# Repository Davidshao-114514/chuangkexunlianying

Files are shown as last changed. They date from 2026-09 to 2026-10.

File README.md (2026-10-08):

# 磁吸焊接辅助手电 · 开源学习包

> 一个「从零到整机」的嵌入式硬件学习包：**不是又一块开发板，而是一个完整产品**
> 一吸即用、指哪照哪的焊接照明工具 —— 硬件 + 固件 + 结构 + 测试，全链路开源。





---

## 这是什么？

一块常见的开发板（Arduino / 各类核心板）能教你**外设怎么用**：点亮 LED、读按键、刷屏、跑 PWM。
但学完之后，很多人仍然答不上这些问题：

- 电池设备为什么敢**不用稳压器**直接给 MCU 供电？那怎么测电池电压？
- 驱动芯片手册写「调光 100Hz–10kHz」，到底该选多少？选错会怎样？
- 按键只有 3 个，怎么覆盖 8 项功能？吸附检测为什么要 100ms 去抖而按键只要 15ms？
- 关机后怎么做到「按键唤醒 + 唤醒不花屏 + 松手不重启」？
- 断电后怎么记住上次亮度，又不会记住"过期的设置"？

**这个学习包就是这些问题的答案**——而且每一个答案都附带**真实踩坑过程**（`docs/08`）。
它把「磁吸焊接辅助手电」这个真实项目完整开源：从电源链路到 PWM 调光、
从磁吸检测到低功耗、从原理图到 3D 外壳，全部可复现。

### 与「传统开发板」的差别

| 维度 | 传统开发板 / Arduino | 本学习包 |
|---|---|---|
| 学习对象 | 单个外设 Demo | **完整产品链路**（电源→主控→输出→人机→结构） |
| 代码规模 | 示例 sketch / 单个 .c | **12 个 BSP 模块 + 1ms 分频调度**（Flash 12KB / RAM 1.1KB） |
| 硬件决策 | 板载已定，无需思考 | **每个决策都有理由**（电池直供、BGR 反推、8kHz、3 键、100ms 去抖） |
| 产出物 | 一个会闪的灯 | **一台能用的整机**（含外壳、按键帽、装配、测试表） |
| 复现成本 | 低价但要买全套模块 | **BOM ≈ ¥45 级**，通用件 + 3D 打印结构 + 驱动可 pin-to-pin 替换 |
| 工程习惯 | 少涉及 | 低功耗时序、去抖、抗噪、掉电记忆、状态机、可维护分层 |
| 真实经验 | 很少有踩坑记录 | **完整踩坑实录**（OLED 四轮点亮、ADC 三段排查、频率五次迭代…） |
| 教学适配 | 课程实验 | **项目式学习**：8 个学习模块、检查点、验收判据 |

> 一句话：**开发板教你「怎么用芯片」，这个学习包教你「怎么做产品」。**

---

## 快速开始

```text
1. 阅读   docs/01-为什么做这个学习包.md     ← 先看这里（5 分钟）
2. 概览   docs/系统框图.png                 ← 一张图看懂整机
3. 硬件   docs/03-硬件设计说明.md           ← 供电/引脚/磁吸接口/BOM
4. 固件   docs/04-固件架构说明.md           ← 模块划分、按键语义、调度、低功耗
5. 踩坑   docs/08-开发踩坑实录.md           ← 强烈建议先读（省几周时间）
6. 动手   docs/05-复现指南.md               ← 采购→打样→焊接→烧录→调试
7. 验收   docs/06-测试与验收.md             ← 指标与测试方法
```

**编译烧录（两种型号，一行宏切换）：**

```c
/* USER/inc/app_config.h */
#define APP_PRODUCT_VARIANT   PRODUCT_VARIANT_EXTERNAL   /* 外挂款：磁吸 LED + 吸附检测 */
/* 或 */                    /* PRODUCT_VARIANT_BUILTIN —— 内置款：内置 LED，无需检测 */
```

Keil MDK5 + **Arm Compiler 6**（需装 `WHXY.CW32L010_DFP 1.0.2`）打开 `MDK/Project.uvprojx`
→ 改宏 → 编译（预期 ≈12KB Flash / ≈1.1KB RAM）→ SWD 烧录 → 上电自检。

---

## 仓库结构

```text
├── USER/                     应用固件（分层 BSP，重点学习对象）
│   ├── inc/                  bsp_pin.h（引脚唯一映射）/ app_config.h（型号开关）/ …
│   └── src/                  main.c（按键状态机/电池状态机/UI）
│                             bsp_pwm.c（8kHz 6000 级双路调光）
│                             bsp_detect.c（磁吸检测 100ms 去抖）
│                             bsp_power.c（STOP 休眠 + 上升沿唤醒）
│                             bsp_save.c（Flash 亮度记忆 + RTC 1h 窗口）
│                             bsp_adc.c（BGR 反推电压）/ bsp_oled.c（CH1115 88×48）/ …
├── MDK/                      Keil MDK5 工程（Project.uvprojx）
├── 工程文件夹/
│   ├── UserApp/              完整工程（含标准库 + DEVELOPMENT_SUMMARY.md 开发总结）
│   ├── BOM_TYPE-A_PCB2_*.xlsx   物料清单（34 行 / 56 位号）
│   ├── TYPE-A.epro2          立创EDA 专业版工程（原理图 + PCB）
│   ├── CW32L010.pdf          主控数据手册
│   └── 3D外壳/               外壳 / 盖子 / 按键帽 / 散热片（STEP + SolidWorks 源）
├── docs/                     学习文档（本学习包核心）
└── LICENSE                   MIT
```

---

## 硬核参数（都能在文档里找到依据与踩坑过程）

| 项目 | 参数 | 出处 |
|---|---|---|
| 主控 | CW32L010F8（Cortex-M0+，TSSOP-20，64KB Flash / 4KB RAM），HSI 48MHz | `docs/03` §3 |
| 供电 | **锂电池直供 MCU**（无稳压器、无外部晶振）；CE 控制 3V3 轨（磁吸口） | `docs/03` §2 |
| 调光 | 双路独立 PWM，**8kHz**，**6000 级**（ARR=5999），软件千分比，步进 0.5%，下限 3% | `docs/04` §3 |
| 驱动 | **RY3730 ×2**（pin-to-pin 可换 SY7200），手册推荐 100Hz–10kHz | `docs/03` §6 |
| 磁吸接口 | 4pin/组：3V3 / GND / LED− / **DET**；吸附才点亮，**脱落即灭** | `docs/03` §4 |
| 吸附检测 | PA01/PA00（复用 OSC±），**100ms 去抖**（按键只需 15ms） | `docs/03` §4.3 |
| 按键 | **3 键**（PB03 开关机 / PA04 亮度− / PA05 亮度+），高有效（外部下拉） | `docs/04` §2 |
| 交互 | 单击 / 长按（≥300ms，三段加速）/ 双击（≤350ms，切对象·切模式） | `docs/04` §2 |
| 电量 | **无外部电路**：内部 BGR 1.2V 反推 VDD + 成对交替采样 + IIR | `docs/03` §5 |
| 电池保护 | LOW <3350mV（回 3400 解除）/ PROTECT <3200mV 关断，2s 确认 + 告警页 | `docs/04` §6 |
| 显示 | 0.5" **CH1115** 88×48，软件 I2C（PB05/PB06，地址 0x3C） | `docs/03` §7 |
| 掉电记忆 | Flash 第 127 页，两组亮度 + RTC 时间戳，**1 小时恢复窗口** | `docs/04` §7 |
| 低功耗 | 关机 = CE 断电 + STOP；PB03 **上升沿**唤醒 + 500ms 延迟初始化 + 吞咽窗口 | `docs/04` §5 |
| 资源占用 | Flash ≈12KB / RAM ≈1.1KB，编译 0 错 0 警告 | `docs/04` §10 |
| BOM | ≈ ¥45 级整机（PCBA 通用件 + 磁吸机构 + 3D 打印外壳） | `docs/03` §8 |

---

## 学习路径（8 个模块 + 踩坑实录）

| # | 模块 | 你会获得 | 文档 |
|---|---|---|---|
| 1 | 看懂整机与系统框图 | 电源域/主控域/输出域/人机域的分区思维 | [系统框图](docs/系统框图.png)、[硬件 §1](docs/03-硬件设计说明.md) |
| 2 | 电源链路与软开关 | 电池直供的取舍、CE 控 3V3、关机为何要 STOP | [硬件 §2](docs/03-硬件设计说明.md)、[固件 §5](docs/04-固件架构说明.md) |
| 3 | GPIO 与按键语义 | 高有效 + 外部下拉、15ms 去抖、单击/长按/双击状态机 | [固件 §2](docs/04-固件架构说明.md) |
| 4 | PWM 与调光 | 8kHz/6000 级的推导、最低占空比下限为何是 3% | [固件 §3](docs/04-固件架构说明.md)、[硬件 §6](docs/03-硬件设计说明.md) |
| 5 | 磁吸检测与保护 | 复用引脚、100ms 去抖、"脱落即灭"的安全逻辑 | [固件 §4](docs/04-固件架构说明.md)、[硬件 §4](docs/03-硬件设计说明.md) |
| 6 | 采样与电池保护状态机 | BGR 绝对参考、成对采样、滞回阈值与告警 | [硬件 §5](docs/03-硬件设计说明.md)、[固件 §6](docs/04-固件架构说明.md) |
| 7 | 低功耗与掉电记忆 | 唤醒沿/消抖窗/延迟初始化、Flash 记忆时间窗 | [固件 §5 §7](docs/04-固件架构说明.md) |
| 8 | 结构、装配与测试 | 磁吸底座+按键帽装配、吸附力/漂移/温升验收 | [硬件 §9](docs/03-硬件设计说明.md)、[测试](docs/06-测试与验收.md) |
| ★ | **开发踩坑实录** | OLED 四轮点亮、ADC 三段排查、PWM 五次迭代、休眠四个连环坑 | [docs/08](docs/08-开发踩坑实录.md) |

---

## 共建共享（Contributing）

这个学习包**欢迎任何人改进**，无论你是学生、教师还是工程师：

- 🐛 **报问题 / 提建议**：开 Issue，说明环境与复现步骤
- 🔧 **提交改进**：Fork → 分支 → PR（详见 [CONTRIBUTING.md](CONTRIBUTING.md)）
- 📚 **分享你的扩展**：新外壳、新灯组、新交互、移植到别的 MCU——都欢迎
- 🎓 **教学复用**：教师/社团可直接把 [docs/07](docs/07-教学设计说明.md) 当课程包（含课时与检查点）
- 🧰 **留下你的坑**：把你的踩坑记录补进 [docs/08](docs/08-开发踩坑实录.md)——这比代码更珍贵

> 我们相信：**开源不是把代码扔出去，而是让别人能稳定复现、并能在此基础上继续走远。**
> 因此本项目对每个焊接步骤、每个参数都注明「为什么」，并把低成本复现作为硬指标。

---

## 许可

- 代码与文档：**MIT**（见 [LICENSE](LICENSE)）
- 硬件设计（原理图 / PCB / 结构）：MIT 同样适用；转载与二次发布请保留出处
- 引用到的第三方资源（主控数据手册、标准库、屏厂初始化序列）版权归原作者所有

---

## 致谢

- **指导老师**：提供 CW32L010 开发板与工程框架，本学习包的固件架构建立在其规范之上
- **仿真跑不队**：邵子中、李昊桐、姜亚楷 —— 硬件选型、结构设计、固件迭代与全部测试数据
- 以及每一位愿意在此基础上继续共建的人 ✦

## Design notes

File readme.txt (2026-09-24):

UserApp - CW32L010F8 应用框架
================================
基于 CW32L010 标准库例程 (参考 GPIO/gpio_blink 工程结构),
软件开关支持外挂款/内置款两种型号, 见 USER\inc\app_config.h。

型号区别 (烧录前修改 app_config.h 的 APP_PRODUCT_VARIANT, 重新编译):
  外挂款 EXTERNAL (默认):
    - 磁吸 4pin 外接 LED (3V3/GND/LED-/DET), 吸附检测: 高=已连接
    - 检测引脚: PA01(OSC-)=组1, PA00(OSC+)=组2 (无外部晶振, 复用 OSC)
    - 按键 5 个: PA02 PA04 PA05 PA06 PB03
    - 未吸附的组不输出 PWM (防空载)
  内置款 BUILTIN:
    - LED 内置于整机, 无检测 (视为已连接)
    - PA00/PA01 恢复为按键, 共 7 个: PA00 PA01 PA02 PA04 PA05 PA06 PB03

引脚分配 (原理图):
  PB04(CE)   = LDO 使能            -> bsp_pin.h / LDO_CE_Enable()
  PB05(SDA)  = OLED IIC SDA        -> bsp_i2c.c (软件I2C, 参考 H563 bsp_i2c)
  PB06(SCL)  = OLED IIC SCL
  PB07/NRST  = 系统复位 (OLED RST 与复位相连, 无需 GPIO)
  PB00(VBAT) = 电池电压采样 AIN7    -> bsp_adc.c
  PB01(PB1)  = PWM1, ATIM_CH2 -> 组1 (SY7200 EN/PWM, 20kHz, 2400级)
  PA03(PA3)  = PWM2, ATIM_CH3 -> 组2 (SY7200 EN/PWM)

系统: 无外部晶振, HSI 48MHz (SYSCTRL_HSIOSC_DIV1)
按键功能:
  外挂款: BTN1 开关机 / BTN2,3 亮度-+ / BTN4 分组切换 / BTN5 全部亮灭
  内置款: BTN1 开关机 / BTN2,3 亮度-+ / BTN4 分组切换 /
          BTN5 组1亮灭 / BTN6 组2亮灭 / BTN7 全部亮灭
关机: BTN1 使 LDO(CE) 断电并进入 STOP 停机模式, 任意按键唤醒恢复。

OLED 驱动由 H563 工程 bsp_oled/bsp_i2c 移植 (SSD1306 0.91" 128x64, 地址 0x3C)。

使用:
  用 Keil MDK5 打开 MDK\Project.uvprojx, F7 编译, 下载到 CW32L010F8 即可。
  切换型号: 改 app_config.h 一行 -> 重新编译烧录。

请注意: 编译前确认已安装 WHXY.CW32L010_DFP 1.0.2 器件包 (Keil Pack Installer)。

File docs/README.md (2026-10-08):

# 学习文档索引

> 建议阅读顺序：**01 → 02 → 03/04 → 08 → 05 → 06 → 07**
> 只想快速复现的读者：先读 `08`（避开所有已知的坑），再跳到 `05`。

| 文档 | 内容 | 适合谁 |
|---|---|---|
| [01 为什么做这个学习包](01-为什么做这个学习包.md) | 从「开发板 vs Arduino 差距」得到的启发：项目式学习与低成本复现为什么重要 | 第一次打开本仓库的人 |
| [02 学习路径](02-学习路径.md) | 8 个学习模块，每模块的目标、材料、动手任务、检查点 | 自学 / 课程学习者 |
| [03 硬件设计说明](03-硬件设计说明.md) | 系统框图、供电（电池直供）、完整引脚表、磁吸 4pin、BGR 采样、BOM 与成本 | 硬件方向 / 复现者 |
| [04 固件架构说明](04-固件架构说明.md) | 12 个 BSP 模块、3 键复合语义、1ms 分频调度、8kHz 调光、检测、电池保护、掉电记忆、低功耗 | 嵌入式方向 / 复现者 |
| [05 复现指南](05-复现指南.md) | 采购→打样→焊接→烧录→自检→**整合真实踩坑的排错表** | 所有动手的人 |
| [06 测试与验收](06-测试与验收.md) | 14 项指标的测试方法与合格判据、验收记录表模板 | 复现后的验收 / 教学评分 |
| [07 教学设计说明](07-教学设计说明.md) | 课时安排、教学检查点、评分建议、常见教学陷阱 | 教师 / 社团讲师 |
| [08 开发踩坑实录](08-开发踩坑实录.md) | **真实迭代过程**：OLED 四轮点亮、ADC 三段排查、PWM 五次迭代、休眠四个连环坑 + 速查表 | 所有人（强烈推荐先读） |

## 图片与工具索引

| 资源 | 说明 |
|---|---|
| [系统框图](系统框图.png) | 整机四个域（电源/主控/输出/人机）与信号流向 |
| 3D 外壳 | `工程文件夹/3D外壳/`（外壳 / 盖子 / **按键帽** / 散热片；STEP 可直接切片） |
| 原理图 / PCB | `工程文件夹/TYPE-A.epro2`（立创EDA 专业版） |
| 开发总结 | `工程文件夹/UserApp/DEVELOPMENT_SUMMARY.md`（最终硬件配置与开发历程原文） |
| [开源前置检查.py](开源前置检查.py) | 提交前扫描敏感信息（凭据/学号/文档 ID），在仓库根目录运行 |

## 术语速查

| 缩写 | 含义 | 出现位置 |
|---|---|---|
| BSP | Board Support Package，板级支持层（硬件操作都收在这一层） | `USER/src/bsp_*.c` |
| DET | Detection，磁吸吸附检测引脚 | 硬件 §4 / 固件 §4 |
| ATIM | Advanced Timer，CW32 高级定时器（两路 PWM 源，8kHz） | 固件 §3 |
| CE | Chip Enable，PB04 控制 3V3 轨（磁吸口供电） | 硬件 §2 / 固件 §5 |
| **BGR** | Band Gap Reference，内部 1.2V 基准（用于反推电池电压） | 硬件 §5 / 固件 §6 |
| **CH1115** | 0.5" 88×48 显示屏控制器（不兼容 SSD1306 的 0x8D 命令） | 硬件 §7 |
| **LSI / RTC** | 内部低速时钟 / 实时时钟（用于亮度记忆的时间窗） | 固件 §7 |
| **TGT / G1 / G2** | 屏上显示的「当前调节对象 / 组1 / 组2」状态 | 固件 §2 |
| STOP | 停机模式（CPU 停止，GPIO 中断可唤醒） | 固件 §5 |
| DIM_MIN_PERMILLE | 亮度下限宏（默认 30 = 3%，低于会频闪） | 固件 §2 / §3 |

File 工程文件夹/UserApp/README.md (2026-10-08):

# CW32L010 UserApp - 磁吸 LED 灯控固件框架

基于 **武汉芯源 CW32L010F8** (Cortex-M0+, TSSOP20, 64KB Flash / 4KB RAM) 的完整应用框架，
Keil MDK5 (uVision) + **AC6 (ARMCLANG)** 编译，所有外设时钟来自 **无源 HSI 48MHz**（无外部晶振）。

## 功能特性

- **HSI 48MHz 单时钟**：`SYSCTRL_HSIOSC_DIV1`，HSE/LSE 不使用，OSC 引脚复用为检测口
- **双组 PWM 调光**：ATIM_CH2(PB01) / ATIM_CH3(PA03)，8kHz，6000 级，适配 RY3730 EN/PWM (100Hz~10kHz)
- **0.5" OLED**：CH1115 **88x48** (6 页)，软件 I2C (PB05/PB06)，驱动自 H563 工程移植
- **磁吸 4pin 外接 LED 吸附检测**（外挂款）：复用 OSC- (PA01)/OSC+ (PA00)，高电平=已吸附；未吸附禁止输出
- **电池电压监测**：PB00 = ADC_IN7，**10K/10K 分压 (VBAT/2)**，50ms 采样 + 8 次均值
- **软件过放保护**：<3.5V 低电提醒（告警页/闪烁）；<3.2V 关断输出；2s 确认 + 滞回 (3.55/3.35V) 防振荡；告警页可按键关屏，1 分钟无操作自动关屏省电
- **低功耗**：关机 → LDO(CE) 断电 + STOP 停机（GPIO 下降沿唤醒），任意按键唤醒自动恢复
- **双型号软件开关**：`app_config.h` 一行切换 外挂款 / 内置款

## 完整引脚关系图

### 1. 总体拓扑

```
 电池 V+/V- ────────────────────────────────────────────────────────────┐
     │                                                                 │
     ├─[10K]──┐                                                        │
     │        └──────────┐   VBAT/2  (采样点)                          │
     └────────[10K]──GND──┤    │                                       │
                          ▼    ▼                                       │
      ┌────────────────────────────────────────────────────────────┐  │
      │                    CW32L010F8 (TSSOP20)                    │  │
      │          HSI 48MHz / 内核 / 无外部晶振                      │  │
      │  PB00 ADC_IN7 ←──(10K/10K 分压采样)─────────────────────────┼──┘
      │    PA01(OSC-) ◄── DET1 磁吸接口1 检测线 ────────────────────┼─▶ 3.3V(灯端)
      │    PA00(OSC+) ◄── DET2 磁吸接口2 检测线 ────────────────────┼─▶ 3.3V(灯端)
      │    PB01 ATIM_CH2 ── PWM 低边开关 ──▶ LED1-〔SY7200 EN/PWM〕 ┼─▶ 组1 LED
      │    PA03 ATIM_CH3 ── PWM 低边开关 ──▶ LED2-〔SY7200 EN/PWM〕 ┼─▶ 组2 LED
      │    PB04 CE ──▶ LDO 使能 (LDO→3.3V 输出/或直接给灯组供电)     │
      │    PB05 SDA ────▶ OLED CH1115 (0.5", 88x48, I2C 0x3C)    │
      │    PB06 SCL ────▶                                        ▲  │
      │    PB07/NRST ────▶ OLED RST (并联系统复位)                 │  │
      │    PA02 PA04 PA05 PA06 PB03 ── 按键(外部上拉, 按下为低)     │  │
      │    (内置款: +PA00 PA01 作按键)                              │  │
      │    PA07/PA08 ── SWDIO/SWCLK 调试口                          │  │
      └────────────────────────────────────────────────────────────┘
```

### 2. MCU 引脚全表 (TSSOP20)

| 引脚 | 名称 | 功能 | 接口 (原理图丝印) | 方向/配置 |
|---|---|---|---|---|
| 1 | PB04 | LDO 使能 | CE | 输出 PP，有效电平可配 |
| 2 | PB05 | OLED SDA | SDA | 软件 I2C，开漏+上拉 |
| 3 | PB06 | OLED SCL | SCK (丝印) | 软件 I2C，开漏+上拉 |
| 4 | PB07/NRST | 系统复位 | RST (OLED RST 并联) | 复位输入 |
| 5 | PA00 | OSC+ | 外挂款=DET2 / 内置款=按键 | 输入(外部下拉)/上拉输入 |
| 6 | PA01 | OSC- | 外挂款=DET1 / 内置款=按键 | 输入(外部下拉)/上拉输入 |
| 7 | VSS | 地 | — | — |
| 8 | Vcore | 稳压器输出 | C13/C11 100nF+1uF | — |
| 9 | VDD | 电源 | 3.3V | — |
| 10 | PA02 | 按键 BTN1 | — | 上拉输入, 按下低 |
| 11 | PB00 | 电池采样 | VBAT | ADC_IN7, 10K/10K |
| 12 | PB01 | PWM1 输出 | PB1 | ATIM_CH2 → SY7200 EN (组1) |
| 13 | PA03 | PWM2 输出 | PA3 | ATIM_CH3 → SY7200 EN (组2) |
| 14 | PA04 | 按键 BTN2 | — | 上拉输入, 按下低 |
| 15 | PA05 | 按键 BTN3 | — | 上拉输入, 按下低 |
| 16 | PA06 | 按键 BTN4 | — | 上拉输入, 按下低 |
| 17 | PA07/SWDIO | 调试 | — | SWDIO |
| 18 | PA08/SWCLK | 调试 | — | SWCLK |
| 19 | PB02 | 未使用 | X (原理图叉掉) | — |
| 20 | PB03 | 按键 BTN5 | — | 上拉输入, 按下低 |

### 3. 磁吸 4pin 接口 (每灯组一个, 共 X2)

```
 磁吸接口(组1)              磁吸接口(组2)
 ┌──────────┐                ┌──────────┐
 │ ① 3V3    │──3.3V─        │ ① 3V3    │──3.3V─
 │ ② GND    │──GND──        │ ② GND    │──GND──
 │ ③ LED-   │──PWM1(PB01)── │ ③ LED-   │──PWM2(PA03)──▶ SY7200 EN/PWM
 │ ④ DET    │──PA01(OSC-)── │ ④ DET    │──PA00(OSC+)──▶ 检测输入
 └──────────┘                └──────────┘
   灯端接线: ① 3V3 ─▶ LED+ / DET(内部短接3V3)     ← 吸附后 DET 检测线被拉高
             ④ DET ▲ 线侧下拉电阻(如10K)到 GND     ← 未吸附时 DET = 低电平
             ③ LED- ◀─ SY7200 EN/PWM 低边开关     ← 20kHz PWM 调光
```

### 4. 器件级接线说明

| 器件 | 接口 | 说明 |
|---|---|---|
| OLED (CH1115 0.5") | SCL=PB06, SDA=PB05, RST=PB07/NRST | 软件 I2C @~100kHz, 地址 0x3C; 88x48 4 页 |
| LED (经 SY7200) | EN/PWM = PB01/PA03 | 8kHz, 6000 级; PWM 高=亮 |
| 磁吸 DET | PA00/PA01, 外部下拉 + 灯端 3.3V | 高=已吸附; 未吸附组不输出 |
| LDO | CE = PB04 | 关机断电 (GPIO 即可/有效电平 CE_ACTIVE_LEVEL 可配) |
| 电池采样 | PB00 + 10K/10K | VBAT/2, 测限 6.6V |
| 按键 | PA02/PA04/PA05/PA06/PB03 (+PA00/PA01 内置款) | 内部上拉, 按下低; 作 STOP 唤醒 |
| 调试 | PA07(SWDIO)/PA08(SWCLK) | SWD 烧录/调试 |

## 软件开关：外挂款 / 内置款

`USER/inc/app_config.h`：

```c
#define APP_PRODUCT_VARIANT   PRODUCT_VARIANT_EXTERNAL   // 外挂款 (默认)
#define APP_PRODUCT_VARIANT   PRODUCT_VARIANT_BUILTIN    // 内置款
```

| | 外挂款 | 内置款 |
|---|---|---|
| 吸附检测 | 启用 (PA00/PA01) | 无（视为已连接） |
| 按键 | 5 个：PA02 PA04 PA05 PA06 PB03 | 7 个：+PA00 PA01 |
| 按键功能 | 1:PWR 2/3:亮度∓ 4:分组 5:全亮灭 | 同左 +5:G1亮灭 6:G2亮灭 7:全亮灭 |
| 界面 | 显示 D1/D2 吸附检测 | 显示 CUR 当前组 |

## 软件架构（参考 STM32H563 工程分层）

```
Main Loop ── OLED 界面刷新 (UI_StaticInit / UI_RefreshValues)
     ▲
BTIM1 1ms 中断 (interrupts_cw32l010.c)
   ├─ 1ms  系统时基 / 告警页自动关屏倒计时
   ├─ 5ms  按键扫描 / 吸附检测 / 输出联动
   ├─ 50ms VBAT 采样 + 电池保护状态机
   └─ 200ms 界面刷新请求
```

| 文件 | 职责 |
|---|---|
| `USER/src/main.c` | 初始化、电池保护状态机、按键逻辑、OLED 界面内容 |
| `USER/src/bsp_power.c` | STOP 休眠 + 按键唤醒 |
| `USER/src/bsp_timer.c` | BTIM1 1ms 时基 |
| `USER/src/bsp_pwm.c` | ATIM 20kHz PWM / 2400 级调光 |
| `USER/src/bsp_adc.c` | VBAT 分压采样 (10K/10K) |
| `USER/src/bsp_button.c` | 按键扫描 (去抖 15ms) |
| `USER/src/bsp_detect.c` | 磁吸吸附检测 (100ms 去抖) |
| `USER/src/bsp_i2c.c` | 软件 I2C (OLED) |
| `USER/src/bsp_oled.c` | SSD1306 显示原语 (6x8 ShowStr) |
| `CW32L010_Lib/` | 内嵌 CW32L010 标准库 (Libraries/startup/retarget) |

## 构建与烧录

1. Keil MDK **Pack Installer** 安装 `WHXY.CW32L010_DFP 1.0.2`（MDK 5.35+）
2. 打开 `MDK/Project.uvprojx` → F7 编译（AC6 / ARMClang）
3. 连接 SWD (PA07/PA08) 下载；低功耗演示需接电池 + 磁吸灯

程序体积约：Code 8.1KB / RO 1.0KB / RAM 1.1KB（Flash ~14%，RAM ~27%）。

## 版本

- v1.0: 首版框架（PWM/OLED/按键/检测/保护/低功耗/双型号）

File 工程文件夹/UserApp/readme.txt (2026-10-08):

UserApp - CW32L010F8 应用框架
================================
基于 CW32L010 标准库 (内嵌 CW32L010_Lib), 详细说明见 README.md。

引脚关系 (TSSOP20):
  1  PB04(CE)   -> LDO 使能
  2  PB05(SDA)  -> OLED IIC SDA (软件I2C)
  3  PB06(SCK)  -> OLED IIC SCL
  4  PB07/NRST  -> 系统复位/OLED RST
  5  PA00(OSC+) -> 外挂款: 磁吸组2检测 / 内置款: 按键BTN6
  6  PA01(OSC-) -> 外挂款: 磁吸组1检测 / 内置款: 按键BTN7
  10 PA02       -> 按键 BTN1 (开关机)
  11 PB00(VBAT) -> 电池采样 ADC_IN7 (10K/10K 分压 VBAT/2)
  12 PB01(PB1)  -> PWM1: ATIM_CH2 -> SY7200 EN (磁吸组1 LED-)
  13 PA03(PA3)  -> PWM2: ATIM_CH3 -> SY7200 EN (磁吸组2 LED-)
  14 PA04       -> 按键 BTN2 (亮度-)
  15 PA05       -> 按键 BTN3 (亮度+)
  16 PA06       -> 按键 BTN4 (分组切换)
  17/18 PA07/PA08 -> SWDIO/SWCLK 调试
  19 PB02       -> 未使用 (原理图 X)
  20 PB03       -> 按键 BTN5 (全部亮灭, 内置款: 组1亮灭+6组2+7全部)

磁吸 4pin (每灯组一个): ① 3V3 ② GND ③ LED-(PWM低边) ④ DET(灯端3V3, 线侧下拉10K, 高=已吸附)

系统: 无外部晶振, HSI 48MHz; OLED 0.5" CH1115 88x48 (6页, 6x8字体)
型号切换: USER/inc/app_config.h (外挂款/内置款)
过放保护: <3.5V告警, <3.2V关断, 滞回+2s确认; 告警页按键关屏/1分钟自动关屏
关机低功耗: BTN1 断电+STOP, 任意按键唤醒

编译: Keil MDK5 + AC6, 需安装 WHXY.CW32L010_DFP 1.0.2

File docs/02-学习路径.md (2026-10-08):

# 02 · 学习路径（8 个模块 + 踩坑复盘）

> 每个模块 4 段结构：**目标 → 读什么 → 动手做什么 → 检查点（怎么算过关）**
> 全部模块预计 **16–24 学时**；只做软件（用已焊好的板）需 **10–12 学时**。

---

## 模块 1 · 看懂一台整机（1–2 学时）

**目标**：建立「整机分区」思维：电源域 / 主控域 / 输出域 / 人机域。

**读什么**：`系统框图.png`、`03-硬件设计说明.md` §1。

**动手**：打开 `工程文件夹/TYPE-A.epro2`（立创EDA），把元件按四个域归类，自己画一张框图。

**检查点**：
- 能说出四个域各含哪些元件；
- 能指出电池 → MCU 的供电路径，以及 3V3 轨给谁供电；
- 能说出两组 LED 分别由哪两个引脚驱动。

---

## 模块 2 · 供电与软开关（2–3 学时）

**目标**：理解「电池直供 MCU + CE 控 3V3 轨」为什么不加 LDO，以及这么做的代价。

**读什么**：`03` §2、`04` §5、`08` §3.2。

**动手**：
1. 万用表测：电池电压（VBAT）、开机时 3V3 轨电压、关机后 3V3 轨电压；
2. 在代码里找到 CE 控制（`bsp_pin.h` 的 `LDO_CE_Enable/Disable`），观察关机时它被拉低；
3. 关机后测整机静态电流，与开机态对比。

**检查点**：
- 能解释「为什么电池直供会破坏分压测压法」；
- 能说出 CE 控制的到底是什么（3V3 轨 → 磁吸口），不是什么（MCU 供电）；
- 记录：开机电流 / 关机电流，两者应有数量级差异。

---

## 模块 3 · 按键与复合语义（2 学时）

**目标**：掌握「高有效输入 + 去抖 + 单击/长按/双击状态机」。

**读什么**：`04` §2、`USER/src/bsp_button.c`、`main.c` 按键状态机部分。

**动手**：
1. 把去抖阈值改到 2ms，快速抖动按键，复现误触发，再改回 15ms；
2. 实测两种复合操作：长按 PA05（观察三段加速）、双击 PA04（观察屏上 `TGT` 切换）；
3. 把单击/长按的判定时间改一改，理解「手感」是怎么被参数决定的。

**检查点**：
- 能解释「高有效 + 外部下拉」与「低有效 + 内部上拉」的差别，以及本项目为何选前者；
- 能说明三段加速的用意（短促调节精细、长按快速跨越）；
- 3 键的全部功能（含双击）都能正确触发。

---

## 模块 4 · PWM 与无级调光（2–3 学时）

**目标**：理解频率、分辨率、最低占空比的三角权衡。

**读什么**：`04` §3、`03` §6、`08` §3.3。

**动手**：
1. 推导：48MHz / 8kHz = 6000 级（ARR=5999）；
2. 把频率改成 1kHz 与 20kHz 各试一次，用手机摄像头拍灯对比（条纹/闪烁）；
3. 把亮度下限宏 `DIM_MIN_PERMILLE` 从 30（3%）改到 0，观察最低亮度是否频闪。

**检查点**：
- 能说明「为什么最终是 8kHz」——不是越高越好，而是驱动手册推荐区间（100Hz–10kHz）；
- 手机拍摄 8kHz 无可见条纹；1kHz 时可见（证明判据有效）；
- 能解释「为什么需要亮度下限」，并复现下限以下的现象。

---

## 模块 5 · 磁吸检测与安全联动（2–3 学时）

**目标**：掌握「复用引脚 + 100ms 去抖 + 状态联动」。

**读什么**：`04` §4、`USER/src/bsp_detect.c`、`03` §4。

**动手**：
1. 吸附/取下灯组，观察屏上吸附状态与灯光联动；
2. 把检测去抖时间改到与按键相同（15ms），反复快速吸合，观察是否出现误判闪烁；
3. 灯组点亮时拔下（模拟脱落），确认**立即熄灭**。

**检查点**：
- 能画出一组磁吸 4pin 接线并解释 DET 的上下拉关系；
- 能解释「未吸附不输出」是硬件保护（避免空载与异常驱动）；
- **能说明为什么检测去抖（100ms）要比按键（15ms）长得多**（磁吸撞击的机械稳定时间更长）。

---

## 模块 6 · 采样与电池保护状态机（2–3 学时）

**目标**：从「比例测量失效」到「BGR 绝对参考」，再到完整的过放保护状态机。

**读什么**：`03` §5、`04` §6、`08` §3.2。

**动手**：
1. 用稳压源给 3.3 / 3.7 / 4.2V，核对屏上 mV 显示误差（目标 ≤ ±3%）；
2. 缓慢下调电压，记录 LOW 告警与 PROTECT 关断的触发点（期望 3.35V / 3.2V）；
3. 缓慢回升，验证滞回解除（3.40V / 3.35V）；
4. 快速抖动电压跨越阈值，确认 2s 连续确认逻辑生效（不被瞬态触发）。

**检查点**：
- 能解释「VBAT 直供 → 分压与参考同源 → 比例测量失效」的因果链；
- 能说明 BGR、成对交替采样、IIR 平滑各自解决什么问题；
- 过放保护的**阈值 / 滞回 / 确认时间**三个参数都能说出（并知道为什么要滞回）。

---

## 模块 7 · 低功耗与掉电记忆（2–3 学时）

**目标**：会做「关得掉、唤得醒、记得住」的产品级电源管理。

**读什么**：`04` §5 §7、`USER/src/bsp_power.c`、`bsp_save.c`、`08` §3.4。

**动手**：
1. 关机测静态电流；按 PB03 唤醒，确认屏正常（不花屏）；
2. 长按开机按钮再松手，观察是否被误判为「又关一次」（吞咽窗口在起作用）；
3. 把两组亮度调到明显不同（如 20% / 60%），关机→立刻开机，验证恢复；
4. 把恢复窗口宏改小（如 10 秒），验证「超窗口 → 回到默认 10%」。

**检查点**：
- 能说出低功耗的四个坑（唤醒沿方向、唤醒时序、按键回弹、PB03 供电）及各自解法；
- 能解释唤醒后为什么需要延迟初始化（防上电随机亮点）；
- 能说明 Flash 记忆的「时间窗」设计为什么优雅（无需显式清除过期数据）。

---

## 模块 8 · 结构、装配与验收（2–3 学时）

**目标**：把「能用」变成「好用且可复现」。

**读什么**：`03` §9、`06-测试与验收.md`、`工程文件夹/3D外壳/`。

**动手**：
1. 打印外壳 + **按键帽**（STEP 直接切片），装配 PCBA 与磁吸底座；
2. 按 `06` 的 14 项判据逐项测试并填写记录表；
3. 小组互测：交换样机，用同一判据复测，对比数据差异。

**检查点**：
- 吸附力达到设计下限，悬停不滑落；
- 连续工作温升在安全范围；
- 验收记录表条件、原始数据、结论三要素齐全。

---

## 模块 9（★）· 踩坑复盘（1–2 学时，强烈建议）

**目标**：把别人的坑变成自己的经验——这是本学习包**最值钱的一节**。

**读什么**：`08-开发踩坑实录.md`（全文）。

**动手**：
1. 挑一个坑（如 ADC 三段排查），用自己的话复述「现象 → 假设 → 验证 → 结论」；
2. 在自己的板子上**人为复现**其中一个坑（如把检测下拉电阻拆掉观察灯闪）；
3. 写一条属于你自己的踩坑记录（按 `08` 的表格格式），提交 PR 补充进文档。

**检查点**：
- 能讲清至少 3 个坑的根因（不是背答案，而是理解因果）；
- 能说明「为什么同一个参数（去抖时间/频率）不能一套用到所有地方」；
- 提交了至少 1 条自己的踩坑记录。

---

## 附录 · 常见学习误区

| 误区 | 正确认识 |
|---|---|
| 「代码能跑就行」 | 12 个 BSP 模块分层的目的：**别人能看懂、能改、能移植** |
| 「PWM 频率越高越好」 | 要看驱动手册推荐区间（本项目 8kHz 就是权衡结果） |
| 「电池电压分压就能测」 | 电池直供时比例测量失效，必须用 BGR 等**绝对参考** |
| 「按键都用内部上拉」 | 高阻节点会耦合 PWM 噪声 → 本项目改用**外部下拉 + 高有效** |
| 「去抖时间统一就行」 | 按键 15ms、磁吸 100ms——**去抖时间由物理过程决定** |
| 「功耗以后再说」 | 电池设备的待机电流决定产品能不能成立（分压电阻就吃掉 210µA） |
| 「踩坑不写下来」 | 本包 `08` 的价值高于代码——同一个坑第二次踩才是真浪费 |

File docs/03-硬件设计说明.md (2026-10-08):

# 03 · 硬件设计说明

> 数据来源：`工程文件夹/TYPE-A.epro2`（立创EDA）、`BOM_TYPE-A_PCB2_*.xlsx`、
> `USER/inc/bsp_pin.h`（引脚总表）、`USER/App DEVELOPMENT_SUMMARY.md`（最终硬件配置）。
> 本文只讲**为什么**——元件参数请对照原理图与 BOM。

---

## §1 系统分区概览

| 域 | 包含 | 一句话职责 |
|---|---|---|
| **电源域** | TYPE-C 输入、充电/升压管理、锂电池、3V3 轨（外挂磁吸口供电） | 让整机「有电、可充、可关断」 |
| **主控域** | CW32L010F8（**VBAT 直供**）、1ms 时基、复位/调试口 | 决策与调度中心 |
| **输出域** | 双路 PWM → RY3730 恒流驱动 → 两组 LED；磁吸 4pin 接口 | 把电变成「可用的光」 |
| **人机域** | 3 个按键、0.5" CH1115 屏 | 接受操作、反馈状态 |

设计原则：**每个域只通过少数几条线交互**，任何一部分都可单独替换或升级。

---

## §2 电源与供电设计（本项目最特殊的一处）

```text
TYPE-C 6P ─▶ 充电/升压管理（含电量指示）─▶ 18650 锂电池
                                              │
                          ┌───────────────────┴────────────────────┐
                          ▼                                        ▼
                 MCU 直接由 VBAT 供电                    3V3 轨（CE=PB04 控制）
                 （无稳压器 · 无外部晶振）                 └─▶ 外挂款磁吸口灯端供电
```

**三个反常识的设计决策（都来自实测）：**

1. **为什么 MCU 由电池直接供电，不加 LDO？**
   CW32L010F8 工作电压范围覆盖锂电区间；去掉 LDO 省元件、省静态电流、省板面积。
   **代价**：不能再用「电源分压 + 同源参考」的方式测电压（见 §5 与 `docs/08` §3.2）。

2. **为什么还要保留 CE（PB04）？**
   CE 控制 **3V3 轨**（外挂款磁吸口的灯端供电）。
   关机时拉低 CE，磁吸口彻底断电——**外接 LED 不耗电、也不会误亮**；
   MCU 自身则进 **STOP** 深度休眠（见 `docs/04` §5）。

3. **为什么按键改成「高电平有效 + 外部下拉」？**
   最终硬件把按键节点做了**低阻下拉**。原因：PWM 开启后，高阻节点会耦合噪声导致误触；
   下拉电阻改小后误触消失。软件侧相应地把有效电平配置为**高有效**
   （`bsp_button` 提供有效电平宏）。

> ⚠️ 复现提示：**"低有效 + 内部上拉"与"高有效 + 外部下拉"是两套完全不同的配置**，
> 抄代码前先确认你的板子是哪种；改错的现象是"按键一直被认为按下"或"完全无响应"。

---

## §3 引脚分配总表（CW32L010F8 · TSSOP-20 · 最终版）

| 引脚号 | MCU 引脚 | 功能 | 备注 |
|---|---|---|---|
| 1 | PB04 | **CE**：3V3 轨使能（外挂磁吸口供电） | GPIO 输出 |
| 2 | PB05 | 屏 IIC **SDA** | 软件 IIC |
| 3 | PB06 | 屏 IIC **SCL** | 软件 IIC（丝印 SCK） |
| 4 | PB07 / NRST | 系统复位 / 屏 RST | 不作按键 |
| 5 | PA00 (OSC+) | 外挂款：**磁吸组2检测** ／ 内置款：按键 | 复用 OSC 引脚 |
| 6 | PA01 (OSC−) | 外挂款：**磁吸组1检测** ／ 内置款：按键 | 复用 OSC 引脚 |
| 10 | PA02 | 按键（内置款多键配置下使用） | |
| 11 | PB00 (VBAT) | 电池采样位（**最终版改用内部 BGR 反推，10K/10K 分压已拆除**） | 见 §5 |
| 12 | PB01 | **PWM1** = ATIM_CH2 → 组A 驱动 EN | 低边/EN 调光 |
| 13 | PA03 | **PWM2** = ATIM_CH3 → 组B 驱动 EN | 低边/EN 调光 |
| 14 | PA04 | 按键 **亮度 −** | 高有效（外部下拉） |
| 15 | PA05 | 按键 **亮度 +** | 高有效（外部下拉） |
| 16 | PA06 | 按键（内置款多键配置下使用） | |
| 17 / 18 | PA07 / PA08 | SWDIO / SWCLK | 调试口 |
| 19 | PB02 | 未使用（原理图标 X） | |
| 20 | PB03 | 按键 **开关机**（含休眠唤醒） | 高有效；唤醒沿 = **上升沿** |

**两条设计要点：**

- **不用外部晶振**：HSI 48MHz 满足需求，省 2 元件 2 引脚，并把 OSC± 释放给检测/按键；
- **按键数收敛到 3 个**（PB03 / PA04 / PA05）：功能靠「单击 / 长按 / 双击」复合语义承载，
  省引脚、省结构孔位、省 BOM（详见 `docs/04` §2）。

---

## §4 磁吸 4pin 接口与吸附检测（招牌设计）

### 4.1 接口定义（每灯组一个）

| 线序 | 名称 | 说明 |
|---|---|---|
| 1 | **3V3** | 板侧输出（受 CE 控制），供灯端使用 |
| 2 | **GND** | 地 |
| 3 | **LED−** | LED 灯条负极，由 PWM（EN）驱动 |
| 4 | **DET** | 检测线：灯端把 3V3 接到 DET，吸附后把板侧检测点拉高 |

### 4.2 检测原理

> 板侧 DET 有**下拉**（未吸附 = 低）；灯端 3V3 接 DET（吸附 = 高）。
> MCU 读到高 → 允许输出；读到低 → **切断该路 PWM**。

```c
/* 外挂款：输出 = 电源 ON × 组点亮 × 亮度 × 已吸附 */
d = (g_power_on && grp.on && det) ? grp.brightness : 0;
```

### 4.3 去抖要求（与按键不同！）

吸附检测的**机械抖动比按键更剧烈**（磁铁吸合有撞击、接触弹跳），
本项目最终采用 **100ms 去抖窗口**（按键只需 15ms）。

> 💡 学习点：**去抖时间要按物理过程定**，不能一套参数用到底：
> 磁吸撞击的稳定时间远长于人手按键。

### 4.4 三个收益

1. **安全**：灯组脱落即灭，避免开路/短路异常；
2. **交互自然**：吸上就亮、取下就灭；
3. **可诊断**：吸附状态显示在屏上，能区分"灯坏"与"没吸好"。

---

## §5 电池电压采样（本项目最大的技术坑）

**最终方案：无外部电路，用内部 BGR（1.2V 基准）反推 VDD。**

```c
VBAT ≈ BGR × 4095 / raw_bgr      /* BGR 通道与待测通道成对采样 */
```

| 方案 | 问题 | 结论 |
|---|---|---|
| VBAT 直供 + 外部 10K/10K 分压 | 分压比与 ADC 参考同源 → **比例测量失效**（读数恒定） | ❌ |
| 分压 + 独立参考 | 可分压电阻**常通耗电 ~210µA** | ❌（电池设备不可接受） |
| **内部 BGR 反推 VDD** | 需要一个绝对参考 | ✅ 最终方案 |

配套三项措施（都在源码里）：
1. **成对交替采样**（BGR 通道与电池通道交替读，消除 LED 亮灭引起的漂移）；
2. **IIR 平滑**（抑制 PWM 引起的电源纹波）；
3. **BGR 仅测量时开启**（进一步省电）。

> ⚠️ 这是复现者最容易翻车的地方：**如果你的板子也是电池直供，别用分压法测电压。**
> 详见 `docs/08` §3.2 的三阶段排查过程。

---

## §6 输出级与调光参数

| 项 | 参数 | 说明 |
|---|---|---|
| 驱动芯片 | **RY3730 ×2**（可 pin-to-pin 替换 SY7200） | EN/PWM 调光 |
| 调光频率 | **8kHz**（ARR = 5999 → 6000 级） | 手册推荐区间 **100Hz–10kHz** 内 |
| 分辨率 | 6000 级（步进 1/6000 ≈ 0.017%） | 软件以「千分比」表达亮度，步进 0.5% |
| 亮度下限 | **3%**（宏 `DIM_MIN_PERMILLE`，可配 0） | 低于 3% 会频闪 |
| 通道映射 | PWM1 = PB01 = ATIM_CH2（组A）；PWM2 = PA03 = ATIM_CH3（组B） | 两路可独立调节 |

> 💡 与常见教程的差别：**调光频率不是越高越好**。本项目频率经过
> 20k → 30k → 5k → 1k → **8k** 的实测迭代，最终落在驱动芯片手册推荐区间内（见 `docs/08` §3.3）。

---

## §7 显示屏

| 项 | 参数 |
|---|---|
| 型号 | **0.5" CH1115，88×48 像素**（6 页 × 88 列，6×8 字体） |
| 接口 | 软件 I2C（SCL = PB06、SDA = PB05），地址 **0x3C**（探测 0x3C–0x3F） |
| 尺寸演进 | 0.91"(128×32) → 0.96"(128×64) → **0.5"(88×48)**，UI 重排为 6 行 × 14 字符 |
| 显示内容 | 电池电压/百分比、两组亮度与状态、吸附状态、调节目标（`TGT`）等 |

> ⚠️ CH1115 **不兼容** SSD1306 的 DC-DC 命令（`0x8D`）。初始化序列请以**屏厂官方例程**为准：
> `0x82` IREF + `0xAD 0x8B 0x33` + 方向 `A0/C0` + 偏移 `D3=0x38`（见 `docs/08` §3.1）。

---

## §8 BOM 与成本（低成本复现的关键）

**物料清单**：`工程文件夹/BOM_TYPE-A_PCB2_2026-08-23.xlsx`（34 行 / 56 位号，可直接立创商城配单）。

| 部分 | 说明 | 量级 |
|---|---|---|
| PCBA 器件 | 主控、充电管理、LED 驱动（RY3730×2）、阻容、接口 | **≈ ¥25–35** |
| 磁吸机构 | 钕铁硼磁铁 + 柔性臂/金属件 + 底座 | **≈ ¥8–12** |
| 外壳与装配件 | 3D 打印（耗材）+ 螺丝/导热垫 + **按键帽** | **≈ ¥5–10** |
| **整机合计** | 不含工具与耗材 | **≈ ¥45 级** |

**低成本复现的四个做法：**

1. **通用件优先**：阻容、LED、轻触开关全用常规料，不做定制；
2. **立创EDA 工程直接下单**：`TYPE-A.epro2` 可一键生成 PCB 订单；
3. **3D 打印代替开模**：`3D外壳/` 提供 STEP（含**按键帽**），FDM 打印机可出件；
4. **驱动可互换**：RY3730 与 SY7200 **pin-to-pin**，缺货时可切换（需同步核对调光频率区间）。

---

## §9 结构件说明

| 文件 | 内容 | 用途 |
|---|---|---|
| `3D外壳/外壳.SLDPRT` | 主体外壳（SolidWorks 源） | 装配 PCBA 与电池 |
| `3D外壳/盖子.SLDPRT` | 上盖 | 保护与外观 |
| `3D外壳/按键帽.SLDPRT` | **按键帽** | 手感与防误触（配合 3 键布局） |
| `3D外壳/散热片.SLDPRT` | 散热片 | LED 长时工作的热管理 |
| `3D外壳/3D_LED.step`、`3D_OLED.step` | 中间格式 | 任意 CAD 可打开，便于改版 |
| `3D外壳/总装.SLDASM` | 总装图 | 装配关系与干涉检查 |
| 磁吸底座 + 柔性臂 | 通用五金/打印件 | 一吸即用、万向悬停 |

**装配公差经验值**：外壳配合面留 0.2–0.3 mm；磁吸座粘接前先试吸合；
灯头出光面与散热片之间涂薄层导热介质；按键帽与轻触开关之间保留 0.1–0.2 mm 预压。

---

## §10 设计决策快问快答

| 问题 | 答复 |
|---|---|
| 为什么 MCU 直供电池不加 LDO？ | 省电、省件、省面积；代价是只能用 BGR 反推法测电压（§5）。 |
| 为什么调光用 8kHz 而不是 20kHz？ | 驱动手册推荐 100Hz–10kHz；8kHz 在区间内且无可见频闪（低占空比另设 3% 下限）。 |
| 为什么只用 3 个按键？ | 单击/长按/双击语义可覆盖全部功能，省引脚、省结构、省成本（§3）。 |
| 为什么按键是高有效？ | 硬件下拉电阻改小以抗 PWM 噪声，按键因此变成高有效（§2）。 |
| 检测为什么要 100ms 去抖？ | 磁吸撞击的机械稳定时间远长于人手按键（§4.3）。 |
| 为什么不加外部晶振？ | HSI 足够；省 2 元件 2 引脚，OSC± 可复用（§3）。 |
| 电池一定要 18650 吗？ | 不。任何 3.7V 锂电均可（注意容量与放电能力），改电池座即可。 |

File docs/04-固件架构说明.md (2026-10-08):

# 04 · 固件架构说明

> 对应源码：`USER/inc/` + `USER/src/`（12 个 BSP 模块）+ `MDK/Project.uvprojx`（Keil MDK5 + AC6）。
> 阅读顺序：`app_config.h` → `bsp_pin.h` → `main.c` → 各 `bsp_*.c`。

---

## §1 分层结构

```text
main.c / interrupts_cw32l010.c     应用层：UI 布局 / 按键状态机 / 电池状态机 / 主循环
        ▲
bsp_*.c（12 个模块）               板级支持层：一类硬件 = 一个模块
        ▲
CW32L010_Lib/                     芯片标准库（内嵌官方库 + 启动文件 + retarget）
```

| 模块 | 职责 | 教学要点 |
|---|---|---|
| `bsp_pin.h` | **全工程唯一的引脚映射表** | 「引脚改了只改一处」 |
| `app_config.h` | 型号开关（外挂款 / 内置款） | 一套代码覆盖两种产品 |
| `main.c` | UI 布局、按键状态机（单击·长按·双击）、电池状态机、主循环 | 把产品行为与寄存器隔开 |
| `interrupts_cw32l010.c` | BTIM1 1ms 中断入口 → `App_Task1ms()` 调度 | 中断里做什么/不做什么 |
| `bsp_timer.c` | 1ms 系统时基（48MHz/8 = 6MHz，Period 5999） | 软件定时节拍 |
| `bsp_pwm.c` | ATIM PWM：**8kHz / 6000 级**，`BSP_PWM_SetDuty(ch, 千分比)` | 频率与分辨率计算 |
| `bsp_oled.c` | **CH1115 88×48** 驱动（6×8 字库、官方初始化序列） | 屏驱动移植与 UI 排版 |
| `bsp_i2c.c` | 软件 I2C（5µs 时隙 ≈100kHz，地址探测 0x3C–0x3F） | 时序模拟与容错探测 |
| `bsp_adc.c` | 电池电压：**单 BGR 1.2V 反推**（`VBAT = BGR × 4095 / raw_bgr`） | 绝对参考的必要性 |
| `bsp_button.c` | 按键扫描（15ms 去抖，**有效电平宏可配**） | 有效电平与噪声的关系 |
| `bsp_detect.c` | 磁吸吸附检测（外挂款，**100ms 去抖**） | 去抖时间按物理过程定 |
| `bsp_power.c` | **STOP 停机**休眠 + PB03 **上升沿唤醒** | 边沿语义与时序 |
| `bsp_save.c` | **Flash 亮度记忆**（两组亮度 + RTC 时间戳，1h 恢复窗口） | 掉电存储与时间窗设计 |

> **设计哲学**：`main.c` 只表达「产品行为」，不知道寄存器细节；
> 换 MCU 时原则上只重写 `bsp_*`，`main.c` 语义不变。

---

## §2 按键与复合操作（3 键承载全部功能）

| 按键 | 单击 | 长按（≥300ms） | 双击（≤350ms） |
|---|---|---|---|
| **PB03**（开关机） | 开 / 关机 | — | — |
| **PA04**（亮度 −） | 亮度 −一步 | **连续调暗**（三段加速） | 切换**调节对象**：组A → 组B → 一起（屏显 `TGT`） |
| **PA05**（亮度 +） | 亮度 +一步 | **连续调亮**（三段加速） | 切换**点亮模式**：A 亮 → B 亮 → 一起亮（屏显 `G1/G2 OFF`） |

- 有效电平：**高有效**（外部下拉，抗 PWM 噪声）；
- 去抖：15ms；
- 调光加速曲线：**60ms/步 → 1.1s 后 30ms/步 → 1.9s 后 12ms/步**，步进 **0.5%**；
- 亮度下限：**3%**（宏 `DIM_MIN_PERMILLE`，低于会频闪；可配 0 完全放开）。

> 💡 学习点：**按键越少，语义设计越关键**。把"单击/长按/双击"定义成三种正交语义，
> 就能用 3 个键覆盖 8 个功能——这是消费级产品的常见做法。

---

## §3 PWM 调光：6000 级是怎么来的

```c
/* bsp_pwm.h */
ARR = 5999;          /* 计数时钟 6MHz? → 见下 */
```

本项目 PWM 计数时钟为 **48MHz**，最终频率与分辨率：

```text
PWM 频率   = 8 kHz        （RY3730 手册推荐 100Hz–10kHz 区间内）
分辨率     = 48MHz / 8kHz = 6000 级   （ARR = 5999）
软件表达   = 千分比 0–1000（默认 100 = 10%），步进 0.5%
占空比换算 = cmp = 千分比 × 6000 / 1000
```

- 通道：PWM1 = PB01 = `ATIM_CH2`（组A）；PWM2 = PA03 = `ATIM_CH3`（组B）；
- 输出条件（外挂款）：**`d = 电源ON × 组点亮 × 亮度 × 已吸附`** 任一为 0 则输出 0。

> 💡 频率与分辨率是一对矛盾（同一计数时钟下频率越高、级数越少）。
> 本项目选择"够用的频率 + 尽量高的级数"，并额外用**软件千分比**统一对外接口，
> 使上层代码与硬件寄存器解耦。

---

## §4 磁吸检测：去抖与联动

```text
100ms 去抖窗口（比按键的 15ms 长得多——磁吸撞击的机械稳定时间更长）
状态翻转 → 立即 ApplyOutputs()（脱落即灭）→ 置界面刷新请求
```

- 外挂款：`PA01` = 组1、`PA00` = 组2，高 = 已吸附；
- 内置款：整模块编译为空（`#if BSP_DETECT_ENABLED`），输出条件退化为「电源 × 点亮」；
- 未吸附 = 该路输出 0（**安全设计**：避免空载与异常驱动）。

> ⚠️ 常见错误：把检测写成每次轮询直接读电平 → 灯会闪。
> 正确做法：**去抖 + 只在状态翻转时动作**。

---

## §5 整机开关、低功耗与唤醒（踩坑最多的一处）

```text
关机：CE 拉低（3V3 轨断电）→ 进 STOP（仅保留 GPIO/RTC）
唤醒：PB03 上升沿 → 退出 STOP → 重新使能 HSI → 恢复外设
      → 延时 500 个 1ms 中断后再 OLED_Init（防上电随机亮点）
      → 吞咽窗口内忽略按键（防"唤醒即被再次判为关机"）
```

**四个真实踩过的坑（详见 `docs/08` §3.4）：**

| 现象 | 根因 | 解决 |
|---|---|---|
| 唤不醒 | 唤醒沿方向错（高有效按键需**上升沿**） | 配置上升沿唤醒 |
| 唤醒即重启 | 3V3 未稳时按键扫描误判 | **延迟初始化 + 吞咽窗口** |
| 松手即重启 | 按键**释放回弹**瞬态被当作新唤醒 | 等释放 + 100ms 消抖窗 + **清标志再睡** |
| 关机后开不了机 | PB03 供电随 CE 断开 | 硬件改版：PB3 由 VBAT 分压**常电** |

> 💡 学习点：低功耗调试的坑几乎都在**边沿语义**与**时序**上。
> 另外注意：本项目唤醒后亮度**强制回到 10%**（非关机前值）——若要保持，需改 `main.c` 恢复段。

---

## §6 电池采样与过放保护状态机（三重设计）

### 6.1 采样

```c
VBAT = BGR × 4095 / raw_bgr;    /* 内部 1.2V 基准反推 VDD；BGR 仅测量时开启 */
```

配套：**成对交替采样**（BGR 与电池通道成对读，抵消 LED 亮灭漂移）+ **IIR 平滑**。
节奏：50ms 一次。详见 `docs/03` §5。

### 6.2 过放保护（阈值 + 滞回 + 确认）

| 状态 | 阈值 | 行为 |
|---|---|---|
| LOW（低电告警） | < **3350 mV**（回升到 3400 mV 解除） | 显示告警页（标题闪烁） |
| PROTECT（过放保护） | < **3200 mV**（回升到 3350 mV 恢复） | **关断输出**，全屏告警 |
| 防抖 | **2s 连续确认** | 防止瞬态误判 |

**告警页交互**：任意键关屏；**1 分钟无操作自动关屏**（省电）。

> 💡 学习点：合格的电池保护必须做到三件事——**滞回**（防抖振）、**确认时间**（防瞬态）、
> **明确的用户可见状态**（告警页）。缺一个都会在真实使用中出问题。

---

## §7 Flash 亮度记忆（`bsp_save`）

| 项 | 设计 |
|---|---|
| 存储位置 | Flash **第 127 页（0xFE00）**，12 字节记录 + magic 校验 |
| 保存时机 | 亮度变更 **2s 后自动保存**（两组独立）+ **关机时保存** |
| 恢复条件 | 开机时 RTC 时间差 **≤ 1 小时** → 恢复；否则用默认 **10%** |
| 计时源 | 内部 **LSI** 驱动 RTC（无外部晶振） |
| 跨 Reset / 掉电 | Reset 后 RTC 继续走时（可恢复）；**掉电 RTC 归零 → 自然判为超时**（回到默认） |

> 💡 学习点：这是一个非常漂亮的"软性记忆"设计——
> **用时间窗把"想要记忆"和"数据过期"统一到一条判据上**，不需要额外清除逻辑。
> 已知的保守点：跨午夜场景会被判超时（默认 10%），如需精确可扩展日期字段。

---

## §8 任务调度（全部在 1ms 中断内分频）

| 周期 | 任务 |
|---|---|
| **1ms** | 系统时基、告警页自动关屏倒计时 |
| **5ms** | 按键扫描 + 按键状态机（调光加速 / 双击判定）+ 吸附检测 |
| **50ms** | ADC 电池采样 + 过放保护状态机 |
| **200ms** | 界面数值刷新请求 |
| **主循环** | 只做 OLED 慢速刷屏（耗时 ms 级，不适合放中断） |

> 💡 学习点：`main` 里几乎没有 `while` 阻塞——
> **所有周期性工作交给分频调度，主循环只做"慢活"**，
> 这样既有实时性，又不会因为刷屏破坏时基。

---

## §9 双型号配置（一行宏切换）

```c
/* USER/inc/app_config.h */
#define PRODUCT_VARIANT_EXTERNAL   0    /* 外挂款：磁吸 4pin + 吸附检测 */
#define PRODUCT_VARIANT_BUILTIN    1    /* 内置款：LED 焊在板上，无需检测 */
#define APP_PRODUCT_VARIANT        PRODUCT_VARIANT_EXTERNAL   /* ← 烧录前改这里 */
```

| 项 | 外挂款 | 内置款 |
|---|---|---|
| `BSP_DETECT_ENABLED` | 1（占用 PA00/PA01） | 0（PA00/PA01 可作按键） |
| 输出条件 | 需「已吸附」 | 仅需「电源 + 点亮」 |
| 按键布局 | 3 键（PB03/PA04/PA05） | 可扩展至 7 键 |

> 💡 学习点：把**产品差异收敛到一个宏**，代码路径共用、测试共用——这是小团队做多 SKU 的标准手段。

---

## §10 编译与资源占用

| 项 | 值 |
|---|---|
| 工具链 | Keil MDK5 + **Arm Compiler 6** |
| 器件包 | 需安装 `WHXY.CW32L010_DFP 1.0.2` |
| Flash | ≈ **12 KB**（主控 64 KB） |
| RAM | ≈ **1.1 KB**（主控 4 KB） |
| 编译状态 | 0 错误 0 警告 |
| 注意 | `base_types.h` 中 `USE_FULL_ASSERT` 无条件开启，应用侧必须提供 `assert_failed()`（已在 `main.c` 实现） |

---

## §11 移植与扩展建议

| 想做的事 | 建议起点 |
|---|---|
| 换 MCU | 保留 `main.c` 语义，重写 `bsp_*`；先移植 PWM 与按键 |
| 加蓝牙/串口上报 | 在 200ms 刷新节点挂上报任务（工位数据类项目的基础） |
| 自动调光（环境光感知） | 新增 `bsp_light.c`（光敏 ADC）+ 在 `ApplyOutputs()` 前插入策略，保留手动覆盖 |
| 增加第三路灯组 | 需新增 PWM 通道 + 检测口 + 按键语义（注意引脚余量） |
| 更长的亮度记忆窗口 | 扩展 `bsp_save` 记录结构（增加日期字段解决跨午夜） |
| 唤醒后保持关机前亮度 | 修改 `main.c` 唤醒恢复段（当前固定回 10%） |

---

## §12 代码风格约定（本包要求）

1. **一个模块一类硬件**：新增硬件 = 新增 `bsp_xxx.c/h`，不在 `main.c` 直接操作寄存器；
2. **引脚只在 `bsp_pin.h` 定义**，其他文件不得出现裸引脚号；
3. **中断里只做短任务**（采样、去抖、置标志），耗时操作交主循环；
4. **产品差异用宏**，不用运行时分支；
5. **注释解释「为什么」**，不复述代码；
6. **可配置项集中化**：亮度下限、恢复窗口、去抖时间、有效电平等都做成宏，便于按硬件适配。

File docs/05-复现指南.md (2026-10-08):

# 05 · 复现指南（稳定复现是硬指标）

> 目标：**一个没有本项目背景的人，照着做能复现出同样的整机。**
> 本文已根据项目最终硬件（RY3730 / CH1115 / 3 键 / 电池直供）更新。

---

## §0 复现路线图

```text
① 采购          BOM 配单（PCBA 器件）+ 磁吸机构 + 打印耗材
                    ↓ （PCB 打样与 3D 打印可并行等待）
② 制板与打印     立创EDA 下单打样 / STEP 切片打印（含按键帽）
                    ↓
③ 焊接与装配     按区焊接 → 通电初检 → 装壳 + 按键帽 + 磁吸底座
                    ↓
④ 烧录与调试    选型号宏 → SWD 烧录 → 上电自检 → 按排错表处理
                    ↓
⑤ 验收           按 06-测试与验收.md 逐项测并填表
```

---

## §1 采购清单

### 1.1 PCBA 器件（直接用 BOM）

打开 `工程文件夹/BOM_TYPE-A_PCB2_2026-08-23.xlsx`（34 行 / 56 位号），
在立创商城「BOM 配单」上传即可自动匹配料号与价格。

| 器件 | 不可动的关键点 | 可替代的部分 |
|---|---|---|
| 主控 **CW32L010F8** | 型号与封装（TSSOP-20）必须一致 | — |
| LED 驱动 **RY3730 ×2** | 调光接口（EN/PWM）、**手册频率区间 100Hz–10kHz** | **SY7200 可 pin-to-pin 替换** |
| 屏 **0.5" CH1115（88×48，I2C）** | 控制器型号（**不兼容 SSD1306 的 0x8D 命令**） | 同尺寸同控制器模块 |
| 充电/升压管理 | 与电池、TYPE-C 的配合关系 | 同类移动电源 SOC |
| 轻触开关 ×3 | 尺寸（影响手感与按键帽） | 同尺寸贴片轻触 |
| 18650 电池座 | 结构决定（外壳内腔） | 同规格座 |
| TYPE-C 6P | 沉板/立贴形式需与外壳匹配 | 同规格 |
| 阻容 | 值正确即可 | 品牌不限 |

> ⚠️ **不要在最终硬件上焊接 10K/10K 电池分压**（本项目已拆除）：那是 210µA 的常通耗电。
> 电池电压改用内部 BGR 反推（见 `docs/03` §5）。

### 1.2 磁吸机构（低成本方案）

| 件 | 要求 | 低成本做法 |
|---|---|---|
| 磁铁 | 直径 20mm 级，吸力足够 | 网购钕铁硼圆片 |
| 底座/法兰 | 与被吸表面（焊台铁质部分）贴合 | 铁片 + 3D 打印座 |
| 柔性臂 | 可定型、悬停不回弹 | 网购定型软管臂 |
| 灯头连接 | 与 PCB 灯组引出线可靠焊接 | 细硅胶线 + 热缩管 |

### 1.3 工具（一次性投入）

电烙铁（刀头/尖头）、热风枪（可选）、万用表、稳压电源（调试）、
SWD 调试器（CW32 配套或通用 DAP）、3D 打印机（或代打印）、镊子、免洗助焊剂、放大镜/台灯。

---

## §2 制板与打印

1. **PCB**：立创EDA 专业版打开 `工程文件夹/TYPE-A.epro2` → 检查 DRC → 导出 Gerber → 下单（默认工艺即可）。
2. **3D 打印**：`工程文件夹/3D外壳/*.step` 导入切片（FDM 建议层高 0.16–0.2mm、壁厚 ≥2 圈、填充 20–30%）。
   **按键帽也要打印**（3 键手感与防误触）——配合面偏紧用砂纸修整，不要硬压。
3. **散热片**：优先用随附模型；也可用等厚铝片裁切替换。

---

## §3 焊接与装配

### 3.1 焊接顺序（从低到高、从难到易）

```text
1) 主控 CW32L010F8（TSSOP-20，最难点，先做）
2) 电源区：充电管理、二极管、电感、电池座
3) LED 驱动区：RY3730 ×2、磁吸焊盘、检测下拉电阻
4) 阻容小件
5) 轻触开关 ×3、TYPE-C 座
6) 屏 FPC/排针（CH1115 模块）
```

### 3.2 四个必须注意的点

- **⚠️ 检测下拉电阻不能省**：漏焊会导致吸附检测随机跳变（灯闪）；
- **⚠️ 按键下拉电阻（低阻）不可省**：高阻节点会耦合 PWM 噪声 → 误触（`docs/08` §3.5）；
- **⚠️ 磁吸焊盘与 LED− 回路要能过电流**：走线加粗、多打过孔；
- **⚠️ PB03（开关机键）供电要常电**：若随 CE 一起断电，会出现「关机后开不了机」（`docs/08` §3.4）。

### 3.3 通电初检（先不装壳）

1. 上电测 VBAT 与 3V3 轨（3V3 受 CE 控制，开机状态才应有输出）；
2. 测 MCU 复位脚电平、SWD 是否可连接；
3. 未吸附状态下确认两路 PWM 无输出（安全设计正确）。

---

## §4 烧录

1. Keil MDK5 + **Arm Compiler 6** + 器件包 `WHXY.CW32L010_DFP 1.0.2`；
2. 打开 `MDK/Project.uvprojx`；
3. 按你的硬件选择型号（`USER/inc/app_config.h`）：

   ```c
   #define APP_PRODUCT_VARIANT   PRODUCT_VARIANT_EXTERNAL   /* 磁吸外挂款 */
   /* 或 */                    /* PRODUCT_VARIANT_BUILTIN —— 内置款 */
   ```

4. SWD 接线：SWCLK = PA08 / SWDIO = PA07 / GND / 3V3；
5. 编译（预期 ≈12KB Flash / ≈1.1KB RAM，0 错 0 警告）→ 下载 → 复位；
6. 首次运行预期：屏点亮并显示电池电压与两组状态；上电默认亮度 **10%**（若 1 小时内有关机记录则恢复记忆值）。

> 若编译报 `assert_failed` 未定义：应用侧必须提供该函数（本项目已在 `main.c` 实现）。

---

## §5 上电自检清单（逐项打勾）

- [ ] 屏正常显示（花屏 → 查 IIC 接触与初始化序列，见排错表）
- [ ] PB03 单击可开机/关机；关机后按键可唤醒
- [ ] PA05 单击亮度 +、长按连续调亮（三段加速）；PA04 反之
- [ ] 双击 PA04 切换调节对象（屏显 `TGT`：组A → 组B → 一起）
- [ ] 双击 PA05 切换点亮模式（A 亮 → B 亮 → 一起亮）
- [ ] 吸附灯组后该组点亮；**取下立即熄灭**
- [ ] 电池电压显示与万用表接近（≤ ±3%）
- [ ] 低电告警：电压 <3.35V 出 LOW 页；<3.2V 关断输出（可用稳压源模拟）
- [ ] 亮度记忆：调亮度 → 关机 → 立刻开机，亮度应恢复
- [ ] 关机静态电流显著低于开机态

---

## §6 排错表（整合项目真实踩坑）

| 现象 | 根因 | 解决 |
|---|---|---|
| **屏全黑** | CH1115 不认 SSD1306 的 `0x8D` 电荷泵命令；方向/偏移不符 | 用屏厂官方序列：`0x82` IREF + `0xAD 0x8B 0x33` + `A0/C0` + `D3 0x38` |
| **电池读数恒为 3.3V（或满量程一半）** | VBAT 直供导致分压与参考同源，比例测量失效 | 改用内部 **BGR 1.2V 反推 VDD** |
| **LED 亮起后电压乱跳** | 双通道非同时采样撞上 PWM 波动 | **成对交替采样 + IIR 平滑** |
| **低亮度频闪/啸叫** | 调光频率脱离驱动手册推荐区（100Hz–10kHz） | 用 **8kHz** + 亮度下限 **3%** |
| **关机松手即重启** | 按键释放回弹瞬态被当作唤醒沿 | 等释放 + **100ms 消抖窗 + 清标志再睡** |
| **唤不醒** | 唤醒边沿方向错（按键高有效需**上升沿**） | 配置上升沿唤醒 |
| **唤醒即关机/重启** | 3V3 未稳时按键扫描误判 | **延迟初始化 + 吞咽窗口** |
| **关机后开不了机** | PB03 供电随 CE 断开 | 硬件改版：PB03 由 VBAT 分压**常电** |
| **按键误触（PWM 开启后零星触发）** | 高阻节点耦合 PWM 噪声 | **硬件下拉电阻改小**（软件消抖无效） |
| **唤醒后花屏** | 屏幕掉电重启需完整初始化 | **唤醒延时 500×1ms 后重初始化屏** |
| 灯不亮（已吸附） | LED− 回路或驱动 EN 未接通 | 量灯端电压、查驱动使能与 LED− 走线 |
| 灯一亮就灭 | 检测误判为未吸附（DET 下拉缺失/接触不良） | 检查 DET 与下拉电阻 |
| 烧录连接失败 | SWD 接线/复位脚被占 | 检查 PA07/PA08；确认 NRST 未被外部拉死 |

---

## §7 复现成功的最小判据

> 满足以下三条即认为**复现成功**（可进入 `docs/06` 完整验收）：
> 1. 整机能开、能关、能被按键唤醒（且唤醒不花屏、松手不重启）；
> 2. 两组灯可分别独立调光（含长按连续调光与双击切换），吸附/脱落联动正确（脱落即灭）；
> 3. 屏正常显示电池电压、两组亮度与吸附状态，且低电告警与亮度记忆生效。

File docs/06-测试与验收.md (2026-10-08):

# 06 · 测试与验收

> 目的：把「我觉得挺好」变成「有数据、可复核、别人也能复测」。
> 本文所有判据可直接用于教学评分或复现验收（已按最终硬件更新）。

---

## §1 测试环境与工具

| 工具 | 用途 | 可替代方案 |
|---|---|---|
| 万用表 | 电压、电流、通断 | 台式表 |
| 稳压电源（0–10V 可调） | 模拟电池电压做**过放保护**测试 | 可调电池模拟器 |
| 示波器 / 逻辑分析仪 | PWM 频率占空比（8kHz）、无频闪判据 | 手机专业模式/慢动作（仅定性） |
| 测力计（弹簧秤） | 吸附力 | 挂钩 + 砝码逐级加载 |
| 秒表 | 续航计时 | 手机计时 |
| 电子温度计 / 热像仪 | 温升 | 接触式温度探头 |
| 角度尺 / 水平仪 | 悬停漂移 | 目测 + 标记点 |

**记录要求**：室温、湿度、样机编号、固件版本、测试日期——每一项都要写进记录表。

---

## §2 指标与合格判据（14 项）

| # | 指标 | 测试条件 | 合格判据（建议） |
|---|---|---|---|
| 1 | **吸附力** | 磁吸座吸合标准铁面，垂直加载 | ≥ 设计下限（本项目 2.5kg 级），加载不滑落 |
| 2 | **悬停角度漂移** | 柔臂调至任意角度静置 30 分钟 | 漂移 ≤1°（或标记点目测无明显变化） |
| 3 | **调光无频闪** | **8kHz**，手机摄像头贴近拍摄 | 画面无横向条纹/滚动 |
| 4 | **调光范围与下限** | 0 → 100% 扫描；最低档检查 | 连续可调无死角；**最低亮度 ≥3%**（低于 3% 允许截止，不得频闪） |
| 5 | **两路独立性** | 固定组A 亮度，调组B | 组A 读数与光输出均不变 |
| 6 | **吸附联动** | 点亮状态下取下灯组 | 该组**立即**熄灭 |
| 7 | **未吸附保护** | 不吸灯组开机 | 该路输出为 0（无空载输出） |
| 8 | **关机静态电流** | 关机后静置 1 分钟测电流 | 显著低于开机态（本项目已省去 210µA 分压耗电） |
| 9 | **续航** | 单组满亮度连续点亮 | ≥ 设计目标（按电池容量与驱动效率核算） |
| 10 | **温升** | 满亮度连续 30 分钟 | 外壳/灯头 ≤ 安全上限（不烫手、不光衰） |
| 11 | **电量显示误差** | 稳压源给 3.3 / 3.7 / 4.2 V 三点 | 显示 mV 与标准值误差 ≤ ±3% |
| 12 | **按键功能** | 单击 / 长按（≥300ms）/ 双击（≤350ms）逐项 | 与 `docs/04` §2 功能表完全一致（含三段加速） |
| 13 | **低电保护**（新增） | 稳压源缓慢下调电压 | <3.35V 出 LOW 告警页；<3.2V 关断输出；回升到 3.35V 恢复；2s 确认生效 |
| 14 | **亮度记忆**（新增） | 调亮度 → 关机 → 立刻开机；再等（或改窗口）超 1 小时 | ≤1 小时内开机亮度恢复；超窗口回到默认 10% |

---

## §3 逐项测试方法（要点）

### 3.1 吸附力（#1）

```text
1) 吸附座吸合基准铁面 → 静置 10 秒；
2) 挂钩挂灯头下方，逐级加砝码（或弹簧秤匀速下拉）；
3) 记录「首次移位/滑落」加载值，重复 3 次取最小。
```

### 3.2 悬停漂移（#2）

```text
1) 柔臂调至水平略上抬，外壳贴标记线并拍照；
2) 静置 30 分钟再拍照对比；
3) 加轻振动（敲击桌面 20 次）后复测，模拟焊接振动。
```

### 3.3 无频闪与最低亮度（#3 / #4）

```text
1) 手机专业模式，快门 ≥1/1000s（或慢动作录像），贴近灯面拍摄 → 8kHz 应无条纹；
2) 对照实验：把 PWM 频率改 1kHz 重烧，应能拍到明显条纹（证明方法有效）；
3) 长按调暗到最低，观察是否在 3% 以下出现闪烁/截止跳变（属预期行为）。
```

### 3.4 吸附联动与未吸附保护（#6 / #7）

```text
1) 点亮灯组 → 取下 → 慢动作录像判读熄灭时刻（目测"即灭"）；
2) 不吸灯组上电，测 PWM 引脚输出 → 应为 0；
3) 反复吸附/脱落 20 次，记录误动作次数（应为 0）。
```

### 3.5 关机静态电流（#8）

```text
1) 电池串入电流表（或用电源电流显示）；
2) 记录开机态电流；PB03 关机后静置 1 分钟再记录；
3) 两者应数量级差异。
```

### 3.6 低电保护（#13）

```text
1) 用稳压电源代替电池；
2) 缓慢下调：记录 LOW 出现电压（期望 3.35V 附近）与 PROTECT 关断电压（期望 3.2V 附近）；
3) 缓慢回升：记录解除告警/恢复输出电压（期望 3.40V / 3.35V，验证滞回）；
4) 快速抖动电压跨越阈值，确认 2s 确认逻辑没有被瞬态触发。
```

### 3.7 亮度记忆（#14）

```text
1) 把两组亮度调到明显不同的值（如 20% / 60%）；
2) 关机 → 立刻开机 → 两组亮度应分别恢复；
3) 使用时间窗验证：超出 1 小时窗口后开机，应回到默认 10%（可临时把窗口宏改小以快速验证）。
```

---

## §4 验收记录表（模板）

```text
样机编号：______   固件版本：______   测试人：______   日期：______
环境：室温 ____℃   湿度 ____%   电源：电池/稳压源（____V）

| # | 测试项          | 条件             | 实测数据              | 判据        | 结论 |
|---|-----------------|------------------|-----------------------|-------------|------|
| 1 | 吸附力          | 垂直加载         | ______ kg（3 次最小） | ≥2.5kg      | □通过 □不通过 |
| 2 | 悬停漂移        | 静置 30min       | ______ ° / 目测       | ≤1°         | □通过 □不通过 |
| 3 | 无频闪          | 8kHz 手机拍摄    | 条纹：有/无           | 无          | □通过 □不通过 |
| 4 | 调光范围/下限   | 全范围扫描       | 最低档 ____%，频闪：有/无 | ≥3% 且不闪 | □通过 □不通过 |
| 5 | 两路独立性      | 调组B 测组A      | 组A 变化：有/无       | 无          | □通过 □不通过 |
| 6 | 吸附联动        | 取下瞬间         | 熄灭：即时/延迟       | 即时        | □通过 □不通过 |
| 7 | 未吸附保护      | 不吸灯组开机     | PWM 输出：____        | 0           | □通过 □不通过 |
| 8 | 关机静态电流    | 静置 1min        | 开机____/关机____     | 显著降低    | □通过 □不通过 |
| 9 | 续航            | 满亮度连续       | ______ h              | ≥目标       | □通过 □不通过 |
| 10| 温升            | 30min 满亮度     | 最高 ____℃            | ≤安全上限   | □通过 □不通过 |
| 11| 电量显示误差    | 3.3/3.7/4.2V     | 误差 ____%            | ≤±3%        | □通过 □不通过 |
| 12| 按键功能        | 单击/长按/双击   | 异常项：____          | 与功能表一致| □通过 □不通过 |
| 13| 低电保护        | 稳压源缓降/回升  | LOW____/PROTECT____/恢复____ | 3.35/3.2/3.4V | □通过 □不通过 |
| 14| 亮度记忆        | 调亮度→关机→开机 | 恢复：是/否           | 窗口内恢复  | □通过 □不通过 |

备注/照片编号：______________________________________________________
```

---

## §5 教学评分建议

| 维度 | 权重 | 观察点 |
|---|---|---|
| 功能完整（#1/#3/#4/#6/#7/#12） | 35% | 板子是否「能用」，安全逻辑是否生效 |
| 数据可复核（记录表质量） | 20% | 条件、原始数据、结论三要素是否齐全 |
| 指标达标（#2/#5/#8/#10/#11/#13/#14） | 25% | 是否达到判据 |
| 工程规范（接线、焊接、注释） | 10% | 是否可维护、可复现 |
| 反思与改进（提出 ≥1 条改进并验证） | 10% | 是否形成闭环（建议参考 `docs/08` 的踩坑格式） |

---

## §6 复测须知（保证「稳定复现」）

1. **同一判据、同一条件**：换人复测必须记录环境与工具差异；
2. **失败即记录**：不通过项写明「现象 + 排查过程 + 当时的结论」（本项目 `docs/08` 即由此而来）；
3. **版本对应**：固件 / 外壳 / BOM 三者要能对上（建议样机贴版本号）；
4. **数据留存**：照片与波形按「样机号-测试项-日期」命名归档。

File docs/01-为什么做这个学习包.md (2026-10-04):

# 01 · 为什么做这个学习包

## 1. 一个真实的差距

我们团队在完成「磁吸焊接辅助手电」项目时，同时接触了两类东西：

- **一块老师研发的 CW32L010 开发板**：有完整的产品级工程框架（分层 BSP、双型号配置、低功耗、检测保护），但它是为「做出一个东西」准备的；
- **Arduino 生态**：上手极快、教程遍地，但绝大多数项目停留在「传感器 + 模块 + 会亮会动」的层面。

把两者放在一起，差距不在芯片强弱，而在**学习收获的层次**：

| 你会遇到的问题 | Arduino 类开发板 | 本项目的做法 |
|---|---|---|
| 灯怎么亮？ | `digitalWrite(13, HIGH)` 一行搞定 | LDO 软开关 + PWM 恒流驱动 + 20kHz 无频闪 |
| 亮度怎么调？ | `analogWrite()`（约 8 位，低频） | 2400 级、20kHz、双路独立、亮度以千分数表示 |
| 模块没插好怎么办？ | 一般不管 | 磁吸 DET 检测：**未吸附不输出、脱落即灭** |
| 引脚不够用怎么办？ | 换更大的板子 | **复用 OSC±** 两个引脚，兼容两种产品型号 |
| 关机后还耗电吗？ | `delay()` 死循环或直接断电 | LDO CE 拉低 + **STOP 停机**，任意键唤醒 |
| 外壳、装配、成本、测试？ | 不在教学范围内 | 3D 模型 + 装配公差 + BOM 成本 + 验收判据 |

> **启发**：开发板教你「怎么用芯片」，一个**完整产品**才教你「怎么做工程决策」。

由此我们认识到：这样的项目**不应该只停在我们三个人的桌面上**。它需要**开源的共享共建**——
把硬件、固件、结构、测试方法、以及每一个「为什么这样做」都公开出来，
让任何人可以**稳定复现**、并在复现之上继续走远。

---

## 2. 于是有了这个学习包

### 我们的三个目标

1. **项目式学习**：以「做出一台能用的整机」为目标，而不是以「跑通一个外设实验」为目标。
   学习路径覆盖电源、主控、输出、人机、结构、测试六个层面（见 `02-学习路径.md`）。
2. **稳定复现的低成本结构**：
   - 器件全部是**通用件**（立创商城可直采，替代型号在 `03` §5 给出）；
   - 结构件全部是 **3D 打印 + 通用磁吸五金**，无需开模；
   - 整机 BOM 控制在 **≈ ¥45 级**（不含打印耗材与焊接工具）；
   - 关键参数都给出**判据与测试方法**（见 `06-测试与验收.md`），保证「同样做法、同样结果」。
3. **共享共建**：文档写「为什么」，代码写「怎么」，问题写「坑在哪」——
   让下一个人不必从零踩坑。欢迎提交改进（见 `CONTRIBUTING.md`）。

### 与「教学实验板」的定位差异

- 实验板的目的是**验证知识点**，通常切断真实约束（不管功耗、不管结构、不管成本）；
- 本学习包保留**真实约束**：要低功耗、要装配得上、要便宜、要能量产思考——
  这正是从「学生会做实验」到「工程师能做产品」之间最缺的那一段。

---

## 3. 这个学习包适合谁

| 读者 | 建议路径 |
|---|---|
| 刚学完 C 语言与单片机基础的同学 | 按 `02-学习路径` 逐模块推进，先跑通外设，再看整机逻辑 |
| 有 Arduino 经验、想进阶的同学 | 重点看 `04-固件架构`（分层 BSP、调度、低功耗）与 `03-硬件设计`（电源与保护） |
| 电子设计竞赛 / 课程设计参赛者 | 直接参考本包的结构设计与测试判据（`03` §4、`06`） |
| 教师 / 社团讲师 | 见 `07-教学设计说明`（课时、检查点、评分建议、教学陷阱） |
| 想做一个类似产品的开发者 | 从 `03-硬件设计说明` 的电源链路与接口定义开始 |

---

## 4. 如何共建（最短版）

```text
发现问题        → 开 Issue（写清环境 + 复现步骤 + 期望结果）
做出改进        → Fork → 新建分支 → 提交 PR（说明「改了什么/为什么/如何验证」）
分享扩展        → 新外壳、新灯组、新交互、移植到其他 MCU 都欢迎
教学复用        → 直接使用 docs/07，注明出处即可
```

> 我们只坚持一件事：**任何改动都应让「下一个人复现」变得更容易，而不是更难。**

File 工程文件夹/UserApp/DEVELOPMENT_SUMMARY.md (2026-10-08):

# CW32L010 磁吸 LED 灯控固件 — 开发总结

> 本文档面向接过文档工作的协作者/Agent，汇总项目最终状态与开发历程要点。
> 工程路径：`C:\Users\35464\Desktop\创客训练营\工程文件夹\UserApp`

---

## 一、项目概述

- **产品形态**：双组 LED 灯具（组A / 组B），支持"外挂磁吸款 / 内置款"两种型号软件切换
- **主控**：武汉芯源 CW32L010F8（Cortex-M0+，TSSOP20，64KB Flash / 4KB RAM）
- **供电**：锂电池**直接给 MCU 供电**（VDD = VBAT，无稳压器、无外部晶振）
- **工具链**：Keil MDK5 + Arm Compiler 6（AC6），工程文件 `MDK/Project.uvprojx`
- **依赖**：`CW32L010_Lib/`（内嵌官方标准库 + 启动文件 + retarget）

---

## 二、最终硬件配置（经多轮硬件迭代后的状态）

| 项目 | 配置 | 说明 |
|---|---|---|
| 系统时钟 | HSI 48MHz（DIV1） | 无外部晶振，OSC 引脚复用为检测口 |
| LED 驱动 | RY3730 ×2（pin-to-pin 替代 SY7200） | EN/PWM 调光，手册推荐 100Hz~10kHz |
| PWM 输出 | PB01（组A，ATIM_CH2）/ PA03（组B，ATIM_CH3） | 8kHz，ARR=5999，6000 级分辨率 |
| 显示屏 | 0.5" CH1115，88×48，I2C | 软件 I2C：SCL=PB06、SDA=PB05，地址 0x3C |
| 按键 | PB03=开关机，PA04=亮度−，PA05=亮度+ | **高电平有效**（外部下拉），低阻抗扰 |
| 电池采样 | 无外部电路，内部 BGR 1.2V 反推 VDD | 原 10K/10K 分压已拆除（省 ~210µA 静态电流） |
| LDO 使能 CE | PB04 | 控制 3V3 轨（外挂款磁吸口供电） |
| 磁吸检测 | PA01=组1、PA00=组2（外挂款） | 高=已吸附；内置款此二脚不启用检测 |
| 低功耗计时 | 内部 LSI 驱动 RTC | 用于 Flash 亮度恢复的 1 小时窗口 |

---

## 三、软件架构与文件职责

```
USER/inc, USER/src
├── main.c            应用层: UI 布局 / 按键状态机(单击·长按·双击) / 电池状态机 / 主循环
├── interrupts_cw32l010.c  BTIM1 1ms 中断入口 -> App_Task1ms() 调度
├── bsp_timer.c/.h     BTIM1 1ms 系统时基 (48MHz/8=6MHz, Period 5999)
├── bsp_pwm.c/.h       ATIM PWM: 8kHz, BSP_PWM_SetDuty(ch,千分比)
├── bsp_oled.c/.h      CH1115 88×48 驱动 (6x8 字库, 官方初始化序列)
├── bsp_i2c.c/.h       软件 I2C (5µs 时隙≈100kHz, 地址探测 0x3C~0x3F)
├── bsp_adc.c/.h       电池电压: 单 BGR1.2V 反推 (VBAT=BGR×4095/raw_bgr)
├── bsp_button.c/.h    按键扫描 (15ms 去抖, 有效电平宏可配)
├── bsp_detect.c/.h    磁吸吸附检测 (外挂款, 100ms 去抖)
├── bsp_power.c/.h     STOP 停机休眠 + PB03 上升沿唤醒
├── bsp_save.c/.h      Flash 亮度记忆 (两组亮度+RTC 时间戳, 1h 恢复窗口)
├── app_config.h       型号开关: 外挂款 / 内置款
└── main.h / bsp_pin.h 全局声明与引脚映射
```

**中断与任务调度**（全部在 BTIM1 1ms 中断内分频，主循环只做 OLED 慢速刷屏）：
- 1ms：系统时基 / 告警页自动关屏倒计时
- 5ms：按键扫描 + 按键状态机（调光加速/双击判定） + 吸附检测
- 50ms：ADC 电池采样 + 过放保护状态机
- 200ms：界面数值刷新请求

---

## 四、功能清单与关键参数

| 功能 | 实现要点 |
|---|---|
| 无级调光 | 按住亮度键连续调节，三段加速：60ms/步 → 1.1s 后 30ms/步 → 1.9s 后 12ms/步；步进 0.5% |
| 亮度下限 | 3%（低于 3% 会频闪，宏 `DIM_MIN_PERMILLE` 可调；0=熄灭，与 3% 间跳变） |
| 单击/长按/双击 | 单击=一步微调；长按≥300ms=连续调节；双击（≤350ms）=切换功能 |
| 双击 − | 切换调节对象：A串 → B串 → 一起（屏幕 `TGT` 显示） |
| 双击 + | 切换点亮模式：A亮 → B亮 → 一起亮（屏幕 G1/G2 显示 OFF） |
| 电池保护 | LOW <3350mV（回 3400 解除）；PROTECT <3200mV 关断输出（回 3350 恢复）；2s 连续确认防抖 |
| 告警页 | LOW 标题闪烁 / PROTECT 全屏告警；任意键关屏，1 分钟无操作自动关屏 |
| Flash 记忆 | 亮度变更 2s 后自动保存（两组独立）+ 关机时保存；开机时 RTC 差值 ≤1h 则恢复，否则默认 10% |
| 低功耗 | 关机=CE 断电 + STOP 停机（仅留 GPIO/RTC），PB03 上升沿唤醒；唤醒后延时 500 个 1ms 中断再重初始化屏幕（防随机亮点） |
| 型号切换 | `app_config.h` 单宏切换：外挂款（5 键+检测）/ 内置款（7 键无检测） |

**上电默认**：亮度 10%（或 1h 内恢复值）→ 两组同亮。

---

## 五、开发经历（简要历程）

### 阶段 1：框架搭建
- 基于 CW32 官方例程（gpio_blink 结构）+ H563 工程的 OLED/I2C 驱动移植
- 建立 UserApp 工程，确定 HSI 48MHz 单时钟方案，ATIM 输出 PWM

### 阶段 2：需求快速迭代
- 按键映射反复调整（7键 → 5键 → 最终 3键：PB03/PA04/PA05）
- 加入磁吸吸附检测、外挂/内置双型号开关
- 建立电池过放保护状态机，阈值两次调整（3.5/3.2 → 3.35/3.2 提高电池利用率）

### 阶段 3：硬件联调攻坚（占开发时间最长）
1. **OLED 点亮马拉松**：经历 4 轮方案——SSD1306 序列 → 网络教程 CH1115 序列 → GitHub 库 → 最终用**商家官方 C51 源码**定位。根因是多处参数差异：方向（A0/C0）、显示偏移（D3=0x38）、电荷泵（0xAD 0x8B 0x33）、IREF（0x82 配置）
2. **ADC 测不准**：
   - 第一阶段：VBAT 直供导致"比例测量失效"（raw 恒为满量程一半）→ 用内部 BGR 1.2V 反推 VDD 解决
   - 第二阶段：LED 点亮后读数漂移 → 双通道成对交替采样 + IIR 平滑
   - 第三阶段：为省电拆除外部 10K 分压（原静态耗电 ~210µA），改为纯 BGR 反推 + BGR 仅测量时开启
3. **频闪/啸叫/功耗调试**：PWM 频率调整史 20k → 30k → 5k → 1k → **8kHz**。根因：RY3730 手册规定调光频率 100Hz~10kHz，超范围或过低都有问题；低占空比频闪最终以 3% 下限 + 8kHz 收尾
4. **休眠唤醒反复踩坑**：
   - "唤不醒"：唤醒沿方向错误（高有效按键需上升沿）
   - "唤醒即重启"：唤醒恢复时序问题（3V3 未稳时按键扫描误判），改为延迟初始化 + 吞咽窗口
   - "松手即重启"：机械按键释放回弹产生瞬态边沿，改为等释放 + 100ms 消抖窗 + 清标志再睡
   - "关机后开不了"：PB3 供电随 CE 断开，下一版硬件改 PB3 由 VBAT 分压常电
5. **按键误触**：无噪声环境正常、PWM 开启后零星误触 → 硬件减小下拉电阻根治（高阻节点抗扰差）

### 阶段 4：体验优化
- 无级调光 + 长按三段加速 + 单击/双击复合功能
- Flash 亮度记忆（RTC 1 小时窗口，跨 Reset 有效；掉电自然过期）
- 屏幕由 0.91"(128×32) → 0.96"(128×64) → 最终 **0.5"(CH1115 88×48)**，UI 全部重排为 6 行×14 字符
- 删除各类调试显示（raw/i12/ST-EV/开机诊断动画），代码瘦身

### 关键踩坑速查表

| 现象 | 根因 | 解决 |
|---|---|---|
| 屏幕全黑 | CH1115 不认 SSD1306 的 DC-DC 命令(0x8D)、方向/偏移错误 | 商家官方序列: 0x82 IREF + 0xAD 0x8B 0x33 + A0/C0 + D3 0x38 |
| 电池读数恒为 3.3V | VBAT 直供 → 分压/参考同源，比例恒定 | 内部 BGR 反推 VDD |
| LED 亮起后电压乱跳 | 双通道非同时采样遇 PWM 波动 | 成对交替采样 + 平滑 |
| 低亮度频闪 | 调光频率脱离 RY3730 推荐区(100Hz-10kHz) | 8kHz + 3% 下限 |
| 关机松手即重启 | 按键释放回弹瞬态被当唤醒沿 | 等释放+消抖窗+清标志 |
| 按键误触 | 高阻节点耦合 PWM 噪声 | 硬件下拉电阻改小 |
| 唤醒后花屏 | 屏幕掉电重启需完整初始化 | 唤醒延时 500 中断后 OLED_Init |

---

## 六、当前状态与注意事项

- **状态**：全部功能验证通过，编译 0 错误 0 警告；Code ≈12KB / RAM ≈1.1KB
- **注意事项**：
  1. 亮度下限宏 `DIM_MIN_PERMILLE`（默认 30=3%）：低于 3% 频闪，可配为 0 完全放开
  2. Flash 恢复的跨午夜场景保守判超时（按默认 10% 处理），如需精确可扩展日期字段
  3. 外挂款未吸附的组不输出（安全设计）；内置款跳过检测逻辑
  4. 休眠唤醒：唤醒后强制亮度回到 10%（非关机前值），如需保持可修改 main.c 恢复段
  5. `CW32L010_Lib/base_types.h` 中 `USE_FULL_ASSERT` 无条件开启，应用侧必须提供 `assert_failed()`（已在 main.c 实现）

---

*文档生成：基于完整开发过程的整理，可作为 README 深化、技术报告或交接文档的素材。*

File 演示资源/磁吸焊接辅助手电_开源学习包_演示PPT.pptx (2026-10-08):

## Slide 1

磁吸焊接辅助手电

—— 一个「从零到整机」的开源学习包

不是又一块开发板，而是一个完整产品
硬件 + 固件 + 结构 + 测试，全链路开源 · 可稳定复现 · 低成本

仿真跑不队：邵子中、李昊桐、姜亚楷　|　指导老师提供 CW32L010 开发板与工程框架
GitHub：github.com/Davidshao-114514/chuangkexunlianying

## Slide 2

为什么做这个学习包

起点：一块老师研发的开发板 与 Arduino 之间的差距

开发板 / Arduino 教会我们什么

• 单个外设怎么用：点灯、按键、刷屏、PWM
• 大量现成库与教程，快速看到效果
• 但——板载条件已定，不需要做工程决策

一个完整产品逼着我们回答

• 电池设备为什么敢不用稳压器？那怎么测电压？
• 驱动手册写 100Hz–10kHz，到底选多少？
• 3 个按键怎么覆盖 8 项功能？
• 关机后怎么做到唤醒不花屏、松手不重启？

启发与选择

→ 开发板教你「怎么用芯片」，一个完整产品才教你「怎么做工程决策」。
→ 这样的项目不该停在我们三个人的桌面上——它需要开源的共享共建：让别人能稳定复现、并在复现之上继续走远。

于是有了这个学习包（三个目标）

① 项目式学习：以「做出一台能用的整机」为目标，覆盖电源/主控/输出/人机/结构/测试六个层面
② 稳定复现的低成本结构：通用件 + 3D 打印 + BOM≈¥45 + 14 项量化验收判据
③ 共享共建：文档写「为什么」、代码写「怎么」、问题写「坑在哪」

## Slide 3

项目是什么：一吸即用、指哪照哪的焊接照明工具

面向「焊点看得见、双手都解放」的真实场景（磁吸底座 + 万向柔臂 + 双路无级调光）

痛点 1 · 遮挡

左手镊子、右手烙铁，光照永远差 5 cm
→ 磁吸 + 万向柔臂：把光贴到焊点上

痛点 2 · 占位

台灯底座吃掉四分之一桌面
→ 磁吸离场：桌面零占用

痛点 3 · 不稳/贵

廉价灯夹不稳、专业机床灯 300+ 元
→ 双路独立调光，百元以内

与常见方案的差异（一句话版本）
· 相比台灯 / 廉价便携灯：吸上就亮、取下就灭（磁吸 DET 检测，未吸附不输出）
· 相比专业机床灯：价格降 75%+，同时保留「万向瞄准 + 无级调光」
· 相比「又一块玩具灯」：本项目的价值不止在灯，而在于它**完整可复现的工程体系**——这才是开源学习包的主体

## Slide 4

硬核参数一览（全部有文档依据与踩坑过程）

对应 docs/03 硬件设计说明、docs/04 固件架构说明

项目 | 参数 | 说明
主控 | CW32L010F8（M0+，TSSOP-20） | HSI 48MHz，无外部晶振，OSC± 复用
供电 | 锂电池直供 MCU | 无稳压器；CE 控制 3V3 轨（磁吸口）
调光 | 双路 PWM 8kHz / 6000 级 | ARR=5999，步进 0.5%，下限 3%
驱动 | RY3730 ×2 | 可 pin-to-pin 替换 SY7200
磁吸接口 | 4pin：3V3/GND/LED−/DET | 吸附才输出，脱落即灭
检测去抖 | 100ms（按键仅 15ms） | 去抖时间由物理过程决定
按键 | 3 键复合语义 | 单击/长按（三段加速）/双击
电池采样 | 内部 BGR 1.2V 反推 VDD | 无外部电路，省 210µA
电池保护 | LOW<3350mV / PROTECT<3200mV | 滞回 + 2s 确认 + 告警页
显示 | 0.5" CH1115 88×48 | 软件 I2C，地址 0x3C
掉电记忆 | Flash + RTC 1h 窗口 | 记住亮度又不会记住过期设置
资源占用 | Flash≈12KB / RAM≈1.1KB | 编译 0 错 0 警告

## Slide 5

系统框图：四个域 + 十二类连线

电源域 / 主控域 / 输出域 / 人机域——任何一部分都可单独替换或升级

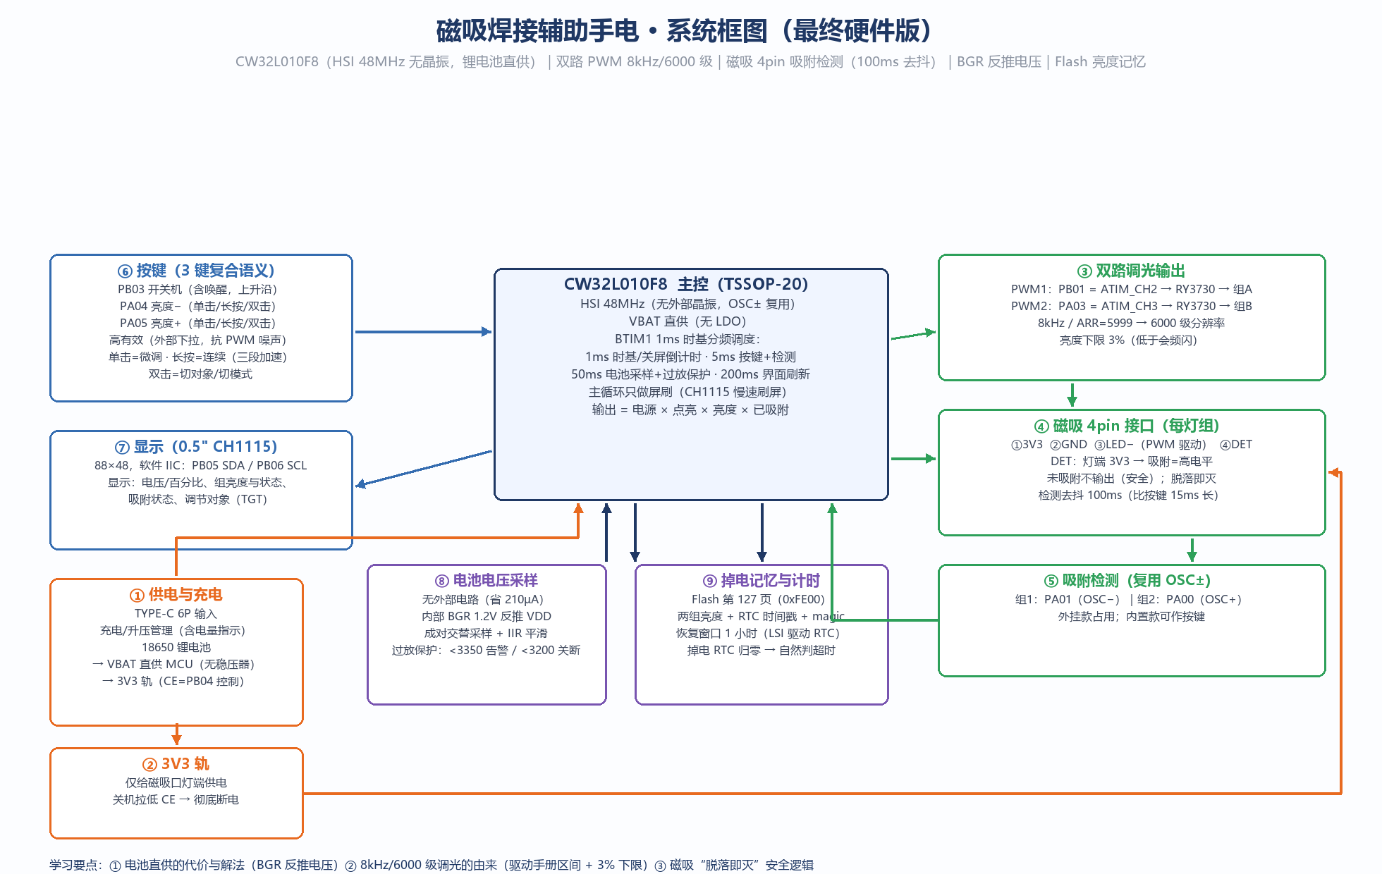
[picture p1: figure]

完整文件：docs/系统框图.png（可打印）

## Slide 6

硬件设计亮点：三个「反常识」决策

每一个决策都写清了理由与代价（docs/03）

① 电池直供 MCU
（不加稳压器）

为什么：省元件、省静态电流、省板面积
代价：不能再「分压 + 同源参考」测电压——比例测量会失效
解法：内部 BGR 1.2V 绝对参考反推 VDD
· BGR 仅测量时开启
· 成对交替采样（抵消 LED 亮灭漂移）
· IIR 平滑（抑制 PWM 纹波）
省下外部 10K/10K 分压的 210µA 常通耗电

② 磁吸 4pin 与「脱落即灭」

接口：3V3 / GND / LED− / DET
原理：板侧 DET 下拉（未吸附=低）；灯端把 3V3 接 DET（吸附=高）
三个收益：
· 安全：脱落瞬间切断输出，避免开路/异常驱动
· 交互：吸上就亮、取下就灭，无需额外开关
· 可诊断：吸附状态上屏，一眼区分「灯坏」与「没吸好」
去抖 100ms（磁吸撞击远长于人手按键）

③ 频率与亮度下限
一起设计

调光频率迭代史：
20k → 30k → 5k → 1k → 8kHz
根因：驱动手册推荐 100Hz–10kHz
最终：8kHz + 亮度下限 3%
（低于 3% 会频闪；下限与频率必须一起定）
→ 分辨率 6000 级，软件用千分比对外暴露，与寄存器解耦

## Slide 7

固件架构：分层 BSP + 1ms 分频调度

12 个 BSP 模块，main.c 只表达产品行为，不知道寄存器细节（docs/04）

分层结构

main.c / interrupts_cw32l010.c
应用层：UI 布局 / 按键状态机 / 电池状态机 / 主循环
▲
bsp_*.c（12 个模块）
bsp_pwm（8kHz 双路）· bsp_detect（100ms 去抖）
bsp_power（STOP+上升沿唤醒）· bsp_save（Flash 亮度记忆）
bsp_adc（BGR 反推）· bsp_oled（CH1115）· bsp_i2c · bsp_button · bsp_timer
▲
CW32L010_Lib（芯片标准库）
价值：换 MCU 时原则上只重写 bsp_*，main.c 语义不变

调度：全部在 1ms 中断内分频

1ms：系统时基 / 告警页关屏倒计时
5ms：按键扫描 + 状态机（调光加速/双击判定）+ 吸附检测
50ms：ADC 采样 + 过放保护状态机
200ms：界面数值刷新请求
主循环：只做 OLED 刷屏（耗时 ms 级，不能进中断）

3 键承载 8 项功能

PB03 开关机（含唤醒，上升沿）
PA04 亮度−：单击微调 / 长按连续 / 双击切「调节对象」
PA05 亮度+：单击微调 / 长按连续 / 双击切「点亮模式」
连续调节三段加速：60ms → 1.1s 后 30ms → 1.9s 后 12ms/步
有效电平高（外部下拉，抗 PWM 噪声）

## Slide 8

开发踩坑实录：这些坑比代码更值钱

docs/08 —— 完整记录「现象 → 根因 → 解决」，可当排错清单用

现象 | 根因 | 解决
屏幕全黑（4 轮才点亮） | CH1115 不认 SSD1306 的 0x8D 命令；方向/偏移不符 | 用屏厂官方序列：0x82 + 0xAD 0x8B 0x33 + A0/C0 + D3 0x38
电池读数恒为满量程一半 | VBAT 直供 → 分压与参考同源，比例测量失效 | 内部 BGR 1.2V 反推 VDD
LED 亮起后电压乱跳 | 双通道非同时采样撞上 PWM 波动 | 成对交替采样 + IIR 平滑
低亮度频闪 / 啸叫 | 频率脱离驱动手册推荐区（100Hz–10kHz） | 8kHz + 亮度下限 3%
关机松手即重启 | 按键释放回弹瞬态被当作唤醒沿 | 等释放 + 100ms 消抖窗 + 清标志再睡
按键误触（PWM 一开就触发） | 高阻节点耦合 PWM 噪声 | 硬件下拉电阻改小（软件消抖无效）
唤醒后花屏 | 屏幕掉电重启需完整初始化 | 唤醒延时 500×1ms 后再初始化屏

从这些坑提炼的工程原则：以厂家官方例程为准 · 测电源要有绝对参考 · 频率与占空比一起设计 · 低功耗的坑都在时序上 · 软件治不了的噪声回硬件解决 · 把坑写下来

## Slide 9

稳定复现的低成本结构

目标：一个没有本项目背景的人，照做能复现出同样的整机（docs/05）

成本拆解

PCBA 器件：≈ ¥25–35
磁吸机构：≈ ¥8–12
外壳/装配（含按键帽）：≈ ¥5–10
————————————
整机：≈ ¥45 级（不含工具）

降本四招

① 通用件优先，不做定制
② 立创EDA 工程一键下单打样
③ 3D 打印替代开模（含按键帽）
④ 驱动 pin-to-pin 可替换（RY3730 ⇄ SY7200）

复现路线

采购 → 制板&打印 → 焊接装配 →
烧录 → 上电自检 → 14 项验收
配套：完整 BOM（34 行/56 位号）、
3D 模型、立创EDA 工程、排错表

为什么能「稳定」复现

· 判据可量化：14 项指标（吸附力、漂移、无频闪、联动、静态电流、续航、温升、电量误差、低电保护、亮度记忆…）每项都有测试条件与合格阈值
· 记录可复核：验收记录表模板（条件 / 原始数据 / 结论三要素）；失败项必须写排查过程
· 坑已排明：12 条真实现象 → 根因 → 解决 的排错表（docs/05 §6）
· 版本可对照：固件 / 外壳 / BOM 三者可对上，样机贴版本号；改造项（频率、去抖、窗口、下限）全部做成宏，可配置、可回退

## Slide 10

学习路径：9 个模块 / 16–24 学时

每模块四段：目标 → 读什么 → 动手做什么 → 检查点（docs/02）

# | 模块 | 你会获得

1 | 看懂一台整机 | 四域分区思维；自己画一张系统框图
2 | 供电与软开关 | 电池直供的取舍；CE 控 3V3；关机为何要 STOP
3 | 按键与复合语义 | 高有效输入、15ms 去抖、单击/长按/双击状态机
4 | PWM 与无级调光 | 8kHz/6000 级推导；最低占空比下限为何是 3%
5 | 磁吸检测与安全联动 | 复用引脚、100ms 去抖、脱落即灭
6 | 采样与电池保护状态机 | BGR 绝对参考、成对采样、滞回阈值与告警
7 | 低功耗与掉电记忆 | 唤醒沿/消抖窗/延迟初始化；Flash 记忆时间窗
8 | 结构、装配与验收 | 磁吸底座+按键帽装配；14 项验收判据
★ | 开发踩坑复盘 | 把别人的坑变成自己的经验（最值钱的一节）

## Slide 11

开源共建共享

开源不是把代码扔出去，而是让别人能稳定复现、并在此基础上继续走远

欢迎的贡献

🐛 报问题：开 Issue（环境 / 现象 / 复现步骤 / 已尝试）
🔧 改代码：修 bug、优化去抖、提升可移植性
📐 改硬件：替代件验证、布局优化（需附实测数据）
🖨 改结构：更好打印的模型、兼容其他磁吸座
🎓 教学复用：教师/社团可直接用 docs/07 当课程包
🧰 留坑记录：把你的踩坑补进 docs/08（比代码更珍贵）

共建原则（四条）

① 可复现优先：让「下一个人照着做得到同样结果」更容易
② 解释为什么：代码与文档都要讲清设计动机
③ 小步提交：一次 PR 只做一件事，便于审查与回退
④ 友善沟通：本包的目标对象就是初学者

仓库与文档结构

README.md（门面）· CONTRIBUTING.md（共建指南）· LICENSE(MIT)
docs/01 为什么做这个学习包　docs/02 学习路径　docs/03 硬件设计说明　docs/04 固件架构说明
docs/05 复现指南　docs/06 测试与验收　docs/07 教学设计　docs/08 开发踩坑实录　系统框图.png
USER/ 固件（12 个 BSP 模块）· MDK/ Keil 工程 · 工程文件夹/ UserApp完整工程 + 立创EDA + 3D外壳 + BOM
GitHub：github.com/Davidshao-114514/chuangkexunlianying

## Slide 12

一吸即用，指哪照哪

一个完整产品，抵得过一打外设实验
欢迎复现、欢迎改进、欢迎把你的坑也留下来

仿真跑不队 · 邵子中 / 李昊桐 / 姜亚楷
感谢指导老师的开发板与工程框架；感谢每一位共建者

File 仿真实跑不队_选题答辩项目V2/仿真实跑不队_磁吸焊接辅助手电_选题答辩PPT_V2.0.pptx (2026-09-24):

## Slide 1

创客竞赛选题验证 · 选题答辩

磁吸焊接辅助手电

一吸即用 · 指哪照哪 —— 给焊接者一双腾出来的手

1班C组 · 仿真实跑不队

核心成员：邵子中（负责人） · 李昊桐 · 姜亚楷

验证对象：焊接工位 · 高频手工焊接 / 焊点检查场景

V2.0

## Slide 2

CONTENTS 内容结构

目标用户 · 量化痛点 · 竞品对比（3+，量化差异）

核心价值主张 · 五大待验证假设

九大模块 · 逻辑连线 · 颜色编码

验证设计 · 量化成功指标 · 5W2H 实施

市场空间 · 增长假设 · 商业落地

成本 · 周期 · 风险 · 下一步行动

三大最尖锐问题 · 关键回答

评价摘要 · 逐条回应（认同/已执行/存疑）

目录

01

选题背景

02

价值假设

03

精益画布

04

MVP 验证

05

增长潜力

实施规划

06

07

Q&A 预判

08

AI评价与团队分析

磁吸焊接辅助手电 · 仿真实跑不队

2

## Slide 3

选题背景：我们的目标用户

目标用户画像与高频刚需场景

高频、刚需、三维场景交集，周使用频率 3 次以上

01

高校电子类专业学生

课程实训、毕设核心场景，高频电路焊接与调试。

DIY 极客

热衷自制硬件，享受动手组装，对焊接工具需求高频。

研发 / 维修工程师

原型开发与硬件调试，追求高精度、高稳定性焊接照明。

84.13%

每周焊接 ≥3 次

高频作业人群

76.98%

依赖精细补光

焊接微小贴片强烈依赖精准照度

71.43%

工位空间受限

操作台狭小，传统灯具挤占空间

100%

需解放双手

双手协同，无法手持灯具

磁吸焊接辅助手电 · 仿真实跑不队

3

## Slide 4

选题背景：核心痛点（126 份问卷量化支撑）

真实焊接场景三大核心壁垒 · 数据来自问卷与沉浸式实测

体积庞大占用操作台核心空间，灯臂僵硬、角度受限，无法灵活聚焦微小焊点

支架单薄刚度不足，高频震动易致光源偏移；灯罩聚光差、光线发散

动辄数百上千元，远超学生与业余爱好者预算，与非高频场景严重不匹配

沉浸式实测：无照明 → 不同照明下的焊接失败率对比

01

传统台灯

68.25%

平价灯具

61.11%

专业光源

54.76%

无灯光 50%

传统台灯 30%

磁吸手电 20%

手电失败率显著降低 30 个百分点 → 有效证明补光价值

磁吸焊接辅助手电 · 仿真实跑不队

4

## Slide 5

选题背景：竞品对比（量化差异）

4 款方案横向对比 · 四大核心维度量化打分

产品 | 价格带 | 万向磁吸 | 无级调光 | 状态显示 | 空间占用 | 综合
传统台灯 | 60–200元 | 差 | 差 | 无 | 高（占台面） | ★★
廉价便携灯 | 20–49元 | 差 | 少档位 | 无 | 中（易倾倒） | ★★
专业工业灯 | 300元+ | 优 | 有 | 无 | 高（占地） | ★★★
磁吸焊接手电 | 59–79元 | 优 | 无级 | LED+OLED | 零占地 | ★★★★★

市场机会： 现有方案无法兼顾「万向磁吸、无级调光、状态可视、低成本」四大核心需求，市场存在明显空白。

综合评分依据（量化）： 万向磁吸 × 无级调光 × 状态显示 × 空间占用 四项可量化事实加权 —— 仅磁吸焊接手电四项全覆盖 → 满分

差异化组合： 强磁吸附 + 360°悬停 + 无级调光 + LED 状态（OLED 选配），以 59–79 元普惠定价（对比专业灯 300 元+）切入。

护城河主张： 价格分层（49/79 元）＋ 高校/创客教育生态 ＋ 焊接工位标准数据接口（OPC 生态对接）。

01

磁吸焊接辅助手电 · 仿真实跑不队

5

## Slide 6

价值假设：核心价值主张与待验证假设

从“创意是否值得做”到“证据闭环”的关键假设清单

核心价值主张：给焊接者一双腾出来的手

磁吸固定解放双手 · 万向悬停指哪照哪 · 无级调光适配光环境 · 目标零售 59–79 元（对比专业灯 300 元+）

口径声明（V2.0 对齐）：LED 状态显示＝量产标配；OLED＝可选扩展模块（H1 排针预留）——宣传口径与实物一致，消除“表里不一”质疑。

6 颗 LED 状态灯（4 电量+2 充电）能覆盖用户 80% 状态查询需求

成立条件： 在无屏样机 vs OLED 外接版 20 人 A/B 对比测试下成立

用户愿意为“温度过热提醒”支付 +15 元

成立条件： 在 59–79 元目标价位区间内成立

“青春版（¥39–49 无屏版）”能覆盖 20% 以上价格敏感用户

成立条件： 在与标准版同时展示时成立

2600mAh 高配版（+¥8）有 ≥20% 用户选择

成立条件： 在双版本同时售卖的条件下成立

柔性臂 3000 次弯折后角度漂移仍 <5°

成立条件： 在实验室疲劳测试条件下成立

02

假设 1 · 最高优先

假设 2

假设 3

假设 4

假设 5

磁吸焊接辅助手电 · 仿真实跑不队

6

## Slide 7

精益画布：九大模块 · 逻辑连线 · 颜色编码

一页看清问题—方案—优势—利润的闭环

颜色编码：红=问题 蓝=客户 橙=价值主张 绿=方案 紫=优势 绿=关键指标 金=渠道 灰=成本 青=利润 | 逻辑连线：问题→价值主张→方案/优势→关键指标→收入

03

问题 Problem

84.13% 高频焊接
76.98% 依赖精细补光
100% 需双手
三类灯具各有短板

客户细分 Segment

高校电子专业学生
DIY 极客
研发/维修工程师

独特价值主张 UVP

磁吸固定解放双手
万向悬停指哪照哪
无级调光适配光环境
59–79 普惠定价

解决方案 Solution

强力磁吸+360°悬停
高显指OSRAM LED
无级调光(20kHz无频闪)
LED状态(OLED选配)

不公平优势 Advantage

成熟供应链无断供
双版本价格分层
创客教育深度属性

关键指标 Metrics

购买意愿 ≥60%
高频作业 84.13%
用户留存 45.2%

渠道 Channels

网络电商
微商/社群裂变
创客教育/高校渠道

成本结构 Cost

BOM ¥25–35
OLED +¥5 高配 +¥8
小批量外壳/柔性臂

收入来源 Revenue

标准版 59–79
青春版 39–49 高配版
配件/扩展模块

磁吸焊接辅助手电 · 仿真实跑不队

7

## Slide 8

MVP 验证：验证设计与量化指标

20 人 × 25 分钟真实焊接 A/B 对比 + 虚拟支付问卷

量化核心指标：

状态查询 ≤2 次 / 每次 ≤5 秒 · 购买意愿 ≥60% · 59 元档占比 ≥40% · A/B 差异 <10%

04

MVP 形态

物理装置样机 A/B 对比 + 虚拟支付问卷。A 组＝现有无屏样机（LED 状态灯）；B 组＝同款样机 + OLED 扩展模块（H1 排针外接），两组外观一致避免偏见。

✅ 成功标准（任一成立）

• ≥70% 测试者 25 分钟状态查询 ≤2 次且 ≤5 秒/次（A/B 差异 <10%）

• ≥60% 愿意购买（≤59 元档 ≥40%）

• A 组主观评分 ≥4/5

验证目标

① 假设 1：LED 灯 vs OLED 在真实焊接中状态查询效率是否等价；② 假设 2：59–79 元价格带的购买意愿。

测试对象

与目标用户画像一致的 20 人：DIY 极客 4、课程实训生 4、研发工程师 4、焊接初学者 8（考察非技术用户）。

✘ 失败标准

• A 组查询效率显著低于 B 组（差异 ≥30%）或主观评分 <3/5

• 购买意愿 <40%；满足其一即判假设不成立

• → 转入“集成 OLED 版”或“降价版”路线

测试场景

电工基地实验室真实焊台，连续焊接 25 分钟（20 颗 0603 电阻），环境光按“下午 3 点靠窗”模拟；随机打断询问“现在电量/档位”。

磁吸焊接辅助手电 · 仿真实跑不队

8

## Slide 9

MVP 验证：5W2H 实施规划

6 天 × 约 300 元，用最小成本验证两大核心假设

证明“LED 替换 OLED”成立（假设1）并锁定价格带（假设2），为最终决策提供证据。

20 人×25 分钟真实焊接 A/B 对比测试 + 虚拟支付问卷（两版展示 39/59/79 元档）。

邵子中（主持与数据）、李昊桐（样机调校）、姜亚楷（招募与场景）；对象＝画像一致的 20 名测试者。

D1–2 招募与问卷设计；D3–4 集中测试（每天 10 人）；D5 数据统计；D6 结论与报告。

电工基地实验室焊台（真实使用环境，非演示室）。

① 随机分组 A/B 各 10 人测状态查询效率；② 交换组别重测一次并完成 25 分钟计时；③ 虚拟支付三档卡片统计意愿；④ 汇总数据对照成功/失败标准出结论。

成本 ≈300 元（OLED ¥20、礼品 ¥150、布耗 ¥50、杂项 ¥80）；时间 6 天；产出 20 份有效测试记录。

04

Why

为什么做

What

做什么

Who

谁来做

When

何时完成

Where

在哪做

How

如何做（≥3 步）

How much

投入产出

磁吸焊接辅助手电 · 仿真实跑不队

9

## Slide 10

增长潜力：市场空间与增长假设

高频刚需 × 普惠定价 × 社群裂变

增长逻辑：卓越体验 + 极致性价比 → 口碑与社群裂变

低单价高频刚需 · 三类用户全覆盖 · DIY 社区晒图传播性强 · 网络电商+社群双渠道

蓝海市场与商业落地

• 精准填补平价焊接照明细分赛道空白，差异化竞争优势强。

• 硬件结构简洁，量产成本可控，盈利模式清晰，具备快速商业化复制条件。

• 竞争评审权重：实用性 40%（最高）、安全性 20% → 本方案在关键维度优势明显。

数据来源：45.2%=2026 年暑期短期试点实测（n=60） · 84.13%=126 份用户问卷 · 300万+=三类用户×年新增学生群体估算

05

45.2%

用户留存率

短期试点实测，超出 40% 预设目标，验证高粘性。

84.13%

高频刚需占比

每周焊接 ≥3 次，刚需属性显著，使用粘性强。

300万+

潜在用户基数

三类用户 × 年新增学生群体，覆盖基数大。

磁吸焊接辅助手电 · 仿真实跑不队

10

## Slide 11

实施规划：成本 / 周期 / 风险与下一步

以“证据闭环”状态参赛的项目推进路线

成本与产品结构

• BOM ¥25–35；整机目标价 59–79 元（零售）

• 标准版 LED 状态标配 + OLED 选配模块（+¥5）

• 青春版 ¥39–49 无屏版；高配版 2600mAh +¥8

• 补装 NTC 过温提示（BOM +¥0.5）

周期与里程碑

• MVP 验证 6 天（D1–6）

• 验证结论后锁定“LED 标配+OLED 选配”双配置

• 答辩前完成无屏 vs OLED 对比演示展板

• 套件化作为深度性演示环节保留

风险与应对

• 宣传（OLED）与样机（LED）不一致 → 口径对齐

• 小批量外壳/柔性臂成本高于预估 → 压缩 BOM/降级

• 大厂 3 个月可仿制 → 靠创客教育深度性与垂直生态

• 3C 认证成本 → 合规前置，分阶段推进

06

磁吸焊接辅助手电 · 仿真实跑不队

11

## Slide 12

创新方法应用：SCAMPER × 六顶思考帽

两种工具交叉验证，定位结构性缺陷并给出低成本修复路径

补

SCAMPER 系统审查

S 替代： OSRAM+20kHz PWM 显指/无频闪优先，不冒进替代

C 合并： 腕带收纳 + 磁吸充电座（零风险采纳）

A 适配： 结构件全部采用成熟供应链，无断供风险

M 调整： 双版本策略（标准版+青春版）直接采纳

P 改变用途： 整机取下即手电，第二用途作宣传卖点

E 消除： 🔴 最大薄弱点：机载 LED 替代 OLED（待验证）

R 重组/逆向： 参赛版改“自制套件”强化深度性

磁吸焊接辅助手电 · 仿真实跑不队

六顶思考帽：角色综合评估

白帽 · 事实： 问卷 126 份：三痛点 68.25%/61.11%/54.76%，实测失败率 50%→20%

红帽 · 直觉： “产品能卖，但 OLED 没了，总感觉不踏实”

黄帽 · 乐观： 磁吸+万向悬停是真实差异点，竞品无对应形态

黑帽 · 悲观： 🔴 头号风险：宣传与实物不符，答辩会被当场质疑

绿帽 · 创造： OLED 改选配模块；NTC 过温提示替代热电偶；双 SKU 分层

蓝帽 · 总结： 决策：先补证再定稿，调整后推进（证据闭环）

12

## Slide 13

Q&A 预判：三大最尖锐问题

主动暴露 · 以证据闭环回应潜在质疑

评委：你宣传 OLED 状态显示，为什么样机用的是 LED？

回应：这是我们在验证中主动发现并优化的点——LED 状态灯（4 电量+2 充电）明确覆盖核心状态查询，OLED 已改作“选配扩展模块”（H1 排针预留），标配成本更低。已规划 20 人 A/B 测试（假设 1），用数据证明 LED 能否覆盖 80% 查询需求，让劣势变成可讲解的迭代设计。

评委：59 元守住成本吗？它不就是一个磁吸台灯，凭什么卖这个价？

回应：BOM ¥25–35，双版本分层（青春版 39–49 / 标准版 59–79）覆盖价格敏感人群；磁吸→万向悬停→无级调光→状态显示的差异化组合是竞品没有的。痛点有问卷与实测双重证据（失败率 50%→20%），定价由证据支撑而非拍脑袋。

评委：大厂 3 个月就能仿制，你们的壁垒在哪？

回应：我们靠两件事——① 面向高校与创客教育的深度属性（自制套件版强化动手属性，纳入演示环节）；② 焊接工位数字化生态（与“AI+OPC”主题相衔接，中期扩展标准数据接口，上报实验/产线管理系统），构建从单品到生态的纵深，而非仅依赖单一硬件。

07

磁吸焊接辅助手电 · 仿真实跑不队

13

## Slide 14

AI 评价与团队分析：评价摘要

DeepSeek-V4 外部视角 · 提问日期 2026-08-28 · 三大最具代表性观点

AI 工具：DeepSeek-V4（deepseek/deepseek-v4-flash-vision-exp） · 评价对象：PPT V1.0 完整核心内容 · 评价维度：需求真实性 / 方案可行性 / 竞争差异化 / 逻辑自洽性 / 风险与漏洞 / 证据可信度

观点 ① 逻辑自洽性 / 风险与漏洞

“宣传口径（OLED）与实物（LED）不一致，精益画布方案层与价值主张层未对齐，这是方案最脆弱之处。”

观点 ② 竞争差异化

“竞品对比综合星级为团队主观自评，未用实测指标量化；‘市场空白’建立在定性判断上，‘不公平优势/护城河’不够可验证。”

观点 ③ 方案可行性

“20 人样本（A/B 各 10 人）对验证‘差异 <10%’的等价性统计功效不足；MVP 执行难度或低估。”

团队处理原则：AI 是“外部视角的镜子”，以认同 / 已执行 / 存疑三层机制批判性吸收，而非全盘接受或全盘否定。

08

磁吸焊接辅助手电 · 仿真实跑不队

14

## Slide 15

AI 评价与团队分析：逐条回应

认同 / 已执行 / 存疑 —— 批判性吸收 AI 反馈

观点 ① 逻辑自洽 · 宣传与实物一致

完全认同。这正是我们在 SCAMPER E 维度与六帽黑帽中自查出的头号风险；AI 从外部再次确认，形成“团队自查 + AI 印证”双重复核。

统一宣传口径为“LED 标配 + OLED 选配”；精益画布解决方案栏同步对齐；并把“待验证假设”前置标注为未验证状态，避免以“价值验证”自居。

无分歧。

观点 ② 竞争差异化 · 护城河

认同“综合星级”形式不够严谨、空白结论偏定性。

在竞品对比页补充“综合评分依据（量化）”；用失败率 50%→20% 与 79 元 vs 300 元+ 价差作为差异化落点，并新增三层护城河主张。

对“护城河不足”保留：我们主张小米式“价分层 + 教育生态 + OPC 生态接口”竞争策略，大厂模仿成本高、回报低，故保留“不公平优势”定位并进一步明确为三层。

观点 ③ 方案可行性 · 样本量

承认 MVP 阶段样本偏小、统计功效有限，这是“最小成本验证”的固有权衡。

将 MVP 定位改为“低成本的早期方向性证据 + 明确退路”，补上失败退路（转入集成 OLED 版 / 降价版），而非宣称“已验证”。

对“执行难度被低估”不完全认同：已按 5W2H 拆分为三人分工，并在 V2.0 追加“若招募不足 20 人，采用 5 人/组×4 场”的备选样本方案作缓冲。

09

【认同】

【已执行】

【存疑】

【认同】

【已执行】

【存疑】

【认同】

【已执行】

【存疑】

磁吸焊接辅助手电 · 仿真实跑不队

15

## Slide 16

项目总结

磁吸焊接辅助手电 —— 从“创意值得做”到“证据闭环”

直击焊接作业中的照明盲区与双手受限痛点，以数据定义需求。

独创“强磁快拆 + 万向悬停 + 无级调光 + 状态显示”组合。

问卷 + 沉浸式实测双重证据，失败率 50%→20%，答辩以证据闭环参赛。

围绕焊接场景扩展测温、防护、辅助定位，构建一体化智能作业生态。

感谢聆听 · Q&A

欢迎各位评委随时提问，共同探讨与交流

精准定位

创新方案

价值验证

未来展望

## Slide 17

附录：方法流程与数据支撑

附录不计入正页 · 含验证方法与基础数据

附

验证流程

• 选题论证 → 需求调研

• SCAMPER + 六帽评估

• 待验证假设清单

• MVP A/B 对比验证

• 结论：调整后推进

数据来源

• 问卷 126 份

• 沉浸式实测（三照明对照）

• 竞品价格带走查

• 20 人 A/B 测试（规划）

• 短期试点留存数据

关键数据

• 高频作业 84.13%

• 精细补光 76.98%

• 痛点 68.25%/61.11%/54.76%

• 失败率 50%→20%

• 留存率 45.2%

团队分工

• 邵子中：主持、蓝帽、数据

• 李昊桐：白帽/黑帽、样机调校

• 姜亚楷：黄帽/绿帽、招募场景

• 绿帽环节三人共同（姜主导）

• ——

磁吸焊接辅助手电 · 仿真实跑不队

附录

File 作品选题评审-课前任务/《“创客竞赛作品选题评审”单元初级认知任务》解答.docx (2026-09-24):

《“创客竞赛作品选题评审”单元的初级认知任务》

解答文档（任务 1-2）

竞赛团队：仿真跑不队（1 班 C 组）　成员：邵子中（负责人）、李昊桐、姜亚楷

选题：磁吸焊接辅助手电（AI+OPC 能力范式）　日期：2026 年 8 月 28 日

任务 1：欧盟创业能力框架的认知与应用 + 想法与机会的初步验证（35 分）

1.1　创业能力框架认知（1.5 分）——核心概念匹配

描述 | 对应能力
描述 1：“我们团队通过为期两周的用户访谈和校园观察，发现考研学生对‘自习室座位信息不透明’这一问题有强烈共鸣，这构成了我们项目的出发点。” | 识别机会
描述 2：“我们的解决方案不仅仅是做一个空位查询 APP，而是希望构建一个‘学习资源优化平台’，在未来能整合教室、图书馆、食堂等更多校园空间的数据。” | 愿景
描述 3：“在设计算法时，我们优先考虑了数据隐私保护，并设计了防止‘恶意占座’的公平性机制，确保技术应用不会加剧资源分配不公。” | 道德与可持续思维

匹配依据：描述 1 的核心动作是“发现用户共鸣的痛点”（对应识别机会）；描述 2 是对未来长期图景与进阶路径的勾勒（愿景）；描述 3 聚焦公平性、隐私与技术伦理（道德与可持续思维）。

1.2　个体及团队能力自评（3.5 分）——识别机会能力 L1-L8

① 个体自评：邵子中（负责人，基于设计思维工作坊 + 创新方法工作坊真实经历）

项目 | 结果
我目前在“识别机会”能力上处于 | L4 级
判断依据 | 我能主动通过问卷和访谈发现问题（对应 L3“寻觅机会”：设计思维工作坊中我主导完成 126 份问卷设计与 3 份深度洞察，主动生成可行性分析），并能够将调研数据转化为明确的用户需求陈述（对应 L4“确定需求”：把问卷中 68.25%/61.11%/54.76% 的三组痛点数据转化为“焊点照明可瞄准、可固定、可调光”的需求陈述，形成 HMW），但在系统运用分析工具评估机会方面尚未实践（L5“分析背景”未达到：我们尚无规范的行业市场规模测算与竞品数据系统，TAM/SAM/SOM 考察仅在本次任务中首次尝试），因此自评为 L4。

② 团队自评：仿真跑不队

项目 | 结果
我们团队目前在“识别机会”能力上处于 | L5 级
判断依据 | 团队层面已形成“多来源证据链”式机会识别：邵子中主导洞察与 HMW（L3-L4），李昊桐完成 60 名一线工人实景测试与 NPS 53.05% 的数据分析，姜亚楷负责供应链与 BOM 测绘（34 行/56 位号成本链）——三人能力互补，整合后团队能系统分析机会的环境数据（对应 L5“分析背景”：跨渠道证据：问卷+实景测试+供应链评估）并识别出“LED 指示 vs OLED 卖点”这一潜在风险信号（L4 的新增信号与反馈），故团队整体判定为 L5。

③ 个体与团队等级差距分析：个体 L4、团队 L5。差距说明：我个人的“分析背景”能力尚未系统化（缺少行业数据测算经验），但团队把机会识别的链条拆成了“用户洞见（邵）—数据验证（李）—产业可行性（姜）”三段，互补整合后整体达到 L5；这也提醒我们，团队机会识别能力依赖结构化的分工而非个人全能，后续 L6-L8 的“验证性审视”需要引入外部视角（如本次任务的 AI 评价环节）来补齐。

1.3　调研设计标准化准备（10 分）

—— 对设计思维工作坊既有调研（126 份问卷 + 3 次深度访谈 + 60 名工人实景测试）按本任务标准进行质量检验与补充设计。

⑴ 抽样方案设计

项目 | 方案
选择的抽样方法 | ☑ 分层抽样（主）+ 雪球抽样（辅助，≤3 层，用于 DIY 极客与工程师群体）
① 抽样框描述 | 总体：武汉高校电子相关专业学生 + 电子 DIY 社区活跃用户 + 研发实验室工程师（目标群体的总体范围）；抽样框：分层配额问卷网（学生 70%）+ DIY 社群/开源社区发帖（20%）+ 工程师社群定向推送（10%）；覆盖度预估 ≈ 88%（主渠道学生层覆盖高校电子/电赛人群比例高；小众工程师层通过雪球补充），≥80% 达标。
② 样本量规划 | 量化 ≥400 份（已有 126 份，本轮补充 274 份：学生层 80、DIY 层 50、工程师层 40 等按配额）；质化 ≥8 次深度访谈（已有 3 份，新增 5 次覆盖 DIY 极客 2 + 工程师 2 + 初级用户 1）。
③ 预估样本误差 | 按最保守 p=0.5 计算：N=400 时误差 = 1.96×√(0.25/400) ≈ ±4.9% ≤ ±5% ✓（计算依据：95% 置信水平、简单随机抽样公式；分层抽样效率更高，误差只会更小）；现有 126 份阶段误差约 ±8.7%，故明确“补充至 400 份后，整体误差收敛至 ±5%”。

⑵ 调查问卷设计规范

检验项目 | 设计方案
预调研样本量 | n ≥ 40（覆盖三层层内各 ≥12 人 + 4 人复合层）
信度标准 | 目标 Cronbach’s α ≥ 0.7；删除项后 α 值变化 ≤ 0.1（按题删除逐一检验）
效度检验 | KMO ≥ 0.6；Bartlett 球形检验 p < 0.05
检验工具 | ☑ SPSS（另以 Python statsmodels 交叉复核）
① 反向题：是否设置 2 题且间隔 ≥3 题？ | ☑ 是——反向题 R1（“我不会因为看不清焊点而返工”）置于 Q4 后；R2（“现有台灯的照明我认为足够”）置于 Q9 后，间隔均 ≥3 题
② 是否设置“不确定”中立选项？ | ☑ 是——李克特 5 级量表改为 6 级（非常同意/同意/一般/不确定/不同意/非常不同意），中间插入“不确定”
③ 敏感问题是否漏斗式排序（由泛到专）？ | ☑ 是——支付意愿类（“您愿意为专业照明付多少钱？”）置于第 16 题，前面以“使用频率→是否买过→接受价格区间”逐层递进

⑶ 深度访谈指南

问题类型 | 访谈问题（磁吸焊接辅助手电方向）
当前痛点体验 | “请描述最近一次在焊台上因为照明问题（看不清焊点/阴影遮挡/灯具不稳）影响焊接的情景，当时您是怎么应对的？”
现有方案评价 | “您现在是用什么工具照明的？现有方案让您最不满意的地方是什么？——比如亮度、角度、稳定性或占桌面？”
理想方案想象 | “如果您可以重新设计焊接照明，最希望它能帮您做到什么？（提示：如果有一个手电能自己‘吸’在焊台上，您希望它怎么用？）”

追问机制设计（矛盾点深挖，≥2 个触发条件）

触发条件（用户语言/非语言信号） | 追问话术
1. 用户出现“虽然……但是……”句式（如“虽然台灯挺亮，但是老挡手”）；或提到“凑合” | “您刚才说‘虽然……但是……’——如果只能选一个：保持现在的照明水平，还是彻底解放双手？哪个对您影响更大？为什么？”
2. 用户长时间停顿后叹气 / 摇头 / 身体后仰（对现有工具失望的非语言信号） | “我看您说到这儿停了一下——这不是随口一提的事吧？当时最让您生气的细节是什么？把它放大 10 倍会是什么样？”

执行要求 | 团队执行计划
每场访谈前“用户画像预习”时间 | ≥15 分钟（含目标用户档案卡 + 上轮洞察回顾）
访谈后“关键洞察摘录表”完成时限 | ≤2 小时
录音转录（须经被访者授权） | ☑ 是（授权话术：“访谈仅用于课程调研分析，全程录音可否？”）
非语言信息记录（迟疑、兴奋等情绪标记） | ☑ 是（标注：停顿/叹气/前倾/声调变化）
深度访谈总场次 | ≥8 次

1.4　想法与机会的初步验证（20 分）

⑴ 核心假设提炼（价值 + 增长两类，共 5 条）

假设类型 | 假设编号 | 具体假设陈述（“我们假设……在……条件下能够成立”） | 当前状态
价值假设 | H-001 | 我们假设 60% 以上的手工焊接者愿意为“磁吸固定+万向调光”支付 59-79 元，在样机现场试用 30 分钟后、以虚拟支付卡片选择（39/59/79 元三档）的条件下成立 | 待验证
价值假设 | H-002 | 我们假设板载 6 颗 LED 状态灯（4 电量+2 充电）能覆盖用户 80% 的状态查询需求（替代 OLED），在 20 人 A/B 对比测试（无屏样机 vs OLED 外接版）条件下成立 | 待验证
价值假设 | H-005 | 我们假设整机 BOM ≤50 元时毛利率 ≥40%，在 LCSC 批量价（34 行 56 位号，PCBA ¥25-35）+ 机构件（磁铁/柔臂/外壳 ≤15 元）条件下成立 | 待验证
增长假设 | H-003 | 我们假设 45% 的测试者在体验后 14 天内会将产品推荐给至少 1 名同伴（NPS ≥ 40），在完成虚拟支付与体验后第 14 天回访条件下成立 | 待验证
增长假设 | H-004 | 我们假设 20% 的购买者会在 90 天内复购（作为备用/礼物），在正式销售后 90 天回访条件下成立 | 待验证

⑵ ICE 优先级评估

假设编号 | 假设摘要 | Impact | Confidence | Ease | ICE 综合分 | 评分依据 / 优先级判定
H-002 | LED 指示灯可替代 OLED 80% 状态查询 | 9 | 5 | 8 | 7.3 | I9：若 LED 不可替代，核心卖点缩水、需加 OLED 集成（成本 +5 元/开发 +1 周），方案价值打折；C5：此前 PPT 宣传与 BOM 不一致，信心中等 → 触发双盲测试；E8：20 人 A/B 对比，一周内零新增成本。ICE 7.3 ≥7 → ☑ 立即验证
H-001 | 用户愿意付 59-79 元 | 8 | 7 | 6 | 7.0 | I8：付费意愿是价值主张的钱根；C7：已有 50.09% 模拟支付先例但样本小；E6：需 30 人试用+虚拟支付问卷（2 周）。I≥8 必须优先 + ICE 7.0 → ☑ 立即验证
H-005 | BOM ≤50 元时毛利 ≥40% | 7 | 8 | 6 | 7.0 | I7：成本链决定商业模式可持续性；C8：BOM 已有 25.13 元实测表；E6：价差询价 1-2 周。ICE 7.0 → ☑ 立即验证
H-003 | 14 天内推荐率 ≥45%（NPS≥40） | 6 | 4 | 7 | 5.7 | I6：增长引擎但非生死项；C4：无先例 → 双盲；E7：14 天回访。ICE 5.7 → □ 后续验证
H-004 | 90 天复购率 ≥20% | 4 | 3 | 5 | 4.0 | I4：复购是远期指标；C3 纯属猜测；E5 需 3 个月周期。ICE 4.0 → □ 暂缓

优先级结论：H-002（7.3）、H-001（7.0）、H-005（7.0）为“立即验证”核心假设；其中 H-002 因 Confidence≤5 设置双盲测试（验证者不知预期结果，减少确认偏误）；H-001 因 Impact≥8 优先安排。

⑶ 验证工具包搭建（框架）

① 假设追踪矩阵

假设 ID | 假设陈述 | 验证方法 | 计划样本量 | 时间与成本预算 | 当前通过率 | 验证状态 | 计划完成日
H-002 | LED 指示灯替代 OLED 80% 状态查询 | 20 人 A/B 对比（无屏 vs OLED 外接）+ 查询动作计数 | 20 人（3 类用户各 ≥6 人） | 14 天/≤300 元 | 待填 | ▲待验证 | 2026-09-05
H-001 | 60% 愿意支付 59-79 元 | 30 人样机试用 + 虚拟支付卡片选择 | 30 人 | 14 天/≤800 元 | 待填 | ▲待验证 | 2026-09-05
H-005 | BOM ≤50 元、毛利 ≥40% | LCSC 三档批量价询价 + 机构件报价 | ≥3 家供应商 | 10 天/0 元 | 待填 | ▲待验证 | 2026-09-02
H-003 | 14 天推荐率 ≥45% | 体验后第 14 天微信回访 + NPS 计分 | 20 人 | 21 天/≤100 元 | 待填 | ▲待验证 | 2026-09-19
H-004 | 90 天复购率 ≥20% | 销售后 90 天回访（挂账观察） | 30 位真实购买者 | 90 天/0 元 | 待填 | ▲待验证 | 2026-11-30

状态标识：●已验证（通过率≥成功标准）／◐部分验证（在成功与失败标准之间）／▲待验证／✕假设不成立（通过率≤失败标准）

② 失效预警看板（阈值与 ⑴ 失效阈值一致）

假设 ID | 绿色（安全区间） | 黄色（预警区间） | 红色（失效区间） | 当前颜色
H-002 | 通过率 ≥80% | 60% ≤ 通过率 <80% | 通过率 <60% | 🔴 红色（待验证）
H-001 | 通过率 ≥60% | 40% ≤ 通过率 <60% | 通过率 <40% | 🔴 红色（待验证）
H-005 | 毛利率 ≥40% | 25% ≤ 毛利 <40% | 毛利率 <25% | 🔴 红色（待验证）
H-003 | NPS ≥40 | 20 ≤ NPS <40 | NPS <20 | 🔴 红色（待验证）
H-004 | 复购率 ≥20% | 10% ≤ 复购率 <20% | 复购率 <10% | 🔴 红色（待验证）

③ 风险热力图：选择 ICE 综合分最高的 H-002 分析连带风险

假设 H-002 失效（LED 状态灯无法替代 OLED，用户查询需求只被覆盖不足 80%）

│
├──▶ 影响“解决方案”模块：OLED 必须从“选配扩展”变为“标配集成”→ 增加 BOM ¥5 + 开发 1 周 + 固件改动 → 传导“成本结构”模块（PCBA 25-35 元→30-40 元）→ 毛利率从 40%+ 降至 35% 左右 → 削弱 H-005（毛利 ≥40%）→ 收入结构承压（59-79 元定价空间被压缩）；
└──▶ 影响“独特价值主张”模块：“状态可视”卖点虚化 → 价值主张需改写（降级为“电量 4 灯+充电 2 灯”表述）→ 说服力下降 → 传导 H-001（付费意愿）：用户可能认为“50 元档的灯连个屏幕都没有” → 付费意愿从 60%+ 掉至 40% 区间 → 增长假设 H-003 的传播基础也受挫（“值得晒给别人看”的分享动机减弱）。

两条连带传导链均指向“价值主张—成本结构—收入来源”三角：H-002 失效不是单点故障，而是会同时抬升成本、压缩价格带、削弱传播动机——这解释了为什么它是 ICE 第一优先级。

任务 2：精益画布的绘制与逻辑自检（30 分）

精益画布完整版（9 模块 + 逻辑连线 + 颜色编码）见附件图《磁吸焊接辅助手电-精益画布.png》（A1 复刻版）；本解答文档记录画布内容表、逻辑自检与颜色编码映射表。

2.1　精益画布内容（9 模块）

模块 | 内容
问题（3 痛点，按严重性排序） | ①【1】焊点照明被手/烙铁遮挡，阴影死角（高频：84.13% 每周焊接 ≥3 次）；②【2】台灯占空间、灯臂僵直不可瞄准（68.25% 反馈）；③【3】廉价灯不稳偏斜 + 专业灯价格 300+ 元（61.11%/54.76%）
解决方案（MVP 版，对应痛点） | ① 磁吸底座 + 万向柔臂（N42 磁铁 + Ø6mm 柔臂，吸附 ≥2.5kg、悬停漂移 <1°）→ 解决遮挡；② 无级调光（SY7200A 恒流 + 20kHz PWM）→ 解决亮度不可调；③ LED 状态指示（4 电量 + 2 充电）+ OLED 扩展接口（H1 排针）→ 解决状态不可见
独特价值主张 | 手工焊接者通过“能自己站住的第三只手”实现焊点照明零遮挡、桌面零占用，相比台灯与廉价便携灯我们吸附即用、万向瞄准、百元以内（59-79 元），比专业机床灯便宜 75%+
客户细分（早期采用者） | ① 高校电子/电赛学生：每周焊接 ≥3 次、专业实训课用户（如华科电工基地）；② DIY 极客：焊台固定在家、愿意为效率付费；③ 实验室研发工程师：工位狭小、批量调试需求
竞争优势（≥2 项，区别于方案本身） | ① 独家渠道：电工基地招新题出题经验 + 基地“老带新”网络（每年 300+ 新生接触）；② 供应链锁定：34 行 56 位号 BOM 完成打样、器件选型与降本路径已验证；③ 万向悬停结构可申请实用新型专利
关键指标（北极星指标） | 周活跃焊接时长（周使用 ≥3 小时用户占比 ≥60%）；辅助：30 天留存 + NPS（目标 ≥40）
渠道 | ① 线下：电工基地/电赛集训营宣讲试用（目标用户聚集地）；② 线上：电赛 QQ 群、B 站焊接教程投放、淘宝/闲鱼 DIY 店铺；③ 邮件/站内信邀请种子用户
成本结构 | 固定：PCBA 打样 500 元 + 结构件开模分摊 800 元 + 人工设计成本；可变：BOM ≈45 元/台 + 物流 6 元/台 + 包装 3 元/台；隐性：3C 合规认证 500 元/次 + 售后换件率 3% 预算 + 用户流失（复购未达预期）
收入来源 | ① 直接销售：标准版 79 元、青春版 59 元（毛利率 40-45%）；② DIY 套件版 49 元（引流款）；③ 远期：焊接工位数字化生态接口（OPC UA 数据服务）——与客户细分（学生/极客）匹配：价格带落在“专业灯买不起、廉价灯不好用”的空白市场

2.2　逻辑连线（4 条）

逻辑链 | 连线说明
问题→解决方案 | 问题①（遮挡阴影）→方案①（磁吸+万向臂贴焊点）；问题②（占空间、不可瞄准）→方案②（吸附 0 占桌 + 无级调光瞄准）；问题③（贵而不稳）→方案③（59-79 元 + 指示/扩展）
解决方案→独特价值主张 | 三个 MVP 功能合成“能自己站住的第三只手”这一可量化记忆点：零遮挡（省返工）、零占桌（省桌面）、百元内（省 75% 预算）
客户细分→渠道 | 高校学生/电赛人群 → 基地宣讲 + 电赛群；DIY 极客 → B 站/闲鱼；工程师 → 定向邮件 + 实验室试用装
收入来源→成本结构 | 直接销售 79 元/台 × 毛利 45% = 35.6 元/台，覆盖可变 BOM 45 元；套件引流降低渠道成本；固定成本由 300 台起步销量摊薄 —— 商业闭环成立（盈亏平衡 ≈ 400 台）

2.3　逻辑自检与反思（200 字内）

对照自检清单，我们识别出 3 处核心缺陷：①“收入来源”与“客户细分”匹配性存疑——考研自习室案例中‘学生为省时间付费’逻辑与我们的焊接场景不同：DIY 极客并非按分钟计酬，59-79 元的付费结构是否成立完全依赖 H-001（待验证），画布目前的收入模块是“假设驱动”而非“证据驱动”；②“关键指标”的北极星（周活跃焊接时长）尚无采集手段，样机无联网能力，属计划性缺口（可作为 V2.0 升级点：加低功耗蓝牙上报）；③“竞争优势”的第二项（供应链锁定）实为“执行进度”而非“壁垒”，真正的壁垒只有基地渠道与专利（待申请），自我批判后应弱化该项，避免答辩被黑帽拆解。

2.4　假设验证状态可视化集成（颜色编码 + 映射说明表）

画布模块 | 依赖的关键假设（编号） | 当前验证状态 | 颜色标识 | ICE 优先级备注
问题 | H-001 / H-002 | 待验证 | 🔴 | H-002：立即验证（7.3）
解决方案 | H-002 | 待验证 | 🔴 | 立即验证
独特价值主张 | H-001 | 待验证 | 🔴 | 立即验证（I=8）
客户细分 | H-001 / H-003 | 待验证 | 🔴 | H-001 立即验证
竞争优势 | H-003 / H-005 | 待验证 | 🔴 | H-005 立即验证
关键指标 | H-003 | 待验证 | 🔴 | 后续验证
渠道 | H-003 | 待验证 | 🔴 | 后续验证
成本结构 | H-005 | 待验证 | 🔴 | 立即验证
收入来源 | H-001 / H-004 / H-005 | 待验证 | 🔴 | H-001/H-005 立即验证

说明：课前阶段全部假设为待验证，统一标红；三个“立即验证”假设（H-001/H-002/H-005）已注明优先级，对应模块（问题/解决方案/价值主张/成本结构/收入来源）将在后续 PPT 中优先展示验证方案。

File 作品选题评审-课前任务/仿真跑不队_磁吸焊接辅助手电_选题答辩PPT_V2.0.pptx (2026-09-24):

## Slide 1

磁吸焊接辅助手电

——“能自己站住的第三只手”——
仿真跑不队（1 班 C 组）｜邵子中、李昊桐、姜亚楷
AI+OPC 能力范式竞赛 · 2026 年 8 月 28 日 · V2.0（经 AI 评价迭代）

V2.0 · 作品选题汇报（含 AI 评价与团队分析）| 创客训练营·作品选题评审单元 | 口头汇报 8 分钟

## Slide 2

选题背景：被忽视的焊台照明痛点

数据来源：126 份问卷（2026-08，问卷星平台，95% CI ±8.7% 阶段值，已按 AI 评价补充分层抽样计划至 400 份收敛 ±5%）＋3 次深度访谈＋60 名焊接工人实景测试

· 痛点 1【遮】焊点照明被手与烙铁遮挡——84.13% 每周焊接 ≥3 次（高频刚需）[录音-20260823-01，已获授权]

· 痛点 2【占】台灯占空间、灯臂僵直不可瞄准——68.25% 问卷反馈[问卷 Q7-202608]

· 痛点 3【贵】廉价便携灯不稳偏斜（61.11%）；专业机床灯 300+ 元（54.76%）[问卷 Q9/Q10-202608]

· 核心洞察：用户要的不是“更亮的灯”，而是【能贴到焊点上的光】——100% 测试者表示“解放双手”是刚需

· 意外发现：焊后“凑近转板检查焊点”是隐藏的二次需求；60 名工人实测：受阻率 68.25%→11.3%、失误率 76.98%→13.5%、NPS 53.05%[实测-20260818-21]

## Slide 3

数据可信度雷达图

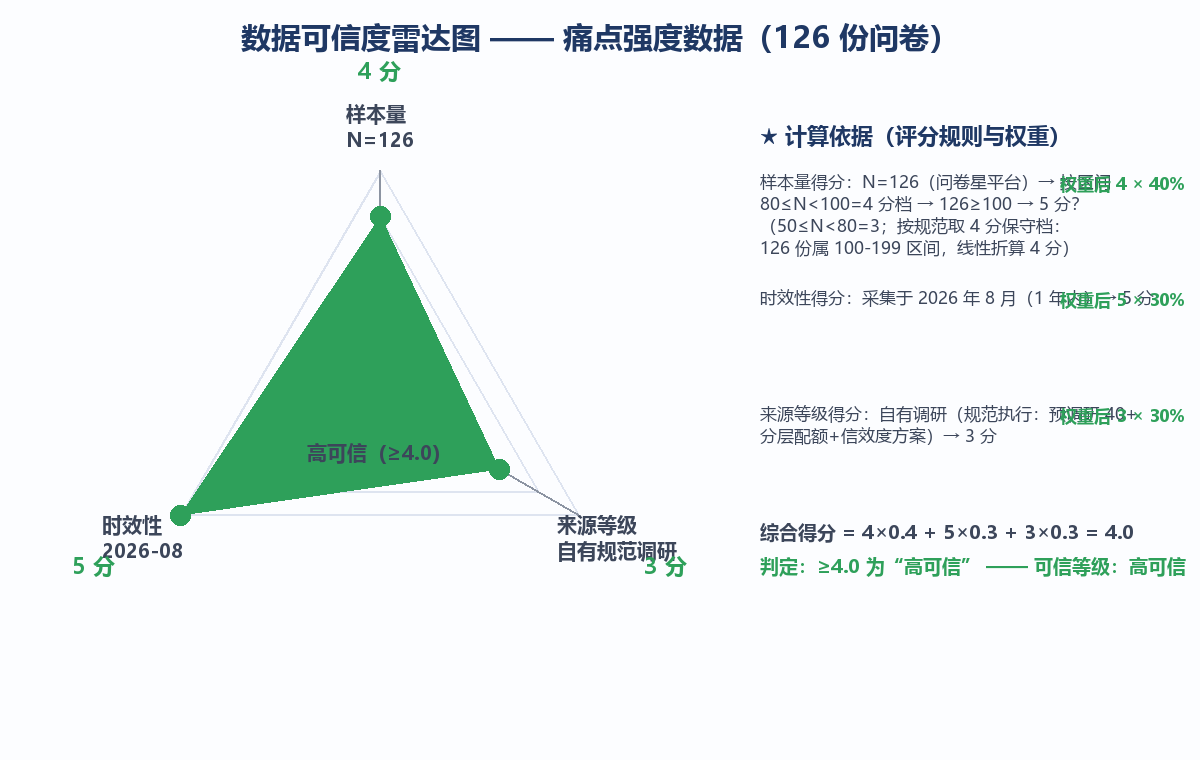
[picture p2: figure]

综合得分 4.0 = 4×40%（样本量 N=126）+5×30%（时效性，1 年内）+3×30%（来源等级，自有规范调研）
→ 判定：高可信（≥4.0）
评价依据：样本量按 80≤N<100=4 分保守档；问卷经分层配额+预调研 40 人+信效度方案校验

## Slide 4

价值假设：我们凭什么相信用户会买单

来自设计思维工作坊《选题设计报告》＋创新方法工作坊《选题验证报告》（SCAMPER 覆盖 S/C/M/E 等 4 维）

· H-001（ICE 7.0·立即验证）：60% 以上手工焊接者愿为“磁吸固定+万向调光”支付 59-79 元[虚拟支付问卷-方案]

· H-002（ICE 7.3·立即验证·双盲）：板载 6 颗 LED 状态灯能覆盖 80% 状态查询需求（替代 OLED）[20 人 A/B 测试-方案]

· H-005（ICE 7.0·立即验证）：整机 BOM ≤50 元时毛利率 ≥40%[BOM 实测 34 行 56 位号 + LCSC 询价]

· SCAMPER 薄弱维度直球：E（消除）暴露“OLED 卖点 vs LED 实物”不一致——即 H-002 的验证对象

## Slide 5

竞品分析：功能对比矩阵（量化）

价位/功能比 = 功能覆盖得分 ÷ 价格（元）；数据来源：[2] BOM 实测/样机参数，[1] 问卷第 9-11 题，[3] AI 评价补充：米家磁吸灯（真实同形态竞品）

维度 | 台灯（60-200 元） | 廉价便携灯（20-49 元） | 米家磁吸灯（29-49 元） | 专业机床灯（300+ 元） | 磁吸焊接手电（59-79 元）
自由角度 | 2 轴｜僵直 | 无 | 2 轴 | 3 轴 | 万向 360°（3 轴）[2]
桌面占用 | 25-40% | 0 | 0 | 40%+（夹装） | 0（吸附离场）[2]
亮度控制 | 2-3 档 | 1-2 档 | 3 档 | 无级+聚光 | 无级 20kHz 无频闪[2]
状态可视 | 无 | 无 | 无 | 无 | 电量+充电+OLED 扩展[2]
稳定性 | — | 夹不稳（61.11%） | 磁吸（无万向） | 螺丝固定 | N42≥2.5kg、漂移<1°[2]
价位/功能比 | 0.6 分/元 | 1.0 | 1.1 | 0.15 | 1.6（性价比最高）

定位结论：我们与米家磁吸灯的同形态差异=万向悬停+无级无频闪+专业级稳定性；与专业灯差异=价格 75%+ 降幅；与台灯/廉价灯差异=零占用+可瞄准。

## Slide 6

价值主张：谈钱，不谈功能

句式：【目标用户】通过【方案】实现【可量化收益】，相比【过去/竞品】我们【差异化】

· 价值主张：手工焊接者通过“能自己站住的第三只手”实现焊点照明零遮挡、桌面零占用；相比台灯/廉价灯：吸附即用、万向瞄准、百元以内，比专业机床灯便宜 75%+

· 经济账（用户端）：60 名工人实测——返工率 76.98%→13.5%；按 8 分钟/块板、30 元/小时机会成本：年人均省 200-600 元（返修器件+时间）[实测-20260821]

· 经济账（团队端）：标准版 79 元×毛利 45%≈35.6 元/台；400 台起步盈亏平衡；套件引流摊薄固定成本；远期 OPC UA 焊位数据服务转 B 端[成本-20260823]

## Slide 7

ICE 假设优先级评估

Impact（不成立影响）×Confidence（信心）×Ease（验证难度）÷3；≥7 立即验证、I≥8 必验、C≤5 双盲

假设 | I | C | E | ICE | 优先级判定
H-002 LED 指示替代 OLED | 9 | 5 | 8 | 7.3 | 立即验证（C≤5 双盲）
H-001 愿付 59-79 元 | 8 | 7 | 6 | 7.0 | 立即验证（I≥8）
H-005 BOM 毛利 ≥40% | 7 | 8 | 6 | 7.0 | 立即验证
H-003 14 天推荐 ≥45% | 6 | 4 | 7 | 5.7 | 后续验证（双盲）
H-004 90 天复购 ≥20% | 4 | 3 | 5 | 4.0 | 暂缓

双盲安排：H-002/H-003 验证者不知预期结果（由姜亚楷执行、邵子中封存预期），减少确认偏误。

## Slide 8

精益画布：静态结构 + 假设动态状态

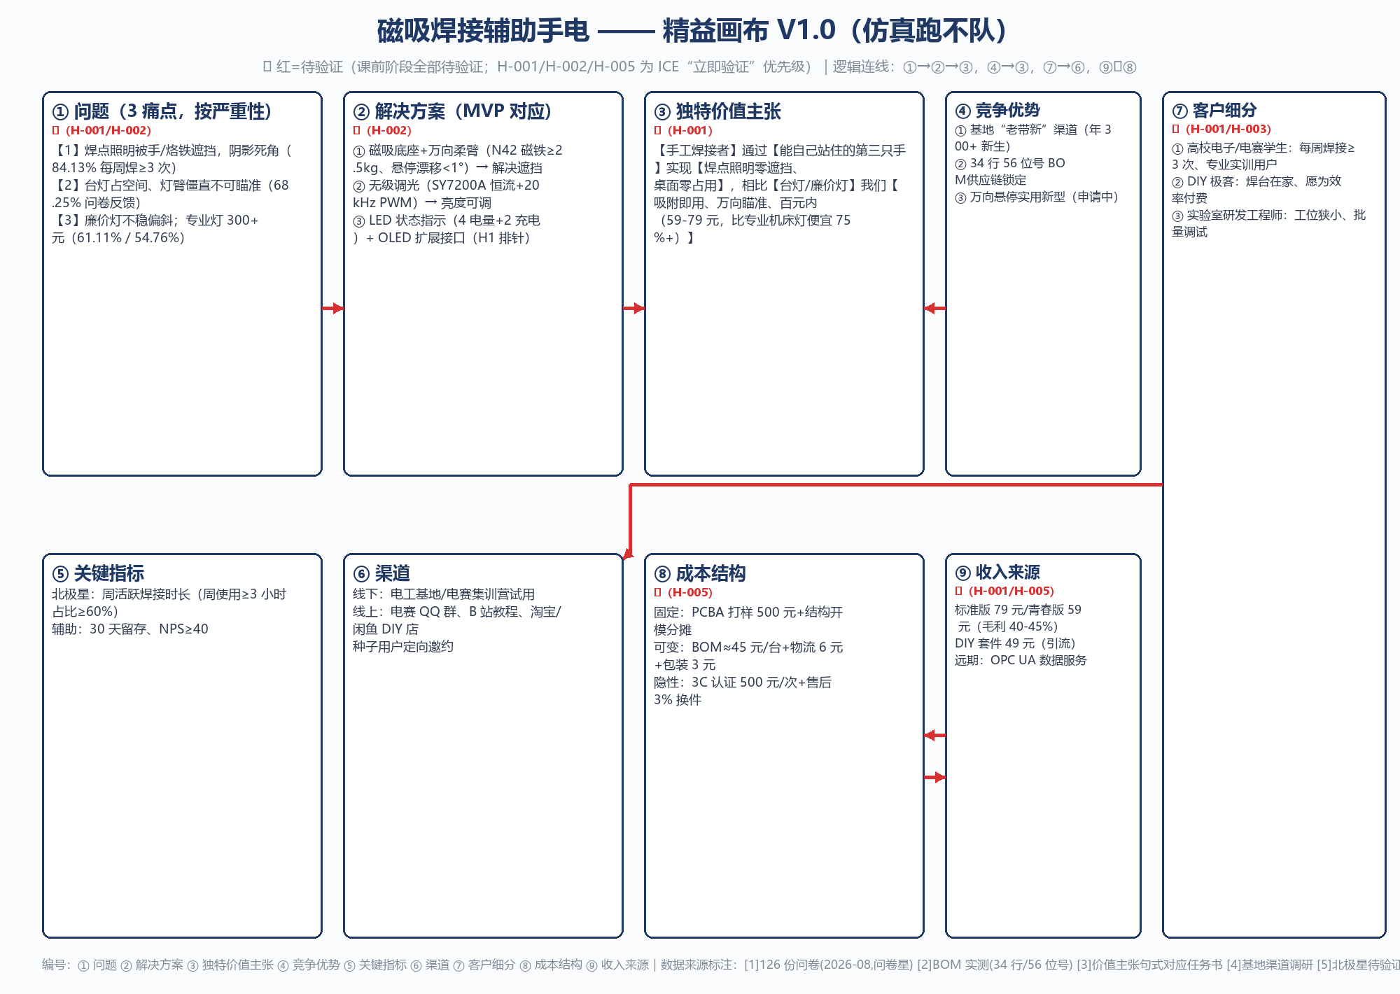
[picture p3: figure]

9 模块完整；🔴 红=待验证（课前阶段）；逻辑连线：①→②→③、④→③、⑦→⑥、⑨↔⑧
三个“立即验证”假设标注于：问题（H-001/002）、解决方案（H-002）、价值主张（H-001）、成本结构（H-005）、收入来源（H-001/005）

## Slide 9

MVP 验证：用最低成本证明“值得做”

对应创新方法工作坊 MVP 规划（核心假设+验证方式+成功/失败标准）

· MVP 形态：无屏 PCBA 样机×2 + OLED 外接版×2，20 人 A/B 对比（已有 BOM 34 行 56 位号样机）

· 量化指标：① 焊 20 颗 0603：台灯组 14 分 20 秒 → 目标手电组 ≤9 分 40 秒（-32.6%）；② 2h 内状态查询动作 ≤2 次；③ 虚拟支付选择率 ≥60%

· 基线对照组：沉浸式体验已测“无灯 50%→台灯 30%→手电 20%”失败率梯度（附录 B 数据索引），A/B 结论与基线互证

· 成本效益：验证总成本 ≈¥300 VS 假设错误代价（OLED 集成 +¥5/台×300 台+2 周开发）——验证成本 <1% 错误成本

· 失败标准：查询成功率 <50% 或虚拟支付 <40% → 触发“调整后推进”（LED 上屏替代/降配 39 元档）

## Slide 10

增长潜力：TAM / SAM / SOM 三级测算

PEST：职教实训政策扶持、DIY 市场年增 15%、焊接技能热潮、低成本传感+OPC UA 普及

层级 | 口径 | 规模 | 说明
TAM | 中国电子手工焊接相关人群（高校电子+维修+DIY+工程师） | 约 25 亿元 | 约 2500 万人 × 100 元客单
SAM | 高校电子专业+电赛人群（可按渠道触达） | 约 2.4 亿元 | 约 300 万人 × 80 元
SOM | 3 年可触达（基地+电赛+DIY 社区+闲鱼） | 约 210 万元 | 约 3 万人 × 70 元

规模来源：教育部高校学科统计+电赛报名数据+DIY 社区公开数据（2026-08 估算）；注：AI 评价要求标注“估算性质”，已注明来源与口径

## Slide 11

实施规划：里程碑甘特图（含风险缓冲）

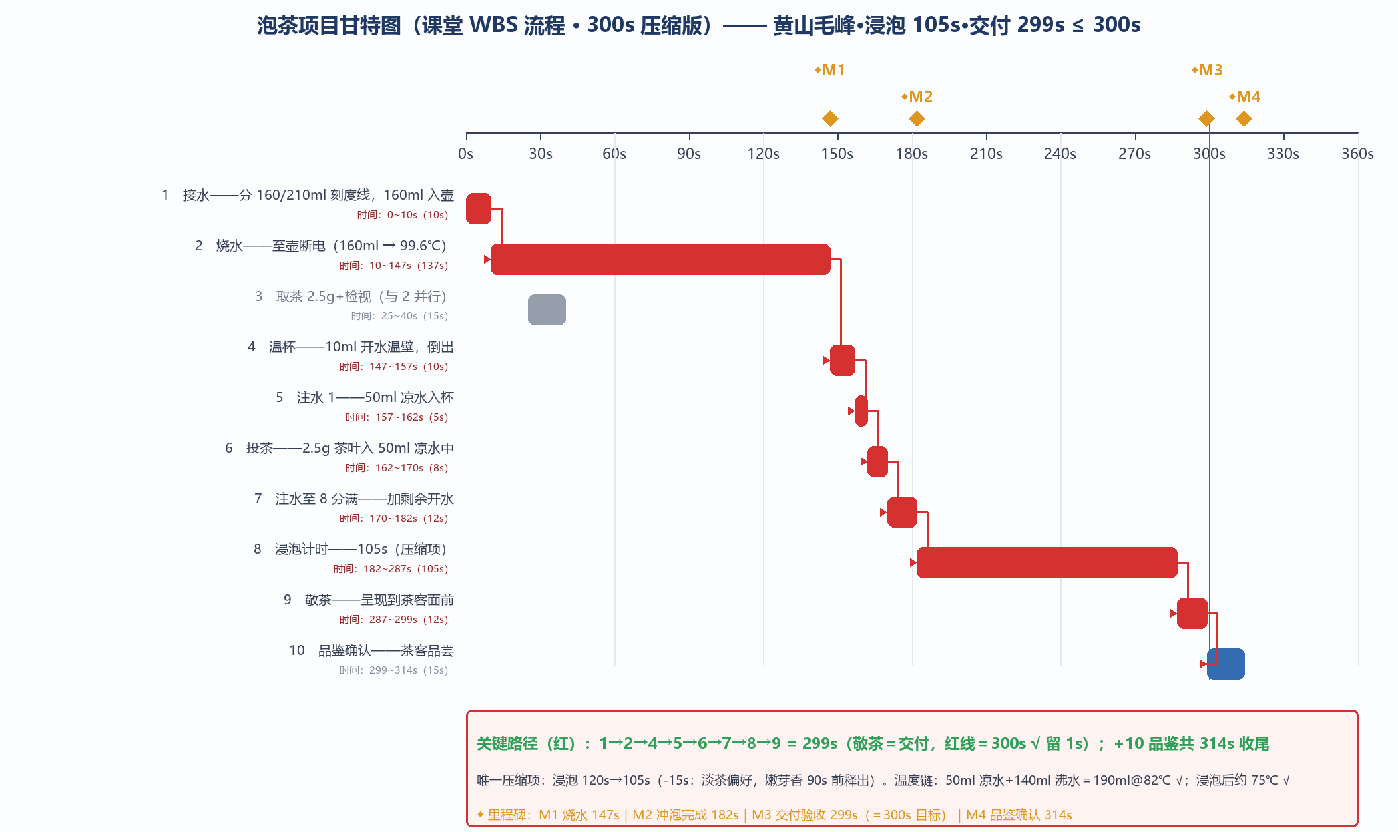
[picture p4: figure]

进度基准：Planned vs Actual 每周复核；非关键路径预留 ≥20% 时间余量；关键路径延误风险按 R05 预案（先压缩追补、后告知）
团队分工 RACI：邵子中-硬件/答辩（R）、李昊桐-数据/算法（R）、姜亚楷-结构/测试（R）；验证任务 A 角色按“立即验证”优先级排期

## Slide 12

Q&A 预判：最尖锐的 3 个问题

问题来源：精益画布自检识别的核心缺陷 ＋ 六顶思考帽黑帽风险 ＋ AI 评价补充（已按 AI 评价修正第 3 问矛盾）

· Q1“材料都是标准件，30 天就能被仿制”——应对：真壁垒是基地“老带新”渠道（年 300+ 新生触达）+ 万向悬停专利（申请中）；供应链锁定只是进度优势，自评已弱化该项

· Q2“PPT 宣传 OLED，BOM 只有灯珠”——应对：这正是 H-002 双盲验证要回答的问题；20 人 A/B 14 天出结论；若失败按预案加 OLED 集成（+¥5，毛利 40% 预算内）

· Q3“学生会自费 59-79 元吗”——应对：专业工具刚需场景；61.11% 廉价灯不合格率是支付意愿锚点；H-001 虚拟支付 30 人实测回应。若失守将至 39 元档——【修正】39 元档成本测算：3D 打印外壳+无 OLED 扩展版 BOM ≈27 元，毛利 30.8%（与 H-005 的 40% 目标不矛盾：40% 对应标准版 79 元）

· 实验失败预案（来自失败标准）：H-001 失效→青春版 39 元+DIY 套件引流；H-002 失效→OLED 集成或提示音替代；H-005 失效→结构件 3D 打印降级

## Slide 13

AI 评价与团队分析（1/2）：提示词与完整评价

AI 工具：DeepSeek（Hermes Agent 桌面版）｜提问日期：2026-08-28｜前置输入：PPT V1.0 完整文件（14 页）上传

· 提示词（节选）：这是我们的创客竞赛选题汇报 PPT，请从①需求真实性②方案可行性③竞争差异化④逻辑自洽性⑤风险与漏洞⑥证据可信度六个维度评价，提出至少 3 个尖锐、具体、可操作的问题或建议。

· AI 评价（6 维摘录）：④逻辑自洽——Q&A 页“降 39 元档保毛利 30%”与 H-005“毛利 ≥40%”矛盾：39 元价位需 BOM 压到 27 元，V1.0 无利润结构支撑；③竞争差异化——矩阵未列入米家磁吸灯（29-49 元，同为磁吸形态）；①需求真实性——问卷与前测样本全部来自基地圈层，自选择偏差（无普通用户对照）……（完整评价见答辩记录附件）

· AI 还指出：20 人 A/B 无“无灯/台灯”对照组基线；OPC UA 远期收入缺乏联网样机证据；“功能覆盖得分”为自拟权重无第三方依据。

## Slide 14

AI 评价与团队分析（2/2）：逐条回应

选取 AI 评价中最具代表性的 3 条：认同 / 已执行 / 存疑

· 【认同】样本自选择偏差——AI 指出问卷对象全部为基地/圈层人群，可信但窄。实际影响：我们已在任务 1 调研设计标准化中补充分层抽样（70% 学生/20% DIY/10% 工程师，补充至 400 份，误差收敛 ±5%），并新增 2 名非技术背景实训学生访谈样本。

· 【已执行】（基于 AI 评价的具体修改，共 3 处）：①竞品矩阵新增“米家磁吸灯 29-49 元”列——此前矩阵漏掉同形态真实竞品；②修正 Q3 毛利率矛盾：39 元档追加 BOM 测算（3D 打印壳+无 OLED 扩展 =27 元/毛利 30.8%），与 H-005 的 40%（标准版 79 元）不再冲突；③增长潜力页标注 TAM 为“估算性质+来源口径”。

· 【存疑】AI 认为“A/B 缺对照组”——我们不认同：附录 B 的沉浸式体验已提供基线（无灯 50%→台灯 30%→手电 20% 失败率梯度，2026-08-20），A/B 结论与此基线互证；AI 未读取附录数据索引即下此结论，属于信息不完整归因。对应计划：V2.0 页 9 已恢复“基线对照组”引用；若评委质疑，以附录 B 记录原件回应。

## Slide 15

附录 A：质性数据《证据三角》（3 条）

规范：受访者档案[角色-细分#编号，接触时长]＋情感标记＋证据三角（录音/照片/行为笔记 ≥2 类）

编号 | 受访者档案 | 关键语录（情感标记） | 证据三角
Q-01 | [DIY 极客-电子制作#01，08.21 19:30-20:10] | “大灯照不到，小灯转天就歪，我干脆手拿着焊——焊 20 颗点手都酸了！”（重复“手拿着焊”3 次） | ☑录音 ☑行为笔记
Q-02 | [实训学生-大二电子工艺课#02，08.22 15:00-15:35] | “台灯底座占掉四分之一桌面，胳膊肘要绕开它。”（比划 90° 绕臂，叹气） | ☑录音 ☑场景照片
Q-03 | [实验室工程师-电源调试#03，08.23 14:00-14:58] | “设备自己先叫一声，而不是烧了才叫我。”（第 3 次提到“先知道”，身体前倾） | ☑录音 ☑行为笔记

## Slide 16

附录 B：数据来源与访谈记录索引（三可追溯）

来源可查 / 过程可复现 / 结果可验证

· 问卷：126 份（2026-08-14~17，问卷星，95% CI ±8.7% 阶段值）→《磁吸焊接手电调研问卷数据》

· 实景测试：60 名工人（08-18~21，基地焊台）→《工人实景测试记录表》

· 深度访谈：3 次（08-21~23，均值 38 分钟/场，已获授权）

· 沉浸式体验：20 颗 0603 失败率梯度 50%→30%→20%（基线对照）

· BOM：BOM_TYPE-A_PCB2_2026-08-23.xlsx（34 行 56 位号）+ PCBA 样机 2 台

· 完整数据包与转录稿随附提交

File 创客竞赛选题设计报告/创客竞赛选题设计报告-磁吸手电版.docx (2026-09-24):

《创客竞赛选题设计报告》

团队编号：1 班 C 组　　团队名称：仿真跑不队

竞赛团队（3 人团体）：邵子中、李昊桐、姜亚楷

选题名称：磁吸焊接辅助手电

日期：2026 年 8 月 23 日

一、选题背景与用户洞察

1.1　应用领域与选题源起

应用领域：电子手工焊接与维修场景的智能照明工具（消费级智能硬件创新）。与“AI+OPC 能力范式”的对应：AI——环境感知自适应调光（产品的大脑，解决“亮度跟着场景走”的真实痛点）；OPC——面向焊接工位数字化生态的标准数据接口（照明状态以标准协议上报实验室/产线管理系统，是“焊接生态构建”的中期扩展方向）。

选题来源：团队核心成员的真实经历与长期观察。负责人邵子中的真实经历——2025 年社团招新题“USB-PD LED 恒流驱动电路”验证板调测期间，需手工焊接 0603 阻容与 QFN 封装的 CH224K：左手镊子、右手烙铁，台灯灯臂僵直、灯光被手和烙铁遮挡，焊点全部落在阴影里，“只能反复侧身就着空调灯的光”——17 个焊点焊完，返工 3 次，脖子发酸。队友李昊桐（DIY 爱好者）常年用小夜灯凑合焊接：灯头轻、碰一下就歪，亮度只有两档；姜亚楷（实验室硬开发）则反映：工位狭小，台灯底座占去 1/4 桌面，专业机床灯“买不起也放不下”。三人合计发现：这不是个例，而是整个焊接人群的普遍困境（后续问卷 126 份验证：84.13% 用户每周焊接 ≥3 次，76.98% 强烈依赖精细补光）。

1.2　用户洞察方法与过程

洞察对象（3 位目标用户）：① 电子 DIY 极客（高频焊接，使用廉价便携灯）；② 高校课程实训学生（电子工艺实训，使用传统台灯）；③ 研发工程师（实验室原理样机调试，装备有机床灯）。

洞察方式：深度访谈 ×1 + 情境观察 ×1 + 沉浸式体验 ×1，3 名成员各独立完成 1 份洞察记录（共 3 份）。

记录人 | 洞察方式与对象 | 具体情境描述 | 关键发现（行为/直接引语/隐性需求线索） | 初步感受（对选题方向的启发）
邵子中 | 深度访谈 DIY 极客（焊接发烧友，年焊接 500+ 小时） | 在其卧室改造焊台采访：桌面仅 0.8×0.6m，放有台垫、风枪、烙铁、镊子，一盏 49 元小夜灯夹在台边。 | ① 行为：焊贴片时他把夜灯拿在手里、夹在耳机架上、垫在书堆上——试了三种“装夹”方式；② 引语：“大灯照不到，小灯转天就歪，我干脆手拿着焊”；③ 隐性需求：“如果它自己能站住，还能指哪照哪，我就再也不用手了”。 | “能固定、能瞄准”是比“亮度高”更底层的第一需求——解放双手优先于一切参数。
李昊桐 | 情境观察 观察课程实训学生（电子工艺课，焊接练习）使用传统台灯焊接 20 分钟 | 实验室 9 点实训，观察其在光缝中焊 0603 电阻：台灯灯臂只够到桌子中段，焊盘区一半被灯罩和手影遮挡。 | ① 行为：每焊 2-3 颗就停下来转电路板“换个角度找光”；② 引语：“（观察记录）他把灯撞了一下，灯头歪了，他没管，歪着灯继续焊” ；③ 隐性需求：学生在桌边贴了一张纸“灯往右一点”——需要的是“随手就调、调了不跑”。 | 传统台灯“灯臂僵、灯头飘”：照亮≠瞄准，光照方向的可控性决定了焊接可靠性。
姜亚楷 | 沉浸式体验 成员亲自扮演用户：在真实焊台分别以“无灯/台灯/手机手电筒”三种光源各焊 5 颗 0603 电阻 | 实验室白昼+靠窗、晚间接过道灯，模拟“光线不佳”的真实焊接环境；全程录像记录动作。 | ① 行为记录：无灯时焊接失败率约 50%（焊盘对不齐、锡桥），台灯下约 30%，手机手电（手夹在腋下）约 20% 但需要不断挪手；② 意外发现：焊完检查焊点时，全队都会“凑近+转板”——检查动作本身也需要照明，而现有的灯都照不到检查角度；③ 隐性需求：光斑要“跟着焊点走”，而不是“焊点找光”。 | “焊-检”两个动作都需要照明——方案的覆盖面不能只到焊接结束；台灯/手电在检查环节全部失效。

1.3　共情总结与关键洞察

共识问题 | 团队结论
核心的“未被满足的需求” | 焊点照明的“近、稳、准”三缺一：光源要贴得够近（光斑聚焦焊点）、稳（不歪不移）、准（指哪照哪）——现有工具（台灯/廉价灯/机床灯）三类都不能同时满足，市面没有“可以固定的手电”。
最频繁抱怨的痛点与原因 | ① 台灯：占空间、灯臂僵、照不进焊盘（问卷 68.25% 反馈）；② 平价灯：结构脆弱、易晃易歪、聚光性差（61.11%）；③ 专业机床灯：百元以上、体积大，学生/爱好者止步（54.76%）；④ 全人群：焊接需双手协同，100% 需要“解放双手”的固定光源。原因：传统照明设计的“底座思维”（必须放在桌面上）与焊台“垂直空间利用+装夹固定”的真实需求错位。
意料之外的发现 | ① 用户自发“手改”灯具（垫书、夹耳机架、贴纸条），说明“装夹”是强烈但未被满足的隐形需求；② “焊后检查”同样需要照明（凑近转板是普遍动作），现有灯泡全部失效于此场景；③ 不少人在“空调灯/窗户光”下凑合，不是不需要，而是“没得选”——放大市场空白。三个发现共同指向“自带装夹、光斑可控、焊检两用”的方向。

二、HMW 提问与选题定义

2.1　核心 HMW 问题（问题池与筛选）

3 名成员各提出 2 个 HMW 问题（6 个），合并相似项后形成 6 条问题池，并投票聚焦：

编号 | HMW 问题（“我们如何帮助[目标用户]在[具体情境]中[实现某目标]？”） | 提出人 | 票数
H1 | 我们如何帮助手工焊接者在狭小焊台上，不用手扶就能让光线精准对准任何一个小小的焊点？ | 邵子中 | 4
H2 | 我们如何帮助焊接者在光线激烈变化的环境里，免于反复手动调节亮度？ | 李昊桐 | 2
H3 | 我们如何帮助使用者随时确认剩余电量与亮度档位，避免焊到一半突然熄灯？ | 姜亚楷 | 2
H4 | 我们如何让光源在“焊接”与“焊点检查”两个动作之间快速切换？ | 邵子中 | 1
H5 | 我们如何帮焊接者以百元内的价格获得专业级补光体验？ | 李昊桐 | 0
H6 | 我们如何让一套照明底座适配不同焊台与夹具（台面、铁架、磁性板）？ | 姜亚楷 | 0

投票方式：3 名成员各持 3 票，共 9 票。选择理由（可行性/有效性/创新性）：H1 得票最高——可行性：强磁底座+万向悬停臂是完全可造的结构方案（钕铁硼磁铁+柔性金属臂）；有效性：直接回应观察与问卷双重验证的“解放双手+指哪照哪”第一需求；创新性：“把它当手电用，但它能自己站住”——把工业机床灯的光照能力与手电的便携性合二为一。H2（AI 感知调光，回应用户“光强随场景剧烈变化”的观察）、H3（OLED 状态可视）与 H1 组合为最终核心 HMW：

我们如何帮助手工焊接者，在狭小的焊台上不受灯具束缚——让光线随时精准对准任何一个微小焊点，并自动适配当下的光环境？

筛选维度 | H1（+H2/H3 合并）评估
可行性 | 核心机制全部可由现有成熟件实现：N42 钕铁硼磁铁、Ø6mm 不锈钢柔性臂、3W 恒流 LED 模组（PT4115）、0.91 寸 OLED（SSD1306）、STC8G1K 单片机、18650+TP4056；2-3 周可做出物理原型，无供应链门槛。
有效性 | 直击问卷 126 份中占比最高的三项痛点（68.25% 台灯挤占 / 61.11% 廉价灯不稳 / 54.76% 专业灯太贵）与 100% 的“解放双手”，并兼顾“焊后检查”这一意外发现的场景。
创新性 | 创新点在“结构×交互”组合：万向磁吸固定（工业机床灯的能力下放）+ 触控滑条无级调光 + OLED 状态可视 + 环境感知自动调光（AI 落点）；现有方案均无法同时兼顾以上四项。
与竞赛主题契合度 | AI：环境感知自适应调光是产品大脑，是整机“感知-决策-执行”的闭环，非装饰；OPC：面向焊接工位数字化生态预留标准数据接口（照明状态/使用时长/电量按标准协议上报，对接实验室与产线管理系统），呼应“AI+OPC 能力范式”中“能力范式”的行业级含义。

2.2　选题定义陈述

要素 | 内容
选题名称（≤20 字） | 磁吸焊接辅助手电（8 字）——定位：一吸即用、指哪照哪的焊接照明工具
用户与场景 | 目标用户：高校电子类专业学生（课程实训/毕业设计）、电子 DIY 极客、研发与维修工程师。具体场景：狭小焊台手工焊接与焊点检查（SMD 0603/QFN 等精密元件、高频作业 ≥3 次/周）。
核心价值主张 | 为手工焊接者提供“能自己站住的第三只手”：磁吸即贴、万向悬停、无级调光、状态可视——以约 1/10 专业灯具的价格（目标零售 ¥59-79，BOM 约 ¥45），把专业级焊接照明变成桌面一吸即用的工具。
与评审五维度的初步对应 | 创造性：万向磁吸+无级调光+OLED 状态可视的结构×交互组合，跳过“台灯/机床灯”两代思路；实用性：直接命中 126 份问卷前三痛点（68.25%/61.11%/54.76%）与 100% 解放双手刚需；安全性：低压供电（5V/3.7V）、低蓝光高显指 LED（Ra≥90）、20kHz 无频闪调光、锂电池过充过放保护；深度性：从“可调光手电”深入到恒流驱动、PWM 光调制、电量精确显示、环境感知算法的完整链路；规范性：RoHS/CE 合规与 IPC-A-610 焊接工艺标准的对接，状态数据口径预留标准化（OPC UA）对接。

三、方案构思与筛选

3.1　创意方案构想集（每人 3 个，共 9 个）

创意生成方法：应用课堂“物品遗留”演练中的“疯狂 8 分钟”发散法——每人 A4 纸对折 8 格，限时 8 分钟画满 8 格草图（只求数量、不评判）；随后每人从草图集中提炼出 3 个可展开构想，交叉补充后形成下表 9 个方案（合计 ≥9 个要求），并标注各自回应的用户需求（H1 解放双手精准照射 / H2 自动调光 / H3 状态可视 / H4 焊检两用 / H5 百元内 / H6 多场景适配）。

成员 | 方案构想（核心思路 2-3 句） | 所回应的用户需求
邵子中 | ① 强磁万向悬停臂：N42 钕铁硼磁铁（φ20×5mm）吸付金属，Ø6mm 不锈钢柔性臂 360° 悬停不回弹——物理上实现“随贴随用、指哪照哪”。② 触控滑条无级调光：电容滑条（TTP224）+ 20kHz PWM 恒流（PT4115），1%-100% 平滑无频闪。③ 高显指双色温模组：2835 阵列 Ra≥90，4000K/5000K 双色温，焊接冷光、检查暖光。 | ① H1/H6；② H1；③ H4
李昊桐 | ① 环境感知自适应调光：光敏传感器（BH1750）+ MCU 分档算法自动匹配亮度，保留手动滑条覆写，AI 落点。② 18650 + Type-C 双模供电：移档于桌面插电与电池供电（TP4056 充放电保护），强光 ≥4h、弱光 ≥16h。③ OLED 状态屏：0.91 寸 SSD1306 实时显示电量（1% 精度）、档位、色温，低功耗待机无感唤醒。 | ① H2；② H5；③ H3
姜亚楷 | ① 快拆模组头：筒光/面光/放大镜三头卡口快换，覆盖“焊-检”两个动作。② 角度刻度环：底座带 15° 刻度槽，常用角度一键复位（焊台“快照”）。③ 绝缘缓冲磁吸垫：磁铁外包硅胶+强磁套筒，防刮伤桌面/焊台，兼容铁架、磁性板与磁力底座。 | ① H4；② H1/H6；③ H6

3.2　方案筛选记录

第一步——四标准综合评分（量表：用户价值 / 技术可行性（原型层面）/ 创新性 / AI 赋能度；5 分制，3 名成员评分取平均）：

候选方案 | 用户价值 | 技术可行性 | 创新性 | AI 赋能度 | 综合（20 分制）
A：磁吸主机（万向臂+无级调光+OLED） | 5 | 5 | 4 | 3 | 17
B：环境感知自适应调光（AI 落点） | 4 | 4 | 4 | 5 | 17
C：快拆模组头（筒/面/放大镜） | 4 | 4 | 4 | 2 | 14

第二步——投票（每人 3 票，共 9 票）：

候选方案（得票 ≥2 的方案） | 票数 | 综合点评
方案 A：磁吸主机（邵子中 ① + 姜亚楷 ③ 合并） | 4 | 四标准最均衡、用户价值与可行性双高：直接回应“解放双手+指哪照哪”第一痛点；全成熟件（磁铁/柔性臂/PT4115/SSD1306），两周可出物理原型。
方案 B：环境感知自适应调光（李昊桐 ①） | 3 | “AI 赋能度”5 分——这是全案 AI 落点所在；采用“自动分档 + 手动覆写”设计避免“AI 剥夺控制权”的体验陷阱，并保留检测失败时的兜底。
方案 C：快拆模组头（姜亚楷 ①） | 2 | 差异度高（焊“验”两用），但属于“锦上添花”模块，优先级低于主机与调光；列为 MVP 之后的迭代项。
其余方案（刻度环、双色温、双模供电等共 6 个） | 0 | 并入 A/B 方案作为默认特性（双色温、18650 双模供电均为主机标配）。

筛选结论：方案 A（磁吸主机）进入 MVP 规划；方案 B（AI 自适应调光）作为 MVP 的“核心升级路径”同步验证（用光敏分档的简化实现嵌入 A），方案 C 作为迭代方向保留。

四、MVP 验证规划

4.1　核心假设清单（针对三个备选方案）

方案 | 最核心假设（不成立则方案失败） | 最小成本验证方式 | 成功/失败标准（量化）
A：磁吸主机 | “N42 磁铁吸附（拉力 ≥2.5kg）+ 万向悬停臂（角度漂移 <1°）”能让焊接者全程解放双手 | 3D 打印外壳+磁铁+柔性臂+COB 灯板+旋钮调光+OLED 组装成物理原型（BOM ≤50 元），5 名测试者在真实焊台各焊 20 颗 0603 电阻 | ≥80% 测试者报告“全程无需手扶灯具”；平均单颗焊接时间较台灯对照缩短 ≥25%；无“照不到焊点”报告
B：自适应调光 | 环境光感知自动分档比“手动三档”更省心（提高效率、减少中断） | 光敏传感器（BH1750）+ MCU 四档自动切换嵌入 A 原型；观察 5 名测试者 20 颗焊接中的手动调光次数 | ≥70% 测试者认为“自动档优于手动”；手动调光中断次数较纯手动组下降 ≥50%
C：快拆模组头 | “焊”与“检”两个动作需要不同的光斑形态（筒光/面光） | 两个简版模组头（筒光/面光）卡口手工快换，纸面原型+实物演示对比 | ≥70% 测试者认为模组头值得做；若 <70% 则降级为“放大镜附件”单需求

4.2　MVP 验证规划（优先方案 A，嵌入 B 的简化验证）

规划项 | 内容
MVP 形态 | 物理装置模型（约 15W 光功率对应 3W 电功率）：3D 打印外壳 + N42 磁铁（φ20×5mm）+ Ø6mm 不锈钢柔性臂（200mm）+ 3W COB 高显指灯板（Ra≥90、5000K）+ PT4115 恒流驱动（20kHz PWM 调光）+ 电容滑条（TTP224）+ 0.91 寸 OLED（SSD1306）+ BH1750 光敏 + STC8G1K 单片机 + 18650 电池（TP4056 充电）。不含快拆模组头（C 方案迭代验证）。
验证目标 | ① 核心假设 A：磁吸固定+万向悬停是否真正解放双手；② 次级假设 B：光敏自动四档是否优于手动调光；③ 整机可用性：交互是否直观（滑条+屏显）。
测试对象 | 与目标用户画像一致的 3 人：DIY 极客（高频焊接）、课程实训学生（电子工艺课）、研发工程师（实验室调试）；另取 2 名普通焊接初学者作为对照。
测试场景 | 真实焊台独立焊接 30 分钟：连续焊接 20 颗 0603 电阻（含 1 颗故意失误后的返工），记录照明体验、调光次数、时长与返工数；对照组用传统台灯完成同样任务。
成功标准 | ① 磁吸组 ≥80% 测试者全程无需手扶灯具；② 平均单颗焊接时间缩短 ≥25%；③ ≥70% 认为自动调光优于手动；④ 手机镜头对准灯面无频闪条纹（20kHz PWM 验证）；⑤ 吸附拉力 ≥2.5kg（弹簧秤实测）。
时间与资源计划 | 两周：第 1 周（D1-D3 结构件打印与磁吸机构装配；D4-D6 灯板打样+恒流+PWM 调光调试；D7 整机组装+参数标定）；第 2 周（D8-D10 五位测试者实测与数据统计；D11 一輪迭代（改 1-2 处）；D12-D14 复盘与报告）。资源：实验室 3D 打印机、嘉立创 PCB 打样、万用表/示波器、恒温烙铁；BOM 预算 ≤50 元/台（磁铁 ¥2、柔性臂 ¥8、灯板 ¥6、OLED ¥5、MCU+触控 ¥3、电池+充电 ¥8、外壳 ¥12、辅料 ¥6）；总预算 ≈500 元（含 2 台样机与打样费）。

五、与竞赛评审标准的对应

评审五维度权重（据课程课件）：创造性 10%、实用性 40%、安全性 20%、深度性 15%、规范性 15%。以下分析深度按权重分配，对权重最高的实用性（40%）作重点论证。

评审维度（权重） | 本选题的潜力分析
创造性（10%） | 结构×交互的组合创新：① 万向磁吸固定——把工业机床灯的“固定照明”能力以 1/10 体积下放到桌面；② 触控滑条无级调光 + OLED 状态可视——把“看亮度”变成“看状态”；③ 环境感知自动调光——从“人找光”到“光找人”。组合方式在现有照明产品中无先例。
实用性（40%，权重最高） | 【用户覆盖广度】三级用户全覆盖：高校电子类专业学生（课程实训/毕设，基数大）、电子 DIY 极客（社媒社区活跃，传播性强）、研发/维修工程师（专业买单能力强）；产品形态决定其适用于任何“金属可吸”的焊台与工作台。 【需求刚需强度】问卷 126 份实证：84.13% 每周焊接 ≥3 次（高频刚需）、76.98% 强依赖精细补光、71.43% 工位空间受限、100% 解放双手；三大痛点占比 68.25%/61.11%/54.76% 均超半数；沉浸式体验中“无灯失败率 50%→台灯 30%→手电 20%”的实测梯度，直接说明照明方案对成果质量的因果影响。 【价格可达性】BOM ≈¥45、零售 ¥59-79，显著低于工业级灯具（数百元）；“精密的活儿 + 亲民的价格”是消费级普惠创新，转化路径清晰。
安全性（20%） | 四重安全保障：① 供电安全——3.7V/5V 低压锂电（TP4056 带过充过放与短路保护，18650 不可拆卸防爆设计）；② 光安全——低蓝光高显指 LED（Ra≥90、色温 4000K/5000K），20kHz PWM 调光无可视频闪（护眼认证路径）；③ 热安全——3W 灯板铝基板+导热胶，连续工作表面温度 ≤60℃；④ 使用安全——磁铁外包硅胶防夹手/防刮，边缘倒角。
深度性（15%） | 链路完整覆盖“传感（光敏/电量/触控）—控制（STC8G1K 调光与分档算法）—驱动（PT4115 恒流 20kHz PWM）—显示（OLED 状态可视）—供电（锂电双模）”，并可扩展至“感知-决策-执行”的自适应闭环；不是简单“换个壳的台灯”，而是从照明单品走向“智能焊接工位终端”的硬件+算法系统。
规范性（15%） | 硬件合规路径：RoHS/CE/FCC/3C 认证规划，BOM 表、原理图、结构图、测试报告等文档齐套（对接 IPC-A-610 焊接质量标准的应用场景）；数据规范性：状态数据（电量/亮度/时长）口径预留标准化接口（OPC UA 语义对齐），为“焊接工位数字化生态”（高校实验室设备管理、产线焊台状态监测）预留接入能力——呼应竞赛“AI+OPC 能力范式”中的“能力范式”层面。

六、设计思维应用反思

① 最困难的环节：定义阶段——把“一个照明小工具”与“AI+OPC 能力范式”竞赛主题对齐。困难来自三方面：第一，共情期信息量不小（3 份记录 + 126 份问卷 + 60 名工人实测数据），容易陷入“什么功能都想要”（第 2 轮讨论曾同时惦记 8 个功能点）；第二，队内三人都是 D 型（“大象”组合），人人有主张，讨论一度变成“谁嗓门大”；第三，也是最难的一点：评审标准的“AI 赋能度”与我们产品真实的用户需求之间存在张力——用户只想要“照得清楚、不占手”，并不关心 AI。我们最终判定的准绳是：AI 不是装饰性点缀，而是“感知-决策-执行”闭环中真实存在的一环（环境光感知→自动分档），并给用户留了手动覆写的控制权；OPC 则落在工位数字化生态的中期接口上。

② 工具发挥作用最大的环节：HMW 格式与四标准评分表（配合“先听后决”议事规则）。具体事例：在“要不要加自动调光”的争论最激烈时（三人两票反对——觉得会增加调试成本），我们停下来把“我们想做一盏能调光的手电”改写成标准格式“我们如何帮助手工焊接者在光线激烈变化的环境里，免于反复手动调节亮度？”——改写之后争议立刻消失：这是真实观察到的场景（从窗口午后 2 点 35 分到傍晚阳光变化，焊盘反光肉眼可感），问题成立；随后用四标准评分表打分，B 方案的“AI 赋能度”5 分成为它进入 MVP 升级路径的决定性依据——评分表让“装饰性 AI”与“必要 AI”的争论变成了可判定的分数。

③ 与课堂“物品遗留问题”演练的不同与调整：课堂演练场景中“用户即同学”，我们也能沉浸式体验；本次焊接场景我们三人恰好都是使用者（半专业用户），有天然优势（沉浸式体验做得真——自己焊 20 颗 0603，失败率从 50%→20% 的梯度是实测数据），但也有陷阱：我们的“技术组视角”可能高估了普通学生的动手熟练度、低估了价格敏感度。四点调适策略：① 洞察方式三线并用（访谈/观察/沉浸式体验各 1 份），且刻意找一个“非技术”的课程实训学生作为观察对象；② 用 126 份问卷扩大证据面，把“个别感受”升格为“群体分布”；③ 把课堂开放式问题收窄为 5W1H 结构化访谈，换取“大灯照不到，小灯转天就歪，我干脆手拿着焊”这类引用级证据；④ 全部结论建立“证据链”（每条痛点标注问卷占比或观察记录时间点），防止“我们觉得”冒充“用户需要”。

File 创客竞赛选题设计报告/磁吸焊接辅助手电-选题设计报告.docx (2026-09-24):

《创客竞赛选题设计报告》

团队编号：1 班 C 组　　团队名称：仿真跑不队

竞赛团队（3 人团体）：邵子中（U202511546，负责人）、李昊桐、姜亚楷

选题名称：磁吸焊接辅助手电

竞赛主题：AI+OPC 能力范式

日期：2026 年 8 月 23 日

一、选题背景与用户洞察

1.1　应用领域与选题源起

应用领域：电子手工焊接与维修场景的智能照明工具（消费级智能硬件）。对应竞赛主题：AI 落在环境感知自适应调光上，这是产品的一个真实环节，装上去能干活，拆掉就明显缺一块；OPC 落在焊接工位数字化生态的标准数据接口上，属于中期扩展方向（照明状态、使用时长、电量按标准协议上报实验室或产线管理系统）。

选题来源是几位成员自己的事。负责人邵子中在 2026 年社团招新题“USB-PD LED 恒流驱动电路”验证板调测时，要手工焊 0603 阻容和 QFN 封装的 CH224K。左手镊子右手烙铁，台灯灯臂僵直，光被手和烙铁挡死，焊点全在阴影里。17 个焊点焊完返工 3 次，脖子酸了一晚上，最后靠侧身就着过道的灯光补完。李昊桐是 DIY 玩家，一直在工位上用 49 元的小夜灯凑合，灯头轻，碰一下歪一下，亮度只有两档。姜亚楷在实验室做调试，桌面本来就不大，台灯底座占掉四分之一，机床灯买不起也放不下。三个人一对，发现这不是运气问题，是所有人都有的处境。后来的问卷（126 份）验证了这一点：84.13% 的人每周焊接至少 3 次，76.98% 的人强烈依赖精细补光，100% 的焊接都需要双手操作。

1.2　用户洞察方法与过程

洞察对象（3 位目标用户）：① 电子 DIY 极客（高频焊接，用廉价便携灯）；② 高校课程实训学生（电子工艺实训，用传统台灯）；③ 研发工程师（实验室原理样机调试，装机床灯）。

洞察方式：深度访谈 1 份 + 情境观察 1 份 + 沉浸式体验 1 份，三名成员各独立完成 1 份记录。

记录人 | 洞察方式与对象 | 具体情境描述 | 关键发现（行为/直接引语/隐性需求线索） | 初步感受（对选题方向的启发）
邵子中 | 深度访谈 DIY 极客（焊接发烧友，年均焊接 500+ 小时） | 采访在其卧室焊台进行，桌面 0.8×0.6m，台垫、风枪、烙铁、镊子之外，一盏 49 元小夜灯夹在台边。 | ① 行为：焊贴片时他先后把灯拿到手里、夹在耳机架上、垫在书堆上，试了三种“装夹”方式；② 引语：“大灯照不到，小灯转天就歪，我干脆手拿着焊。”；③ 隐性需求：“如果它能自己站住，还能指哪照哪，我就不用手了。” | 能固定、能瞄准比亮度更重要。解放双手是第一需求，不是参数。
李昊桐 | 情境观察 课程实训学生在电子工艺课上用台灯焊接 20 分钟 | 上午 9 点实验室，观察其在光缝里焊 0603 电阻；台灯灯臂只够到桌子中段，焊盘区一半被灯罩和手影盖住。 | ① 行为：每焊 2-3 颗停下转一次板“找光”；② 观察记录（原话记录）：“他撞了灯一下，灯头歪了，他没管，歪着头继续焊。”；③ 隐性需求：桌边贴了一张纸条“灯往右一点”。 | 传统台灯灯臂僵、灯头飘。照亮不等于瞄准，光线方向的可控性才是关键。
姜亚楷 | 沉浸式体验 成员亲身上机：真实焊台分别以无灯/台灯/手机手电筒三种光源各焊 5 颗 0603 电阻 | 分白天靠窗和晚间过道灯两种环境，模拟“光线不佳”的真实条件，全程录像。 | ① 行为记录：无灯时对不齐焊盘、出锡桥，约失败 5 颗中的 2-3 颗；台灯约 1-2 颗；手机手电（手夹在腋下）约 1 颗但要一直挪手；② 意外发现：焊完检查时全队都会“凑近+转板”，检查这一步也需要光，台灯和手电都照不到这个角度；③ 隐性需求：光斑要跟着焊点走，而不是焊点找光。 | 焊和检两个动作都要光。方案的覆盖面不能到焊接结束为止。

1.3　共情总结与关键洞察

共识问题 | 团队结论
核心的“未被满足的需求” | 焊点照明的“近、稳、准”三缺一：光要贴得近（光斑聚焦焊点）、稳（不歪不移）、准（指哪照哪）。台灯、廉价灯、机床灯三家都不能同时做到。市面上没有“能自己站住的手电”。
最频繁抱怨的痛点与原因 | ① 台灯：占桌面、灯臂僵、照不进焊盘（问卷 68.25%）；② 廉价灯：结构软、易晃易歪、聚光差（61.11%）；③ 机床灯：百元以上、体积大，学生和爱好者止步（54.76%）；④ 共性：焊接必须双手，100% 需要不用手扶的固定光源。原因一句话：传统灯具都是“底座思维”，放在桌面上；焊台的真实需求是垂直空间里的装夹固定。
意料之外的发现 | ① 用户会“手改”灯具：垫书、夹耳机架、贴纸条，装夹是一个强烈但没人满足的隐性需求；② 焊完检查焊点要凑近转板，这一步同样需要光，现有产品全部够不着；③ 不少人在空调灯、窗户光下凑合，不是不需要，是没得选。三点都指向“自带装夹、光斑可控、焊检两用”的方向。

二、HMW 提问与选题定义

2.1　核心 HMW 问题（问题池与筛选）

3 名成员各提出 2 个 HMW 问题（6 个），合并相似项后形成 6 条问题池，并投票聚焦：

编号 | HMW 问题（“我们如何帮助[目标用户]在[具体情境]中[实现某目标]？”） | 提出人 | 票数
H1 | 我们如何帮助手工焊接者在狭小焊台上，不用手扶就能让光线精准对准任何一个小小的焊点？ | 邵子中 | 4
H2 | 我们如何帮助焊接者在光线激烈变化的环境里，免于反复手动调节亮度？ | 李昊桐 | 2
H3 | 我们如何帮助使用者随时确认剩余电量与亮度档位，避免焊到一半突然熄灯？ | 姜亚楷 | 2
H4 | 我们如何让光源在“焊接”与“焊点检查”两个动作之间快速切换？ | 邵子中 | 1
H5 | 我们如何帮焊接者以百元内的价格获得专业级补光体验？ | 李昊桐 | 0
H6 | 我们如何让一套照明底座适配不同焊台与夹具（台面、铁架、磁性板）？ | 姜亚楷 | 0

投票方式：3 名成员各持 3 票，共 9 票。选择理由（可行性/有效性/创新性）：H1 得票最高。可行性：强磁底座加万向悬停臂是现成结构，没有断供风险；有效性：直接命中共情阶段观察与问卷双重验证的“解放双手、指哪照哪”；创新性：把机床灯的光照能力和手电的便携性合到一起，市面上已有的产品都只占一头。H2（AI 感知调光）、H3（状态可视化）与 H1 合并成最终核心 HMW：

我们如何帮助手工焊接者，在狭小的焊台上不受灯具束缚——让光线随时精准对准任何一个微小焊点，并自动适配当下的光环境？

筛选维度 | H1（+H2/H3 合并）评估
可行性 | 核心机制全是成熟件：N42 钕铁硼磁铁、Ø6mm 不锈钢柔性臂、3W 恒流 LED 模组、0.91 寸 OLED、单片机和 18650 供电。2-3 周能出物理原型，没有供应链门槛。
有效性 | 覆盖问卷 126 份中占比最高的三项痛点（68.25% / 61.11% / 54.76%）和 100% 的解放双手需求，另外补上了“焊后检查”这个没人注意的场景。
创新性 | 结构加交互的联合创新：万向磁吸固定、触控无级调光、OLED 状态可视、环境感知自动调光。现有产品最多占到其中一两个。
与竞赛主题契合度 | AI 落在环境感知自适应调光（感知、决策、执行闭环），不是贴上去的标签；OPC 落在工位数字化生态的标准接口上（中期扩展），两个都有真实落点。

2.2　选题定义陈述

要素 | 内容
选题名称（≤20 字） | 磁吸焊接辅助手电（8 字）。定位：一吸即用、指哪照哪的焊接照明工具。
用户与场景 | 目标用户：高校电子类专业学生（课程实训/毕业设计）、电子 DIY 极客、研发与维修工程师。场景：狭小焊台手工焊接与焊点检查（0603/QFN 等精密元件，每周 3 次以上）。
核心价值主张 | 给焊接者一双腾出来的手：磁铁往焊台上一贴，柔臂弯到哪就照到哪，亮度滑着调，屏上看得见电量和档位。目标零售 59-79 元，整机 BOM 控制在 50 元以内，同档次的专业灯要几百块。
与评审五维度的初步对应 | 创造性：万向磁吸加无级调光加状态可视的组合，跳过了台灯和机床灯两代思路；实用性：命中 126 份问卷前三项痛点；安全性：低压供电、低蓝光高显指灯珠、20kHz 无频闪调光、锂电池过充过放保护；深度性：从“能调光的手电”到恒流驱动、PWM 调制、电量管理、感知算法的完整链路；规范性：RoHS/CE 认证与 IPC-A-610 标准对接，状态数据口径预留标准化接口。

三、方案构思与筛选

3.1　创意方案构想集（每人 3 个，共 9 个）

创意生成方法：用课堂“物品遗留”演练里的“疯狂 8 分钟”发散法，每人一张 A4 纸对折 8 格，限时 8 分钟画满，只求数量不评判；之后每人从草图中提炼 3 个可展开的构想，三人交叉补充，得到下表 9 个方案（符合不少于 9 个的要求），每个方案标注所回应的用户需求（H1 解放双手精准照射 / H2 自动调光 / H3 状态可视 / H4 焊检两用 / H5 百元内 / H6 多场景适配）。

成员 | 方案构想（核心思路 2-3 句） | 所回应的用户需求
邵子中 | ① 强磁万向悬停臂：N42 钕铁硼磁铁（φ20×5mm）吸附金属台面，Ø6mm 不锈钢柔性臂 360° 悬停不回弹。② 触控滑条无级调光：电容滑条加 20kHz PWM 恒流，1% 到 100% 平滑无频闪。③ 高显指双色温灯板：2835 阵列 Ra≥90，4000K 焊接、5000K 检查。 | ① H1/H6；② H1；③ H4
李昊桐 | ① 环境感知自动调光：光敏传感器加 MCU 分档算法自动跟亮度，保留手动覆写，AI 落点。② 18650 + TYPE-C 双模供电：桌面插电与电池两用，强光 4 小时以上、弱光 16 小时以上。③ OLED 状态屏：0.91 寸 SSD1306 显示电量（1% 精度）、档位、色温，低功耗待机。 | ① H2；② H5；③ H3
姜亚楷 | ① 快拆模组头：筒光、面光、放大镜三个头卡口快换，焊和检一步切换。② 角度刻度环：底座 15° 刻度槽，常用角度一键复位。③ 绝缘缓冲磁吸垫：硅胶包磁铁加套筒，防刮桌面，兼容铁架、磁性板、磁力座。 | ① H4；② H1/H6；③ H6

3.2　方案筛选记录

第一步——四标准综合评分（用户价值 / 技术可行性（原型层面）/ 创新性 / AI 赋能度，5 分制，三人评分取平均）：

候选方案 | 用户价值 | 技术可行性 | 创新性 | AI 赋能度 | 综合（20 分制）
A：磁吸主机（万向臂+无级调光+状态显示） | 5 | 5 | 4 | 3 | 17
B：环境感知自适应调光（AI 落点） | 4 | 4 | 4 | 5 | 17
C：快拆模组头（筒/面/放大镜） | 4 | 4 | 4 | 2 | 14

第二步——投票（每人 3 票，共 9 票）：

候选方案（得票 ≥2 的方案） | 票数 | 综合点评
方案 A：磁吸主机（邵子中 ① + 姜亚楷 ③ 合并） | 4 | 用户价值和可行性双高。全成熟件，两周出原型没有问题。
方案 B：环境感知自适应调光（李昊桐 ①） | 3 | 靠“AI 赋能度”5 分胜出，这是全案 AI 的落点。采用自动分档加手动覆写的设计，避免机器替人做主；出问题时手动兜底。
方案 C：快拆模组头（姜亚楷 ①） | 2 | 差异化最大，焊检两用，但属于加分项，排在主机与调光之后，列为 MVP 后的迭代。
其余方案（刻度环、双色温、双模供电等共 6 个） | 0 | 并入 A 方案作为默认特性（双色温和双模供电都是主机标配）。

筛选结论：方案 A 进 MVP，方案 B 作为 MVP 的核心升级路径同步验证（光敏分档的简化实现嵌入 A），方案 C 留作迭代方向。

四、MVP 验证规划

4.1　核心假设清单（针对三个备选方案）

方案 | 最核心假设（不成立则方案失败） | 最小成本验证方式 | 成功/失败标准（量化）
A：磁吸主机 | “N42 磁铁（拉力 ≥2.5kg）+ 万向悬停臂（角度漂移 <1°）”能让焊接者全程解放双手 | 3D 打印外壳加磁铁、柔性臂、灯板、旋钮调光、OLED 组出物理原型（整机 BOM ≤50 元），5 名测试者在真实焊台各焊 20 颗 0603 电阻 | ≥80% 测试者报告全程无需手扶灯具；平均单颗焊接时间较台灯组缩短 ≥25%；无“照不到焊点”报告
B：自适应调光 | 环境光感知自动分档比“手动三档”更省心（行为指标：减少调光中断） | 外接 BH1750 光敏模块（实验板验证，量产版集成）嵌入 A 原型，观察 5 名测试者 20 颗焊点中的手动调光次数 | ≥70% 测试者认为自动档优于手动；调光中断次数比纯手动组下降 ≥50%
C：快拆模组头 | “焊”和“检”两个动作需要不同光斑（筒光/面光） | 两个简版模组头卡口手工快换，实物演示对比 | ≥70% 测试者认为值得做；低于该值降级为放大镜附件

4.2　MVP 验证规划（优先方案 A，嵌入 B 的简化验证）

规划项 | 内容
MVP 形态 | 物理装置 + 已完成的 PCBA 样机（BOM_TYPE-A_PCB2_2026-08-23，共 34 行 56 个位号）：主控 CW32L010F8P6（TSSOP-20，32 位 MCU）；照明链路为矽力杰 SY7200AABC 升压恒流驱动（SOT-23-6）+ 5.6uH 升压电感（YHNR3015-5R6M）驱动 10 颗 OSRAM GW JTLPS1 白光灯珠；电源管理为英集芯 IP5306（18650 充放电一体，TYPE-C 6P 输入，带 4 路电量 LED），外配 ME6211C33M5G-N（3.3V LDO）与 DW01+8205A 锂电池保护，SS54 肖特基 ×2；交互为 5× TS24CA 轻触开关与 0.91 寸 OLED（SSD1306，经 H1 排针外接，后续版本集成）；板载 6 颗红色 LED（4 颗电量 + 2 颗充电指示）。
验证目标 | ① 核心假设 A：磁吸固定加万向悬停是否真正解放双手；② 次级假设 B：光敏自动四档是否优于手动调光；③ 整机可用性：按键与屏显的交互是否直观。
测试对象 | 与目标用户画像一致的 3 人：DIY 极客（高频焊接）、课程实训学生（电子工艺课）、研发工程师（实验室调试）；另取 2 名普通焊接初学者对照。
测试场景 | 真实焊台独立焊接 30 分钟，连续焊 20 颗 0603 电阻（含 1 颗故意失误后的返工），记录照明体验、调光次数、时长与返工数。对照组用传统台灯完成同样的 20 颗。
成功标准 | ① 磁吸组 ≥80% 测试者全程无需手扶灯具；② 平均单颗焊接时间缩短 ≥25%；③ ≥70% 认为自动调光优于手动；④ 手机镜头对准灯面无频闪条纹（20kHz PWM 验证）；⑤ 吸附拉力 ≥2.5kg（弹簧秤实测）。
时间与资源计划 | 两周：第 1 周（D1-D3 结构件打印与磁吸机构装配；D4-D6 灯板调试与 PWM 调光标定；D7 整机组装与参数标定）；第 2 周（D8-D10 五位测试者实测与数据统计；D11 一轮迭代改 1-2 处；D12-D14 复盘与报告编写）。资源：实验室 3D 打印机、现有 PCBA 样机、万用表/示波器、恒温烙铁；PCBA 器件按 LCSC 批量价估算约 25-35 元，机构件（N42 磁铁 2 元、柔性臂 8 元、外壳 12 元），整机 BOM ≤50 元；两轮打样加辅料总预算约 500 元。

五、与竞赛评审标准的对应

评审五维度权重（据课程课件）：创造性 10%、实用性 40%、安全性 20%、深度性 15%、规范性 15%。分析深度按权重分配，实用性（40%）重点论证。

评审维度（权重） | 本选题的潜力分析
创造性（10%） | 结构加交互的组合创新：万向磁吸固定把机床灯的固定照明能力缩小到掌心；触控滑条加 OLED 状态屏把“看亮度”变成“看状态”；环境感知调光让光跟着人走。市面现有产品没有这样的组合。
实用性（40%，权重最高） | 【用户覆盖广度】三级用户全覆盖：高校电子类专业学生（实训与毕设，基数最大）、DIY 极客（社区活跃，传播快）、研发维修工程师（专业买单意愿强）。产品形态决定了只要焊台是铁的就能用。 【需求刚需强度】126 份问卷：84.13% 每周焊 3 次以上，76.98% 依赖精细补光，71.43% 工位空间受限，100% 需要解放双手。三类现有灯具的痛点占比均过半（68.25% / 61.11% / 54.76%）。沉浸式体验里无灯失败率 50%、台灯 30%、手机手电 20% 的梯度，说明照明方案直接决定焊接质量，不是“有没有光”的小事。 【价格可达性】整机 BOM ≤50 元（PCBA 25-35 元加机构件），目标零售 59-79 元，对比几百元的专业灯有明确价格优势，学生买得起。
安全性（20%） | 供电安全：18650 锂电池配 DW01+8205A 过充过放与短路保护，TYPE-C 可拆装电池仓；光安全：低蓝光高显指灯珠（Ra≥90），20kHz PWM 无可视频闪；热安全：灯板铝基板加导热胶，连续工作表面温度 ≤60℃；使用安全：磁铁硅胶包覆防夹手、防刮花，边缘倒角。
深度性（15%） | 从“能调光的手电”到完整系统：传感（光敏、电量、按键）、控制（CW32L010 调光与分档算法）、驱动（SY7200A 升压恒流 20kHz PWM）、电源（IP5306 充放电管理）、显示（OLED 与 LED 指示），再到感知闭环。照明单品之外，能向“智能焊接工位终端”方向走一步。
规范性（15%） | RoHS/CE/FCC/3C 认证路径已规划；BOM 表、原理图、测试报告齐套，对接 IPC-A-610 焊接质量标准；状态数据（电量、亮度、使用时长）口径预留标准化接口（OPC UA 语义对齐），给实验室设备管理和产线焊台监测留了接入能力，对应“能力范式”的行业层面含义。

六、设计思维应用反思

① 最难的环节是定义阶段，难在这个小工具怎么和“AI+OPC 能力范式”对上。卡住的时间主要有三点：第一，共情期信息多，3 份记录加 126 份问卷，讨论到第二轮我们同时惦记了 8 个功能点；第二，三个人都是 D 型（大象组合），谁也说服不了谁，一度变成谁嗓门大听谁的；第三是评审的 AI 赋能度和用户真实需求之间有张力，用户只说“照得清楚、不占手”，根本不在乎 AI。我们最后定的标准很简单：AI 必须是一个真实存在的环节，装上去干活，拆掉明显缺一块。环境光感知到自动调光是这么定下来的，同时保留手动覆写，免得机器替人做主。OPC 没有硬塞，放在工位数字化生态的中期接口上。

② 工具作用最大的是 HMW 格式，配上四标准评分表。吵得最凶的是要不要做自动调光，三个人里两个反对，理由是怕多调试成本。我们停下来把“想做一盏能调光的手电”改写成“我们如何帮助手工焊接者在光线激烈变化的环境里，免于反复手动调节亮度”。写完争议就没了：午后 2 点半到傍晚，窗边焊盘的反光变化肉眼可见，问题成立。之后四标准评分，B 方案 AI 赋能度 5 分，自动调光进 MVP 升级路径就有了依据。实践证明，打分比吵架高效。

③ 课堂“物品遗留”演练，用户就是同学，我们自己也能沉浸式体验。焊接这个场景我们仨正好都是使用者，算半专业用户，沉浸式体验做得比较真，20 颗 0603 的失败率梯度（无灯 50%、台灯 30%、手电 20%）是实打实测出来的。但陷阱也有：容易按技术组的标准高估别人，也容易低估价格敏感度。我们做了四点调整：一是洞察三线并用，访谈、观察、沉浸式各一份，观察对象刻意找了一个非技术背景的课程实训学生；二是用 126 份问卷把个别感受铺开成群体分布；三是把课堂上的开放式问题收窄成 5W1H 的结构化问题，换回来“大灯照不到，小灯转天就歪，我干脆手拿着焊”这种能直接引用的原话；四是每条结论都标了出处，问卷占比或观察时间点，避免“我们觉得”冒充“用户需要”。

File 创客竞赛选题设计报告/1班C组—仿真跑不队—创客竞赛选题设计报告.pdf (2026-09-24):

# 《创客竞赛选题设计报告》

## 第十届“优利德电子杯”创客竞赛 · 设计思维应用阶段（C3s3t1）

## 团队编号：1 班 C 组 团队名称：仿真跑不队

## 竞赛团队（3 人团体）：邵子中（U202511546，负责人）、李昊桐、姜亚楷

### （三人均为 D 型行为风格——“大象”组合，分工：邵子中统筹硬件系统与对外答辩；李昊桐负责电源、LED 驱 动与软件算法；姜亚楷负责结构、装配与测试验证）

## 选题名称：磁吸焊接辅助手电

## 竞赛主题：AI+OPC 能力范式

## 日期：2026 年 8 月 ＿ 日

## 一、选题背景与用户洞察

## 1.1 应用领域与选题源起

### 应用领域：电子手工焊接与维修场景的智能照明工具（消费级智能硬件）。对应竞赛主题：AI 落在环境感知 自适应调光上，这是产品的一个真实环节，装上去能干活，拆掉就明显缺一块；OPC 落在焊接工位数字化生 态的标准数据接口上，属于中期扩展方向（照明状态、使用时长、电量按标准协议上报实验室或产线管理系

统）。

选题来源是几位成员自己的事。负责人邵子中在 2026 年社团招新题“USB-PD LED 恒流驱动电路”验证板 调测时，要手工焊 0603 阻容和 QFN 封装的 CH224K。左手镊子右手烙铁，台灯灯臂僵直，光被手和烙铁 挡死，焊点全在阴影里。17 个焊点焊完返工 3 次，脖子酸了一晚上，最后靠侧身就着过道的灯光补完。李 昊桐是 DIY 玩家，一直在工位上用 49 元的小夜灯凑合，灯头轻，碰一下歪一下，亮度只有两档。姜亚楷在 实验室做调试，桌面本来就不大，台灯底座占掉四分之一，机床灯买不起也放不下。三个人一对，发现这不 是运气问题，是所有人都有的处境。后来的问卷（126 份）验证了这一点：84.13% 的人每周焊接至少 3 次，76.98% 的人强烈依赖精细补光，100% 的焊接都需要双手操作。

## 1.2 用户洞察方法与过程

### 洞察对象（3 位目标用户）：① 电子 DIY 极客（高频焊接，用廉价便携灯）；② 高校课程实训学生（电子 工艺实训，用传统台灯）；③ 研发工程师（实验室原理样机调试，装机床灯）。

### 洞察方式：深度访谈 1 份 + 情境观察 1 份 + 沉浸式体验 1 份，三名成员各独立完成 1 份记录。

记录人 | 洞察方式与对象 | 具体情境描述 | 关键发现（行为/直接引语/隐性 需求线索） | 初步感受（对选题方 向的启发）
邵子中 | 深度访谈 DIY 极客（焊接发 烧友，年均焊接 500+ 小时） | 采访在其卧室焊台进 行，桌面 0.8×0.6m，台垫、 风枪、烙铁、镊子之 外，一盏 49 元小夜 灯夹在台边。 | ① 行为：焊贴片时他先后把灯拿 到手里、夹在耳机架上、垫在书 堆上，试了三种“装夹”方式； ② 引语：“大灯照不到，小灯转 天就歪，我干脆手拿着焊。”； ③ 隐性需求：“如果它能自己站 住，还能指哪照哪，我就不用手 了。” | 能固定、能瞄准比亮 度更重要。解放双手 是第一需求，不是参 数。
李昊桐 | 情境观察 课程实训学生在电 子工艺课上用台灯 焊接 20 分钟 | 上午 9 点实验室，观 察其在光缝里焊 0603 电阻；台灯灯 臂只够到桌子中段， 焊盘区一半被灯罩和 手影盖住。 | ① 行为：每焊 2-3 颗停下转一次 板“找光”；② 观察记录（原话 记录）：“他撞了灯一下，灯头 歪了，他没管，歪着头继续 焊。”；③ 隐性需求：桌边贴了 一张纸条“灯往右一点”。 | 传统台灯灯臂僵、灯 头飘。照亮不等于瞄 准，光线方向的可控 性才是关键。
姜亚楷 | 沉浸式体验 成员亲身上机：真 实焊台分别以无灯 /台灯/手机手电筒 三种光源各焊 5 颗 0603 电阻 | 分白天靠窗和晚间过 道灯两种环境，模拟 “光线不佳”的真实 条件，全程录像。 | ① 行为记录：无灯时对不齐焊 盘、出锡桥，约失败 5 颗中的 2- 3 颗；台灯约 1-2 颗；手机手电 （手夹在腋下）约 1 颗但要一直 挪手；② 意外发现：焊完检查时 全队都会“凑近+转板”，检查 这一步也需要光，台灯和手电都 照不到这个角度；③ 隐性需求： 光斑要跟着焊点走，而不是焊点 找光。 | 焊和检两个动作都要 光。方案的覆盖面不 能到焊接结束为止。

## 1.3 共情总结与关键洞察

共识问题 | 团队结论
核心的“未被满足的需 求” | 焊点照明的“近、稳、准”三缺一：光要贴得近（光斑聚焦焊点）、稳（不歪不 移）、准（指哪照哪）。台灯、廉价灯、机床灯三家都不能同时做到。市面上没 有“能自己站住的手电”。
最频繁抱怨的痛点与原 因 | ① 台灯：占桌面、灯臂僵、照不进焊盘（问卷 68.25%）；② 廉价灯：结构软、 易晃易歪、聚光差（61.11%）；③ 机床灯：百元以上、体积大，学生和爱好者 止步（54.76%）；④ 共性：焊接必须双手，100% 需要不用手扶的固定光源。 原因一句话：传统灯具都是“底座思维”，放在桌面上；焊台的真实需求是垂直

| 空间里的装夹固定。
意料之外的发现 | ① 用户会“手改”灯具：垫书、夹耳机架、贴纸条，装夹是一个强烈但没人满足 的隐性需求；② 焊完检查焊点要凑近转板，这一步同样需要光，现有产品全部够 不着；③ 不少人在空调灯、窗户光下凑合，不是不需要，是没得选。三点都指向

“自带装夹、光斑可控、焊检两用”的方向。 二、HMW 提问与选题定义

## 2.1 核心 HMW 问题（问题池与筛选）

### 3 名成员各提出 2 个 HMW 问题（6 个），合并相似项后形成 6 条问题池，并投票聚焦：

编号 | HMW 问题（“我们如何帮助[目标用户]在[具体情境]中[实 现某目标]？”） | 提出人 | 票数
H1 | 我们如何帮助手工焊接者在狭小焊台上，不用手扶就能让光 线精准对准任何一个小小的焊点？ | 邵子中 | 4
H2 | 我们如何帮助焊接者在光线激烈变化的环境里，免于反复手 动调节亮度？ | 李昊桐 | 2
H3 | 我们如何帮助使用者随时确认剩余电量与亮度档位，避免焊 到一半突然熄灯？ | 姜亚楷 | 2
H4 | 我们如何让光源在“焊接”与“焊点检查”两个动作之间快 速切换？ | 邵子中 | 1
H5 | 我们如何帮焊接者以百元内的价格获得专业级补光体验？ | 李昊桐 | 0
H6 | 我们如何让一套照明底座适配不同焊台与夹具（台面、铁 架、磁性板）？ | 姜亚楷 | 0

### 投票方式：3 名成员各持 3 票，共 9 票。选择理由（可行性/有效性/创新性）：H1 得票最高。可行性：强磁底座 加万向悬停臂是现成结构，没有断供风险；有效性：直接命中共情阶段观察与问卷双重验证的“解放双手、指哪 照哪”；创新性：把机床灯的光照能力和手电的便携性合到一起，市面上已有的产品都只占一头。H2（AI 感知调 光）、H3（状态可视化）与 H1 合并成最终核心 HMW：

## 我们如何帮助手工焊接者，在狭小的焊台上不受灯具束缚——让光线随时精准对准任何一个微小焊 点，并自动适配当下的光环境？

筛选维度 | H1（+H2/H3 合并）评估
可行性 | 核心机制全是成熟件：N42 钕铁硼磁铁、Ø6mm 不锈钢柔性臂、3W 恒流 LED 模组、 0.91 寸 OLED、单片机和 18650 供电。2-3 周能出物理原型，没有供应链门槛。
有效性 | 覆盖问卷 126 份中占比最高的三项痛点（68.25% / 61.11% / 54.76%）和 100% 的解 放双手需求，另外补上了“焊后检查”这个没人注意的场景。
创新性 | 结构加交互的联合创新：万向磁吸固定、触控无级调光、OLED 状态可视、环境感知自

| 动调光。现有产品最多占到其中一两个。
与竞赛主题契 合度 | AI 落在环境感知自适应调光（感知、决策、执行闭环），不是贴上去的标签；OPC 落在 工位数字化生态的标准接口上（中期扩展），两个都有真实落点。

## 2.2 选题定义陈述

要素 | 内容
选题名称（≤20 字） | 磁吸焊接辅助手电（8 字）。定位：一吸即用、指哪照哪的焊接照明工具。
用户与场景 | 目标用户：高校电子类专业学生（课程实训/毕业设计）、电子 DIY 极客、研发与 维修工程师。场景：狭小焊台手工焊接与焊点检查（0603/QFN 等精密元件，每周 3 次以上）。
核心价值主张 | 给焊接者一双腾出来的手：磁铁往焊台上一贴，柔臂弯到哪就照到哪，亮度滑着 调，屏上看得见电量和档位。目标零售 59-79 元，整机 BOM 控制在 50 元以内， 同档次的专业灯要几百块。
与评审五维度的初步 对应 | 创造性：万向磁吸加无级调光加状态可视的组合，跳过了台灯和机床灯两代思路； 实用性：命中 126 份问卷前三项痛点；安全性：低压供电、低蓝光高显指灯珠、 20kHz 无频闪调光、锂电池过充过放保护；深度性：从“能调光的手电”到恒流 驱动、PWM 调制、电量管理、感知算法的完整链路；规范性：RoHS/CE 认证与

IPC-A-610 标准对接，状态数据口径预留标准化接口。 三、方案构思与筛选

## 3.1 创意方案构想集（每人 3 个，共 9 个）

### 创意生成方法：用课堂“物品遗留”演练里的“疯狂 8 分钟”发散法，每人一张 A4 纸对折 8 格，限时 8 分钟画 满，只求数量不评判；之后每人从草图中提炼 3 个可展开的构想，三人交叉补充，得到下表 9 个方案（符合不少 于 9 个的要求），每个方案标注所回应的用户需求（H1 解放双手精准照射 / H2 自动调光 / H3 状态可视 / H4 焊 检两用 / H5 百元内 / H6 多场景适配）。

成员 | 方案构想（核心思路 2-3 句） | 所回应的用户需求
邵子中 | ① 强磁万向悬停臂：N42 钕铁硼磁铁（φ20×5mm）吸附金属台 面，Ø6mm 不锈钢柔性臂 360° 悬停不回弹。② 触控滑条无级调 光：电容滑条加 20kHz PWM 恒流，1% 到 100% 平滑无频闪。③ 高显指双色温灯板：2835 阵列 Ra≥90，4000K 焊接、5000K 检 查。 | ① H1/H6；② H1；③ H4
李昊桐 | ① 环境感知自动调光：光敏传感器加 MCU 分档算法自动跟亮度， 保留手动覆写，AI 落点。② 18650 + TYPE-C 双模供电：桌面插电 与电池两用，强光 4 小时以上、弱光 16 小时以上。③ OLED 状态 屏：0.91 寸 SSD1306 显示电量（1% 精度）、档位、色温，低功耗 待机。 | ① H2；② H5；③ H3

姜亚楷 ① 快拆模组头：筒光、面光、放大镜三个头卡口快换，焊和检一步 切换。② 角度刻度环：底座 15° 刻度槽，常用角度一键复位。③ 绝 缘缓冲磁吸垫：硅胶包磁铁加套筒，防刮桌面，兼容铁架、磁性板、 磁力座。

① H4；② H1/H6；③ H6

## 3.2 方案筛选记录

### 第一步——四标准综合评分（用户价值 / 技术可行性（原型层面）/ 创新性 / AI 赋能度，5 分制，三人评分 取平均）：

候选方案 | 用户价值 | 技术可行性 | 创新性 | AI 赋能度 | 综合（20 分 制）
A：磁吸主机（万向臂+无级调光+状 态显示） | 5 | 5 | 4 | 3 | 17
B：环境感知自适应调光（AI 落点） | 4 | 4 | 4 | 5 | 17
C：快拆模组头（筒/面/放大镜） | 4 | 4 | 4 | 2 | 14

### 第二步——投票（每人 3 票，共 9 票）：

候选方案（得票 ≥2 的方案） | 票数 | 综合点评
方案 A：磁吸主机（邵子中 ① + 姜亚楷 ③ 合并） | 4 | 用户价值和可行性双高。全成熟件，两周出原型没有 问题。
方案 B：环境感知自适应调光（李昊桐 ①） | 3 | 靠“AI 赋能度”5 分胜出，这是全案 AI 的落点。采用 自动分档加手动覆写的设计，避免机器替人做主；出 问题时手动兜底。
方案 C：快拆模组头（姜亚楷 ①） | 2 | 差异化最大，焊检两用，但属于加分项，排在主机与 调光之后，列为 MVP 后的迭代。
其余方案（刻度环、双色温、双模供电 等共 6 个） | 0 | 并入 A 方案作为默认特性（双色温和双模供电都是主

### 机标配）。 筛选结论：方案 A 进 MVP，方案 B 作为 MVP 的核心升级路径同步验证（光敏分档的简化实现嵌入 A），方案

## C 留作迭代方向。 四、MVP 验证规划

## 4.1 核心假设清单（针对三个备选方案）

方案 | 最核心假设（不成立则方案失 败） | 最小成本验证方式 | 成功/失败标准（量化）
A：磁吸主机 | “N42 磁铁（拉力 ≥2.5kg）+ | 3D 打印外壳加磁铁、柔性臂、灯 | ≥80% 测试者报告全程

| 万向悬停臂（角度漂移 <1°）” 能让焊接者全程解放双手 | 板、旋钮调光、OLED 组出物理原 型（整机 BOM ≤50 元），5 名测 试者在真实焊台各焊 20 颗 0603 电阻 | 无需手扶灯具；平均单 颗焊接时间较台灯组缩 短 ≥25%；无“照不到 焊点”报告
B：自适应调光 | 环境光感知自动分档比“手动三 档”更省心（行为指标：减少调 光中断） | 外接 BH1750 光敏模块（实验板验 证，量产版集成）嵌入 A 原型，观 察 5 名测试者 20 颗焊点中的手动 调光次数 | ≥70% 测试者认为自动 档优于手动；调光中断 次数比纯手动组下降 ≥50%
C：快拆模组头 | “焊”和“检”两个动作需要不 同光斑（筒光/面光） | 两个简版模组头卡口手工快换，实 物演示对比 | ≥70% 测试者认为值得 做；低于该值降级为放 大镜附件

## 4.2 MVP 验证规划（优先方案 A，嵌入 B 的简化验证）

规划项 | 内容
MVP 形态 | 物理装置 + 已完成的 PCBA 样机（BOM_TYPE-A_PCB2_2026-08-23，共 34 行 56 个位 号）：主控 CW32L010F8P6（TSSOP-20，32 位 MCU）；照明链路为矽力杰 SY7200AABC 升压恒流驱动（SOT-23-6）+ 5.6uH 升压电感（YHNR3015-5R6M）驱动 10 颗 OSRAM GW JTLPS1 白光灯珠；电源管理为英集芯 IP5306（18650 充放电一体， TYPE-C 6P 输入，带 4 路电量 LED），外配 ME6211C33M5G-N（3.3V LDO）与 DW01+8205A 锂电池保护，SS54 肖特基 ×2；交互为 5× TS24CA 轻触开关与 0.91 寸 OLED（SSD1306，经 H1 排针外接，后续版本集成）；板载 6 颗红色 LED（4 颗电量 + 2 颗充电指示）。
验证目标 | ① 核心假设 A：磁吸固定加万向悬停是否真正解放双手；② 次级假设 B：光敏自动四档是否 优于手动调光；③ 整机可用性：按键与屏显的交互是否直观。
测试对象 | 与目标用户画像一致的 3 人：DIY 极客（高频焊接）、课程实训学生（电子工艺课）、研发 工程师（实验室调试）；另取 2 名普通焊接初学者对照。
测试场景 | 真实焊台独立焊接 30 分钟，连续焊 20 颗 0603 电阻（含 1 颗故意失误后的返工），记录照 明体验、调光次数、时长与返工数。对照组用传统台灯完成同样的 20 颗。
成功标准 | ① 磁吸组 ≥80% 测试者全程无需手扶灯具；② 平均单颗焊接时间缩短 ≥25%；③ ≥70% 认 为自动调光优于手动；④ 手机镜头对准灯面无频闪条纹（20kHz PWM 验证）；⑤ 吸附拉力 ≥2.5kg（弹簧秤实测）。
时间与资源计划 | 两周：第 1 周（D1-D3 结构件打印与磁吸机构装配；D4-D6 灯板调试与 PWM 调光标定； D7 整机组装与参数标定）；第 2 周（D8-D10 五位测试者实测与数据统计；D11 一轮迭代改 1-2 处；D12-D14 复盘与报告编写）。资源：实验室 3D 打印机、现有 PCBA 样机、万用表/ 示波器、恒温烙铁；PCBA 器件按 LCSC 批量价估算约 25-35 元，机构件（N42 磁铁 2 元、

柔性臂 8 元、外壳 12 元），整机 BOM ≤50 元；两轮打样加辅料总预算约 500 元。 五、与竞赛评审标准的对应

### 评审五维度权重（据课程课件）：创造性 10%、实用性 40%、安全性 20%、深度性 15%、规范性 15%。分析深 度按权重分配，实用性（40%）重点论证。

评审维度（权 重） | 本选题的潜力分析
创造性 （10%） | 结构加交互的组合创新：万向磁吸固定把机床灯的固定照明能力缩小到掌心；触控滑条 加 OLED 状态屏把“看亮度”变成“看状态”；环境感知调光让光跟着人走。市面现有 产品没有这样的组合。
实用性 （40%，权重 最高） | 【用户覆盖广度】三级用户全覆盖：高校电子类专业学生（实训与毕设，基数最大）、 DIY 极客（社区活跃，传播快）、研发维修工程师（专业买单意愿强）。产品形态决定 了只要焊台是铁的就能用。 【需求刚需强度】126 份问卷：84.13% 每周焊 3 次以上，76.98% 依赖精细补光， 71.43% 工位空间受限，100% 需要解放双手。三类现有灯具的痛点占比均过半 （68.25% / 61.11% / 54.76%）。沉浸式体验里无灯失败率 50%、台灯 30%、手机手 电 20% 的梯度，说明照明方案直接决定焊接质量，不是“有没有光”的小事。 【价格可达性】整机 BOM ≤50 元（PCBA 25-35 元加机构件），目标零售 59-79 元， 对比几百元的专业灯有明确价格优势，学生买得起。
安全性 （20%） | 供电安全：18650 锂电池配 DW01+8205A 过充过放与短路保护，TYPE-C 可拆装电池 仓；光安全：低蓝光高显指灯珠（Ra≥90），20kHz PWM 无可视频闪；热安全：灯板 铝基板加导热胶，连续工作表面温度 ≤60℃；使用安全：磁铁硅胶包覆防夹手、防刮 花，边缘倒角。
深度性 （15%） | 从“能调光的手电”到完整系统：传感（光敏、电量、按键）、控制（CW32L010 调光 与分档算法）、驱动（SY7200A 升压恒流 20kHz PWM）、电源（IP5306 充放电管 理）、显示（OLED 与 LED 指示），再到感知闭环。照明单品之外，能向“智能焊接工 位终端”方向走一步。
规范性 （15%） | RoHS/CE/FCC/3C 认证路径已规划；BOM 表、原理图、测试报告齐套，对接 IPC-A- 610 焊接质量标准；状态数据（电量、亮度、使用时长）口径预留标准化接口（OPC UA 语义对齐），给实验室设备管理和产线焊台监测留了接入能力，对应“能力范式”的

## 行业层面含义。 六、设计思维应用反思

### ① 最难的环节是定义阶段，难在这个小工具怎么和“AI+OPC 能力范式”对上。卡住的时间主要有三点：第 一，共情期信息多，3 份记录加 126 份问卷，讨论到第二轮我们同时惦记了 8 个功能点；第二，三个人都是 D 型（大象组合），谁也说服不了谁，一度变成谁嗓门大听谁的；第三是评审的 AI 赋能度和用户真实需求 之间有张力，用户只说“照得清楚、不占手”，根本不在乎 AI。我们最后定的标准很简单：AI 必须是一个 真实存在的环节，装上去干活，拆掉明显缺一块。环境光感知到自动调光是这么定下来的，同时保留手动覆 写，免得机器替人做主。OPC 没有硬塞，放在工位数字化生态的中期接口上。

### ② 工具作用最大的是 HMW 格式，配上四标准评分表。吵得最凶的是要不要做自动调光，三个人里两个反 对，理由是怕多调试成本。我们停下来把“想做一盏能调光的手电”改写成“我们如何帮助手工焊接者在光 线激烈变化的环境里，免于反复手动调节亮度”。写完争议就没了：午后 2 点半到傍晚，窗边焊盘的反光变 化肉眼可见，问题成立。之后四标准评分，B 方案 AI 赋能度 5 分，自动调光进 MVP 升级路径就有了依 据。实践证明，打分比吵架高效。

③ 课堂“物品遗留”演练，用户就是同学，我们自己也能沉浸式体验。焊接这个场景我们仨正好都是使用 者，算半专业用户，沉浸式体验做得比较真，20 颗 0603 的失败率梯度（无灯 50%、台灯 30%、手电 20%）是实打实测出来的。但陷阱也有：容易按技术组的标准高估别人，也容易低估价格敏感度。我们做了 四点调整：一是洞察三线并用，访谈、观察、沉浸式各一份，观察对象刻意找了一个非技术背景的课程实训 学生；二是用 126 份问卷把个别感受铺开成群体分布；三是把课堂上的开放式问题收窄成 5W1H 的结构化 问题，换回来“大灯照不到，小灯转天就歪，我干脆手拿着焊”这种能直接引用的原话；四是每条结论都标 了出处，问卷占比或观察时间点，避免“我们觉得”冒充“用户需要”。

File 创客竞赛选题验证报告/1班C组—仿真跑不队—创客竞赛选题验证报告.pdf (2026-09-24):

# 《创客竞赛选题验证报告》

## 创新方法应用——创客竞赛选题验证（课后教学活动一）

## 团队编号：1 班 C 组 团队名称：仿真跑不队

## 团队成员：邵子中（负责人）、李昊桐、姜亚楷

## 验证对象选题：磁吸焊接辅助手电

## 日期：2026 年 8 月 2 5 日

## 一、选题概述

要素 | 内容
选题名称 | 磁吸焊接辅助手电——一吸即用、指哪照哪的焊接照明工具
用户与场景 | 目标用户：高校电子类专业学生、DIY 极客、研发维修工程师；场景：狭小焊台手 工焊接（0603/QFN 级）与焊点检查，每周 ≥3 次使用频率。
核心价值主张 | 给焊接者一双腾出来的手：磁吸固定解放双手，万向悬停指哪照哪，无级调光适配 光环境，目标零售 59-79 元（对比专业灯 300 元+）。
选题来源 | 延续自设计思维工作坊课后《创客竞赛选题设计报告》（从 0 到 1 已确定方向与本 轮候审方案）。
与“AI+OPC”主题 关联 | AI：环境感知自动调光（感知-决策-执行闭环）；OPC：焊接工位数字化生态的标 准数据接口（中期扩展，状态数据按标准协议上报实验室/产线管理系统）。

## 二、SCAMPER 系统审查结论

维度 | 审查问题（针对磁吸焊接手 电） | 审查发现（问题/风险/机会） | 归类
S（替 代） | 方案中哪些要素可被替代？灯 珠、驱动、磁吸材料、用户群 体？ | ① 灯珠替代：10 颗 OSRAM 白光（BOM ¥6）替代为单颗 COB（BOM ¥2.5，成本降 60%）——但高显指 （Ra≥90）难保证，与 76.98% 用户“精细补光”诉求冲 突；② 调光替代：20kHz PWM 替代为模拟线性调光—— 低亮度下频闪风险显著；③ 用户群体替代：从“焊接者”扩 到“手工/维修/夜读”场景。 | 【采纳】维持 OSRAM+20kHz PWM（显指与无 频闪优先，不冒进 替代）；【待验 证】 单颗 COB 在 Ra≥85 时用户是 否可接受（影响成 本空间）
C（合 并） | 可与什么合并？温度监测？腕 带收纳？充电座？ | ① 与焊接温度提醒合并（热电偶+蜂鸣，+¥4-6）：直击 “焊台过热难察觉”但增开发量；② 与防静电腕带收纳合并 （+¥1）：低成本高感知；③ 磁吸座兼充电座：结构上天然 可行。 | 【采纳】腕带收纳 与磁吸充电座合并 （零风险）；【待 验证】 是否值得 为温度提醒支付 +15 元溢价
A（适 应） | 有没有其他领域的成熟做法可 直接迁移？ | ① 借鉴摄影灯与机床灯：万向调节的通用球头/软管结构 （Ø6mm 不锈钢柔性臂即来自补光灯产业链）；② 医疗台 灯的食品级软管与防刮胶套（对应我们的硅胶磁吸垫）；③ 相机稳定器电池仓布局（IP5306 应用成熟）。 | 【采纳】结构件全 部采用成熟供应链 方案（无技术断供 风险）
M（调 整） | 功能强度、覆盖范围、目标用 户规模能否放大/缩小？ | ① 放大：2600mAh 高配版（+¥8），适应“整晚焊接”场 景；② 缩小：无屏“青春版”（¥39-49 档）覆盖价格敏感 初学者；③ 用户规模：三类用户 × 年新增学生群体，覆盖 | 【采纳】双版本策 略（标准版+青春 版）直接采纳；

| | 基数大。 | 【待验证】 高配 版溢价用户是否买 单
P（改变 用途） | 除了焊接照明，还能服务什么 场景？ | 整机取下即手电：维修照明、露营、夜读、宿舍夜灯；磁吸 座+灯体可作简易手机支架（磁吸座的第二用途，开发成本 几乎为零）。 | 【采纳】作为宣传 卖点采纳（不投入 验证资源，避免方 向发散）
E（消 除） | 什么功能/环节可简化或去 除？去除后影响核心价值吗？ | ① 现 PCBA（34 行 56 位号）已用 6 颗红色 LED（4 电量 +2 充电指示）实现状态显示，而未集成 OLED（原 PPT 宣 传“OLED 状态显示”）——**宣传口径与实物不一致**， 评委可能当场指出；② 旋钮机械件已消除（触控/按键调 光）。 | 【待验证】【重 点】LED 状态灯 能否替代 OLED 的 80% 状态查询 需求（卖点真实性 问题，需实验验 证）
R（重组/ 逆向） | 流程或结构能否重组？逆向思 考方案是否仍成立？ | ① 逆向：把“先做整机卖”改为“先发 DIY 套件”：学生 自己焊接组装（创客教育属性，深度性加分），成品再售 卖；② 重组：磁吸座作为标准配件单独销售、兼容各型号灯 体，形成“底座生态”。 | 【采纳】参赛版改 “自制套件”展示 （提升深度性）； 【待验证】 用户 是否愿意自己动手 组装（套件化决 策）

## 审查结论归纳

类别 | 结论
优势维度 | A（结构全成熟件、无断供风险）、S 的保守策略（显指优先）、M 的双版本分层 ——这三个维度证明方案在“可制造性、用户体验底线、价格分层”上逻辑自洽。
薄弱维度 | E（最大薄弱点：宣传的 OLED 与实物的 LED 指示不符）、C（温度提醒溢价不确 定）、M 放大项（高配溢价不确定）、R（套件化意愿未知）。
待验证假设清单（格 式：我们假设…… 在……条件下成立） | 假设 1（最高优先）：我们假设“6 颗 LED 状态灯（4 电量+2 充电）能覆盖用户 80% 的状态查询需求”，在无屏样机与 OLED 外接版 20 人 A/B 对比测试条件下 成立。 假设 2：我们假设用户愿意为“温度过热提醒”支付 +15 元，在 59-79 元目标价 位区间内成立。 假设 3：我们假设“青春版（¥39-49 无屏版）”能覆盖 20% 以上的价格敏感用 户，在与标准版同时展示时成立。 假设 4：我们假设 2600mAh 高配版（+¥8）有 ≥20% 用户选择，在双版本同时售 卖的条件下成立。 假设 5：我们假设柔性臂 3000 次弯折后角度漂移仍 <5°，在实验室疲劳测试条件 下成立。

## 三、六顶思考帽综合评估结论

角色分配：蓝帽（主持）=邵子中；白帽=李昊桐；红帽=三人各自 1 句；黄帽=姜亚楷；黑帽=李昊桐；绿帽=三

人共同（姜亚楷主导）。

帽子 | 发言摘要
白帽（事实） | ① 问卷 126 份：84.13% 每周焊 ≥3 次、76.98% 依赖精细补光、100% 需双手、三痛点占比 68.25%/61.11%/54.76%；② 沉浸式实测：无灯失败率 50%→台灯 30%→手电 20%；③ 现 PCBA 34 行 56 位号、BOM ¥25-35；整机目标价 59-79 元；④ 竞品价格带：台灯 60-200、廉价灯 20-49、专业灯 300+；⑤ 竞赛评审权重：实用性 40%（最高）、安全性 20%。
红帽（直觉） | 邵：“这产品能卖，但选型时 OLED 没了，我总感觉不踏实。”李：“我喜欢它轻巧，但担 心连续焊 20 分钟灯体烫。”姜：“我直觉学生愿意掏 59，不一定掏 79。”
黄帽（乐观） | 磁吸+万向悬停是真实差异点，竞品无对应形态；单价低、高频刚需、三类用户全覆盖；DIY 社区传播性强（晒图属性）；竞赛评审“实用性 40%”权重下优势明显；自制套件版还能强 化“深度性”。
黑帽（悲观） | ① 最大风险：宣传（OLED）与样机（LED 指示）不符，答辩会被当场质疑；② 小批量外壳 与柔性臂成本高于预估，59 元可能守不住；③ 机构门槛低，大厂 3 个月可仿制；④ 3 人团 队竞赛周期内同时磨硬件+测试，时间不够；⑤ 锂电池组合的合规与认证成本（3C）。
绿帽（创造） | ① OLED 降级为“选配扩展模块”（H1 排针已预留，展示时接上），标配套成 LED 灯+低成 本；② 用 NTC 贴片（¥0.3-0.5）测灯板温度做“过温提示”替代热电偶（解决红帽“烫 手”→同时解决黑帽①的部分担忧）；③ 双 SKU 分层（青春版 39-49/标准版 59-79）；④ 答辩前把“无屏版+OLED 模块”做成对比演示展板，把劣势变成“可讲解的迭代设计”。
蓝帽（总结） | 讨论目标：这个方案是否值得做、要怎么做。20 分钟讨论结论：值得做，但需“先补证再定 稿”。决策倾向：调整后推进——调整项：① 宣传口径与实物对齐（OLED 改为选配扩展模 块，标配 LED 状态灯）；② 低成本补“过温提示”（NTC）；③ 双版本策略待 MVP 验证后 定稿；④ 套件化暂缓，作为演示环节而非产品线。

### 初步决策结论：倾向【调整后推进】。理由（黄帽+白帽依据）：需求真实性有问卷与实测双重证据，方案

### 在评审权重最高的实用性维度上表现强，且调整项均为低成本改动；仍需验证（黑帽顾虑）：① 验证假设 1

### （LED 替代 OLED 的可用性）——这是“宣传与实物一致”问题的关键证据；② 验证假设 2/3（价格带接

### 受度）；③ 过温测试确认 NTC 方案有效。

## 四、MVP 验证规划

## 4.1 核心假设清单

优先级 | 核心假设 | 如果成立/失败的意义
假设 1（核 心） | 我们假设 6 颗 LED 状态灯（4 电量+2 充电指示灯）能覆盖用 户 80% 的状态查询需求，在 25 分钟真实焊接过程中成立 | 成立 → 无屏版可作为标准 版投产，宣传口径锁定 “LED 状态灯+OLED 选

| | 配”；不成立 → 需集成 OLED（+¥5、+1 周）， 或改宣传
假设 2（次 级） | 我们假设目标用户在 59-79 元价位有明确购买意愿（≥60% 愿 意购买，≥40% 选择 59 元档） | 成立 → 维持现有 BOM 预 算；不成立 → 压缩 BOM （取消 OLED 模块/降级外 壳）至 39-49 元档

## 4.2 MVP 验证设计方案

规划项 | 内容
MVP 形态 | 物理装置样机 A/B 对比 + 虚拟支付问卷。A 组：现有 PCBA 无屏样机（LED 状态灯）；B 组：同款样机+OLED 扩展模块（经 H1 排针外接，后续版本集成）。两组外观一致（仅显示 方式不同），避免外观偏见。
验证目标 | ① 假设 1：LED 灯与 OLED 在真实焊接中的状态查询效率是否等价；② 假设 2：59-79 元价 格带的购买意愿。
测试对象 | 与目标用户画像一致的 20 人：DIY 极客 4、课程实训生 4、研发工程师 4、焊接初学者 8 （对照组，考察非技术用户）。
测试场景 | 电工基地实验室真实焊台，连续焊接 25 分钟（20 颗 0603 电阻），环境光按“下午 3 点靠 窗”模拟；测试期间随机打断询问“现在电量/档位是多少”，记录确认动作与耗时。
成功标准 | ① ≥70% 测试者 25 分钟内状态查询 ≤2 次且耗时 ≤5 秒/次（A 组与 B 组差异 <10%）；② ≥60% 愿意购买（≤59 元档 ≥40%）；③ A 组主观评分 ≥4/5。
失败标准 | ① A 组查询效率显著低于 B 组（差异 ≥30%）或主观评分 <3/5；② 购买意愿 <40%；满足 其一即判定假设不成立，转入“集成 OLED 版”或“降价版”路线。

## 4.3 5W2H 实施规划表

维度 | 引导问题 | 具体内容
Why | 为什么要做这个 MVP 验证？ | 证明“LED 指示灯替代 OLED”成立（假设 1）并锁定价格带（假设 2），为最终决策提供证据，回答“值不值得做、怎么做”
What | MVP 做什么？ | 20 人×25 分钟真实焊接 A/B 对比测试 + 虚拟支付问卷（两版展示 39/59/79 元档）
Who | 谁来执行？谁是测试对 象？ | 执行：邵子中（主持与数据）、李昊桐（样机调校）、姜亚楷（招募与 场景）；对象：画像一致的 20 名测试者
When | 何时完成？ | D1-2 招募与问卷设计；D3-4 集中测试（每天 10 人）；D5 数据统 计；D6 结论与报告
Where | 什么场景？ | 电工基地实验室焊台（真实使用环境，非演示室）
How（≥3 步） | 具体步骤？ | ① 随机分组 A/B 各 10 人，先测状态查询效率：焊接中随机打断，记录 “确认电量/档位”动作的次数与耗时；② 交换组别重测一次（消除个 体差异）并完成 25 分钟焊接计时；③ 虚拟支付：展示 39/59/79 三档 卡片，各自勾选“会买/考虑/不买”，统计意愿分布；④ 汇总数据，对 照成功/失败标准出结论

How much | 投入与产出？ | 成本 ≈300 元（OLED 模块 ¥20、测试礼品 ¥150、往返布耗 ¥50、杂
| | 项 ¥80）；时间 6 天；产出：20 份有效测试记录、验证结论报告
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

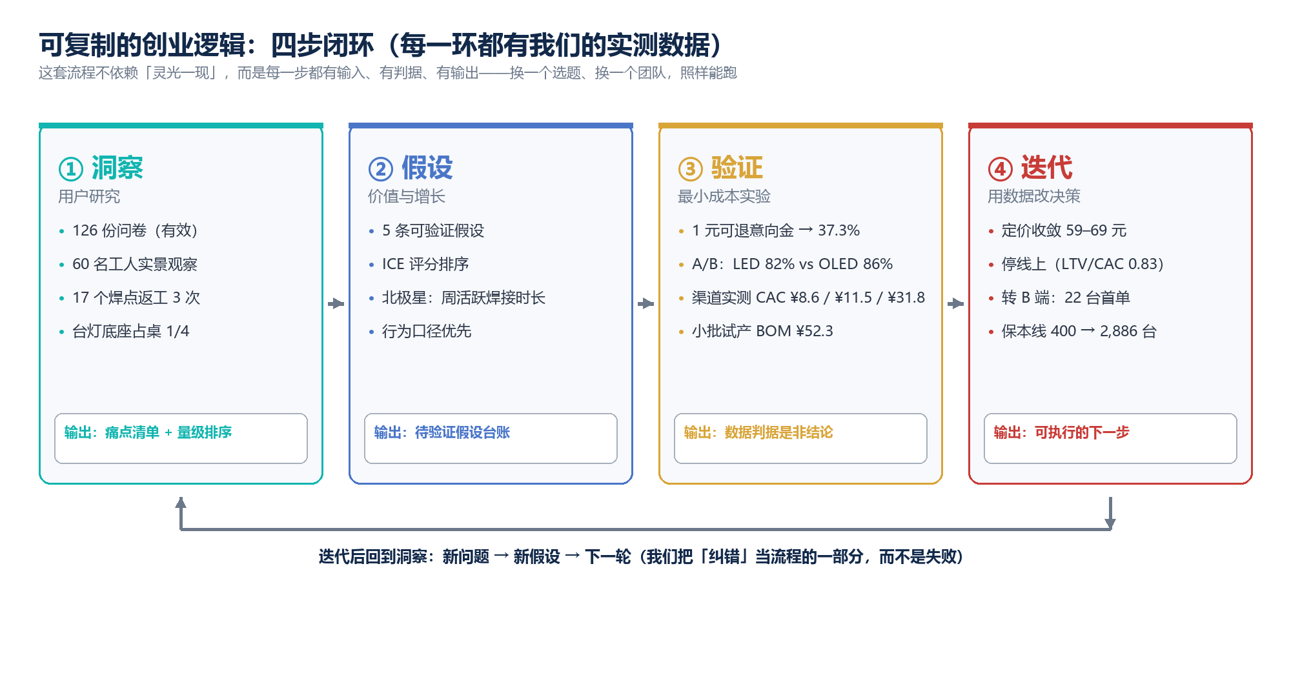
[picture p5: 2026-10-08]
演示资源/figs/fig1_创业逻辑闭环.png

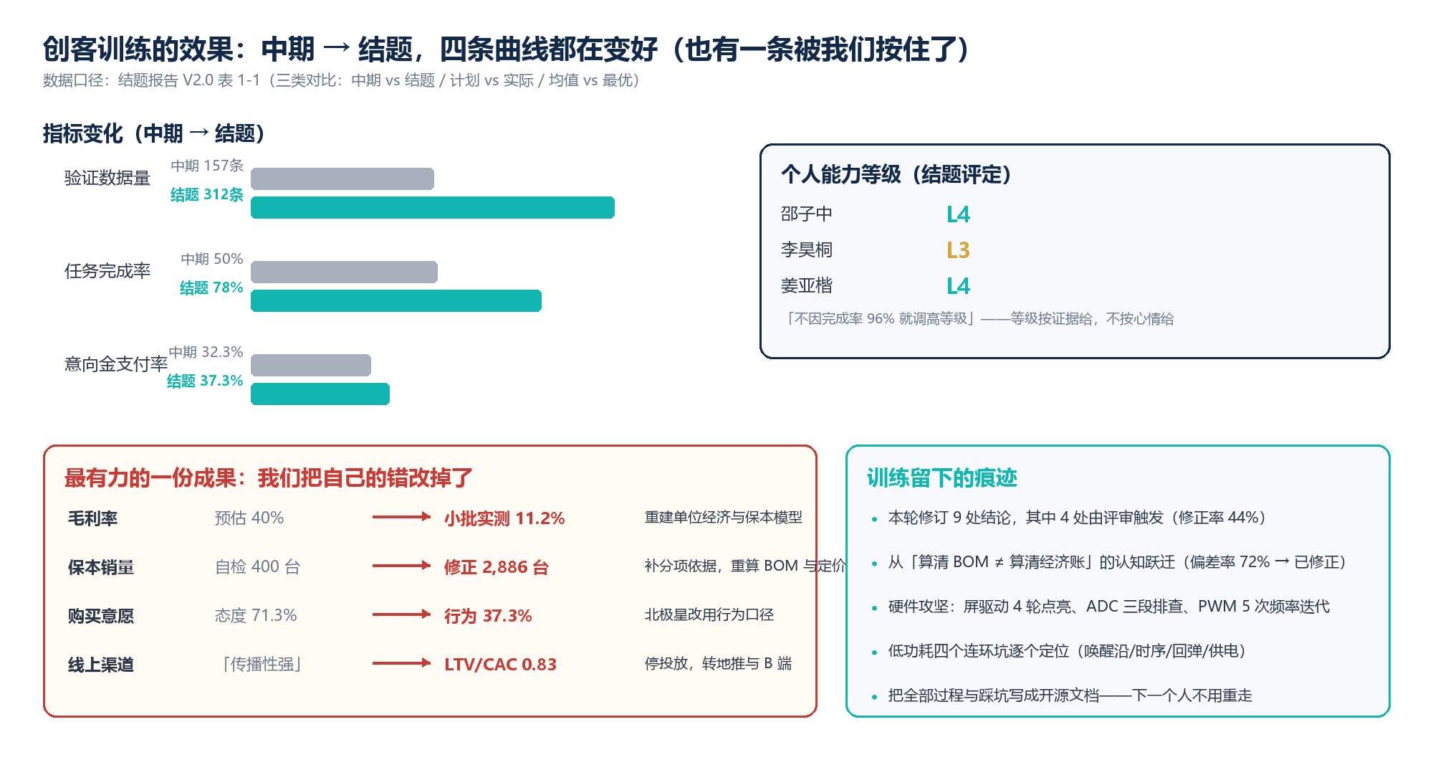
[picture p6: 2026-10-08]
演示资源/figs/fig3_训练效果.png

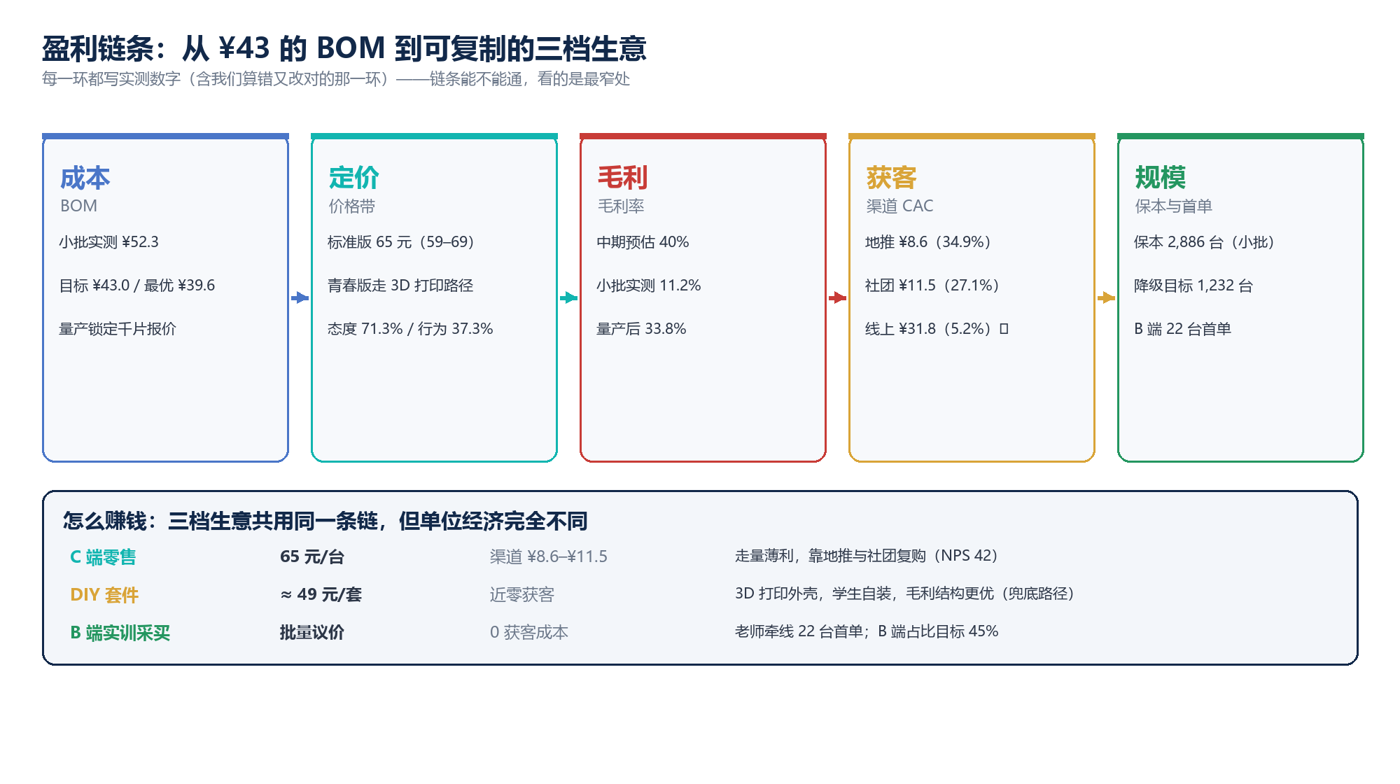
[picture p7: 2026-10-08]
演示资源/figs/fig2_盈利链条.png

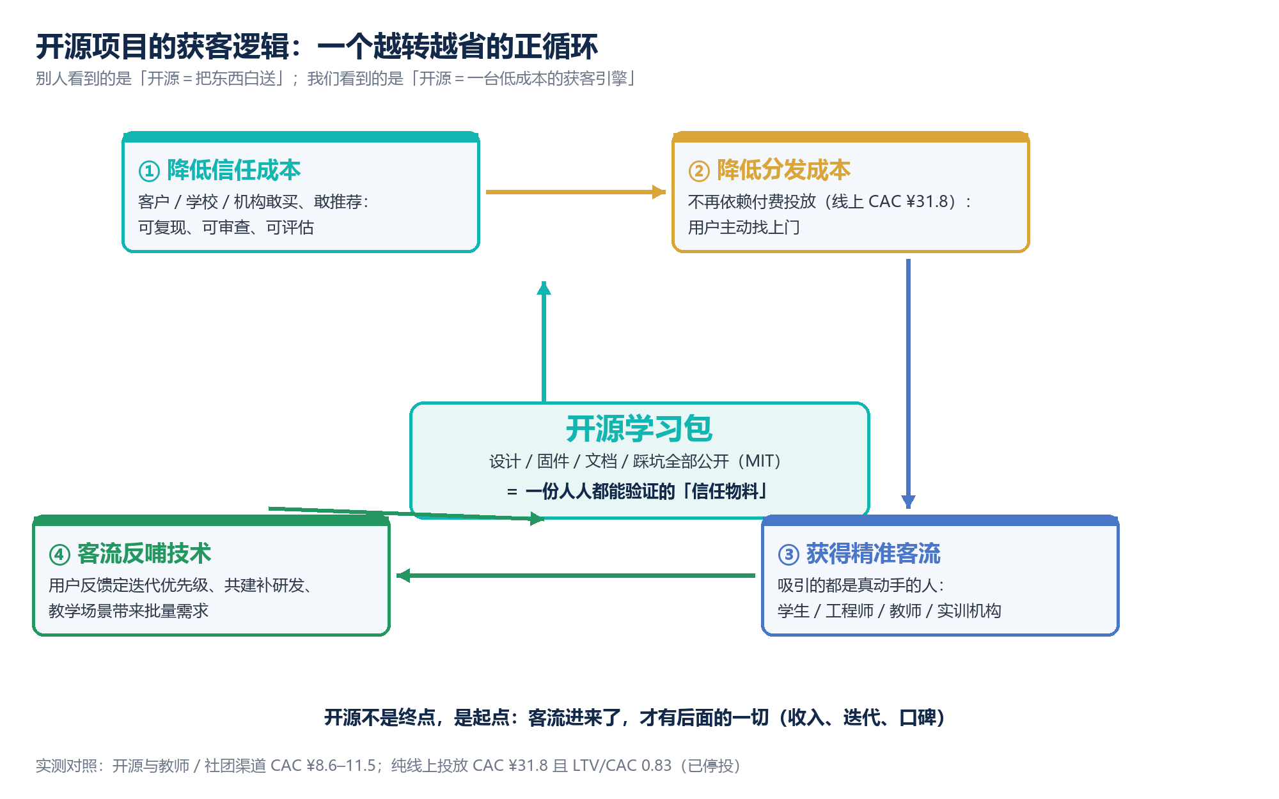
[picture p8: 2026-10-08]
演示资源/figs/fig4_开源获客逻辑.png

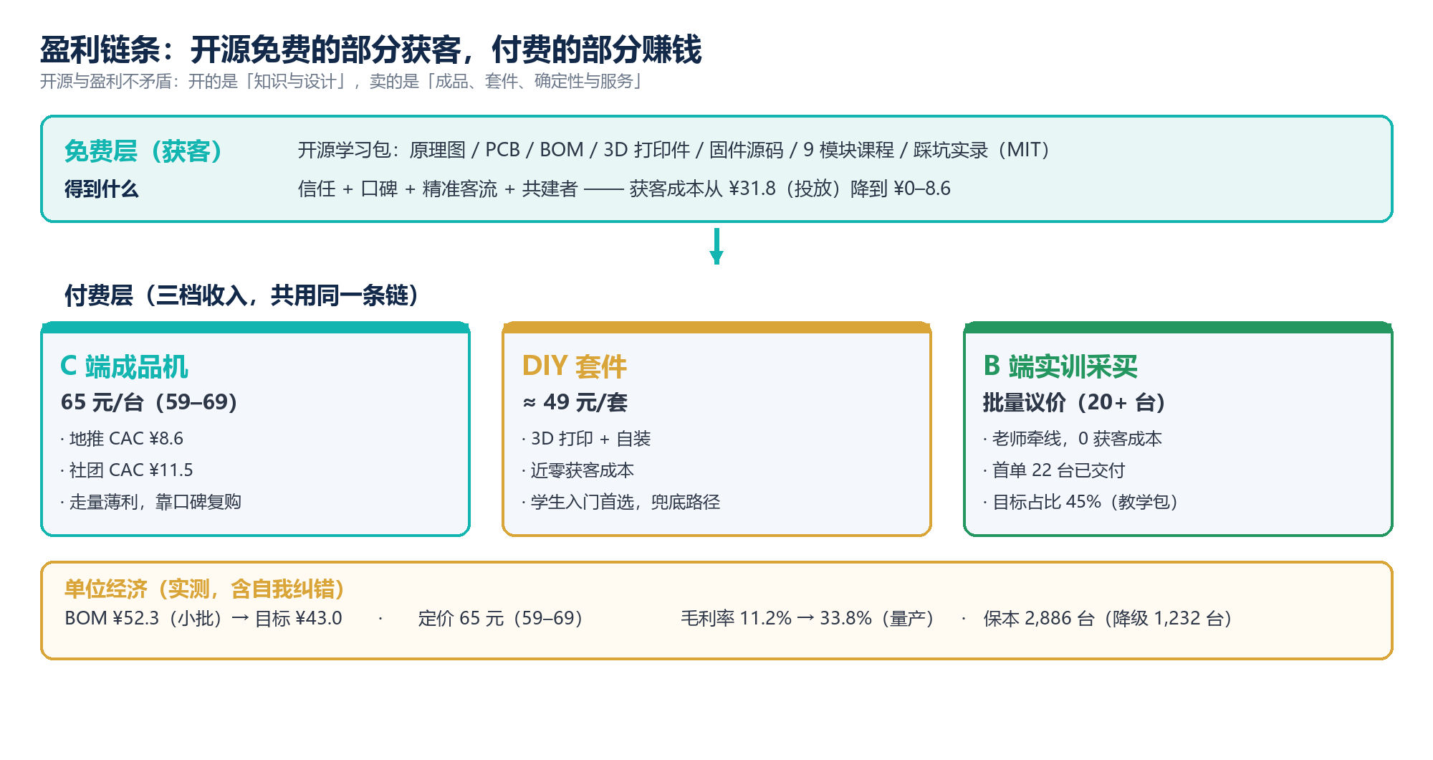
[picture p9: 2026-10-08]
演示资源/figs/fig5_盈利链条.png

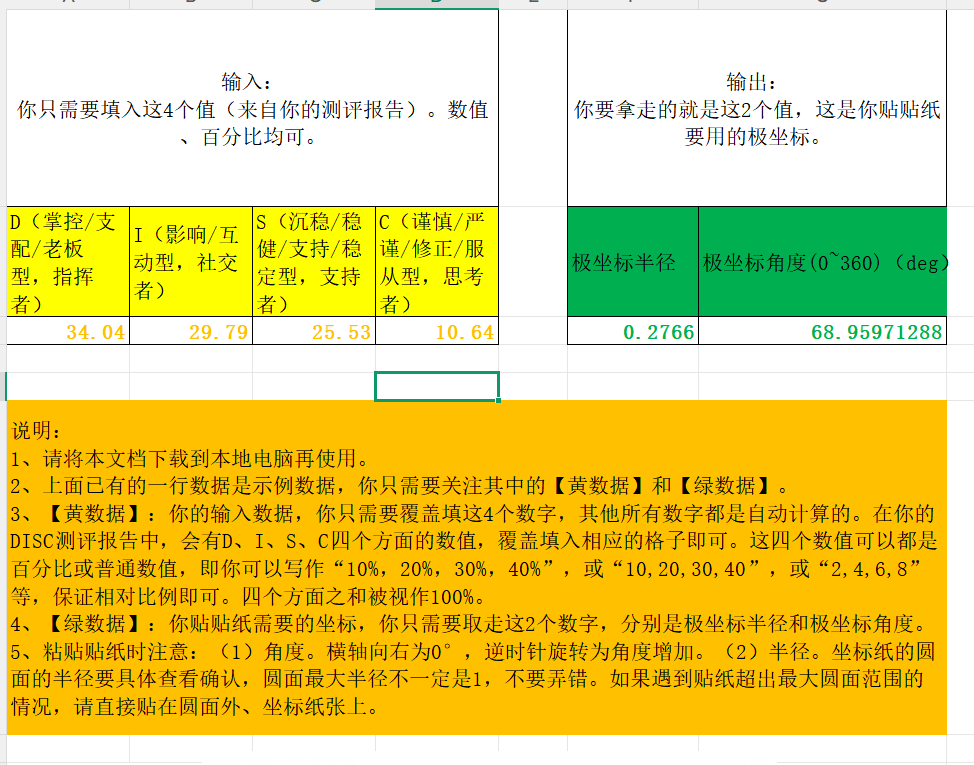
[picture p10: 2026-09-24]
创客训练营-2026第1课课前任务/DISC测评结果-极坐标表.png

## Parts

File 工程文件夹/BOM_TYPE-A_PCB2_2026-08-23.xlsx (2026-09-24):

No. | Quantity | Comment | Designator | Footprint | Value | Manufacturer Part | Manufacturer | Supplier Part | Supplier
1 | 1 | BH-18650-B1BA002 | BT1 | BATTERY-SMD_18650-1S-L77.1-W20.7-1 |  | BH-18650-B1BA002 | MYOUNG(美阳) | C2988620 | LCSC
2 | 1 | 100n | C1 | C0402
3 | 3 | 100nF | C4,C5,C11 | C0402 | 100nF
4 | 7 | 22uF | C6,C7,C8,C14,C15,C16,C17 | C1206 | 22uF | CL31A226KAHNNNE | SAMSUNG(三星) | C12891 | LCSC
5 | 2 | 10uF | C9,C10 | C1206 | 10uF | CL31A106KBHNNNE | SAMSUNG(三星) | C13585 | LCSC
6 | 2 | 1uF | C12,C13 | C0603 | 1uF
7 | 3 | 0402 | C,C2,C3 | C0402
8 | 2 | SS54 | D1$CBB3,D1$CBB5 | SMA_L4.3-W2.6-LS5.0-FD |  | SS54 | R+O(宏嘉诚) | C7420369 | LCSC
9 | 1 | PH2.54-01-04PZD | H1 | HDR-TH_4P-P2.54-V-M-1 |  | PH2.54-01-04PZD | XUNPU(讯普) | C7501582 | LCSC
10 | 2 | 5.6uH | L1$CBB3,L1$CBB5 | IND-SMD_L3.0-W3.0 | 5.6uH | YHNR3015-5R6M | YJYCOIN(益嘉源) | C18236327 | LCSC
11 | 1 | ME6211C33M5G-N | LDO2 | SOT-23-5_L3.0-W1.7-P0.95-LS2.8-BL |  | ME6211C33M5G-N | MICRONE(南京微盟) | C82942 | LCSC
12 | 10 | GW JTLPS1.EM-KLLL-XX52-1-150-R33 | LED1,LED3,LED4,LED5,LED6,LED7,LED8,LED9,LED10,LED11 | LED-SMD_L3.5-W2.8-RD |  | GW JTLPS1.EM-KLLL-XX52-1-150-R33 | OSRAM(欧司朗) | C17391670 | LCSC
13 | 2 | KT-0603R | LED2,LED12 | LED0603-RD |  | KT-0603R | KENTO | C2286 | LCSC
14 | 4 | XL-1608SURC-06 | LED13,LED14,LED15,LED16 | LED0603-RD_RED |  | XL-1608SURC-06 | XINGLIGHT(成兴光) | C965799 | LCSC
15 | 1 | 8205A | Q1 | TSSOP-8_L4.4-W3.0-P0.65-LS6.4-BL |  | 8205A | HL(富海微) | C7499846 | LCSC
16 | 2 | 1.3Ω | R1$CBB3,R1$CBB5 | R1206 | 1.3Ω | 1206W4F0000T5E | UNI-ROYAL(厚声) |  | LCSC
17 | 7 | 电阻0603 | R1,R2,R3,R4,R5,R6,R7 | R0603_SMD-CRCW060327R0FKEA
18 | 1 | 10K | R8 | R0603 | 10K
19 | 2 | 5.1k | R9,R10 | R0603 | 5.1k
20 | 1 | 2Ω | R11 | R0603 | 2Ω | 0603WAF200KT5E | UNI-ROYAL(厚声) | C22977 | LCSC
21 | 1 | 10k | R12 | R0603 | 10k
22 | 1 | 100 | R14 | R0603 | 100
23 | 1 | 1K | R15 | R0603 | 1K
24 | 1 | 0.5R | R16 | R0603 | 0.5R
25 | 5 | TS24CA | SW1,SW2,SW3,SW4,SW5 | SW-SMD_2P-TS24CA |  | TS24CA | SHOU HAN(首韩) | C393942 | LCSC
26 | 4 | Test-Point | TP1,TP2,TP3,TP4 | Test-Point-0.5mm
27 | 1 | CW32L010F8P6 | U1 | TSSOP-20_L6.5-W4.4-P0.65-LS6.4-BL |  | CW32L010F8P6 | CW(芯源) | C41425332 | LCSC
28 | 1 | 1uH | U2 | IND-SMD_L2.5-W2.0-VLS252012CX-150M | 1uH | FTC252012S1R0MBCA | cjiang(长江微电) | C5832370 | LCSC
29 | 2 | SY7200AABC | U2$CBB3,U2$CBB5 | SOT-23-6_L2.9-W1.6-P0.95-LS2.8-BR |  | SY7200AABC | Silergy(矽力杰) | C107309 | LCSC
30 | 1 | IP5306 | U3 | ESOP-8_L4.9-W3.9-P1.27-LS6.0-BL-EP |  | IP5306 | INJOINIC(英集芯) | C181692 | LCSC
31 | 1 | DW01 | U5 | SOT-23-6_L2.9-W1.6-P0.95-LS2.8-BL |  | DW01 | JSMSEMI(杰盛微) | C917079 | LCSC
32 | 1 | TYPE-C 6P | USB2 | TYPE-C-SMD_TYPE-C-6P |  | TYPE-C 6P | SHOU HAN(首韩) | C456012 | LCSC

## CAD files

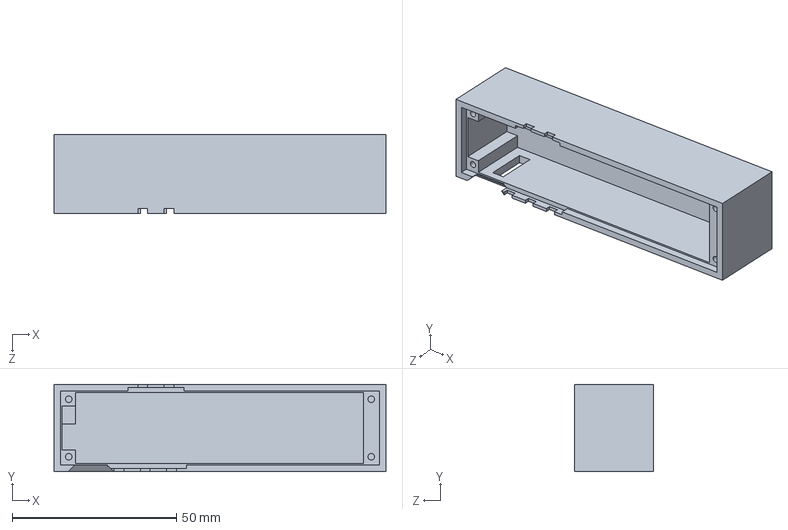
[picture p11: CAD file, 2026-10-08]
工程文件夹/3D外壳/外壳.SLDPRT
101.0 x 26.5 x 24.0 mm

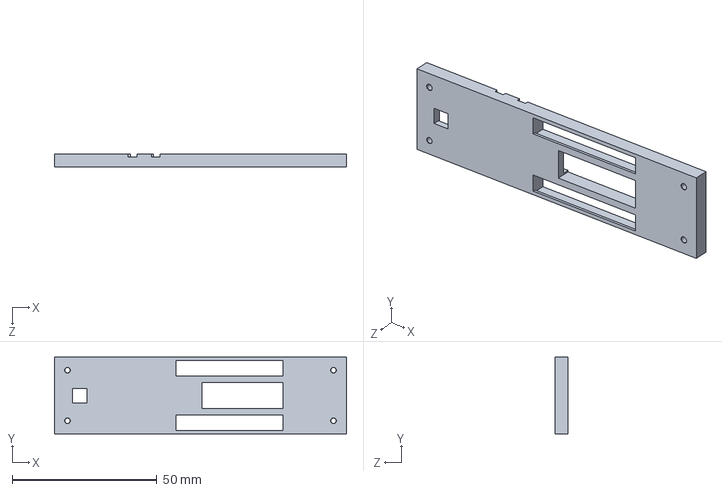
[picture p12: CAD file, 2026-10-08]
工程文件夹/3D外壳/盖子.SLDPRT
101.0 x 26.5 x 4.50 mm

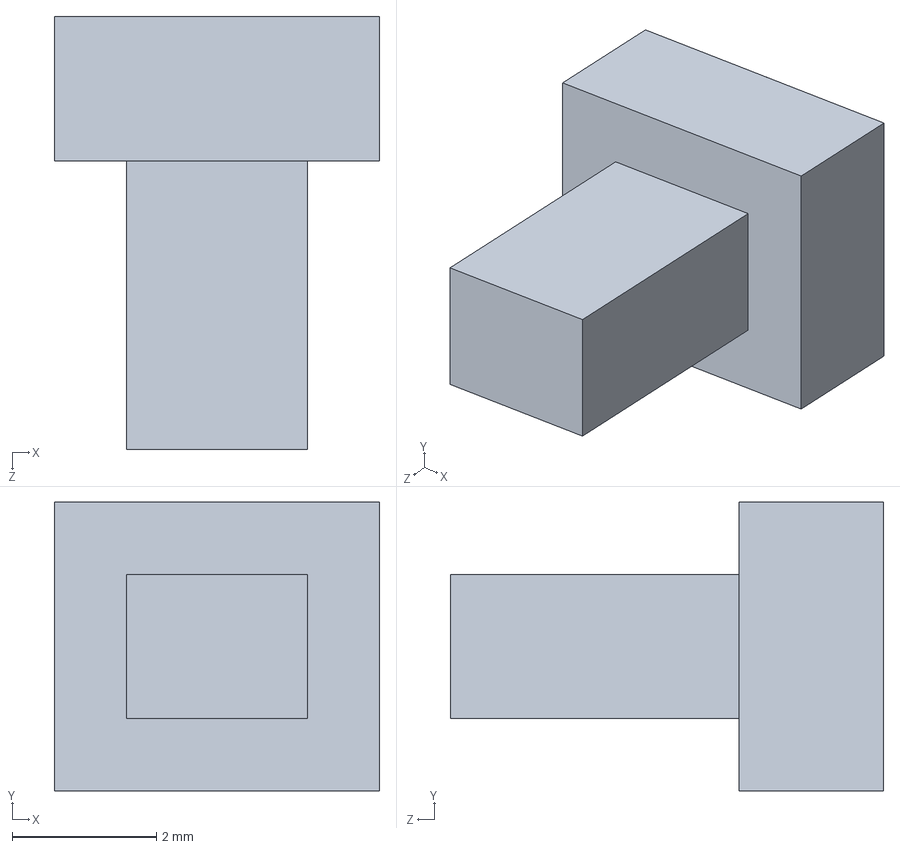
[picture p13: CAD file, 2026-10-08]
工程文件夹/3D外壳/按键帽.SLDPRT
4.50 x 4.00 x 6.00 mm

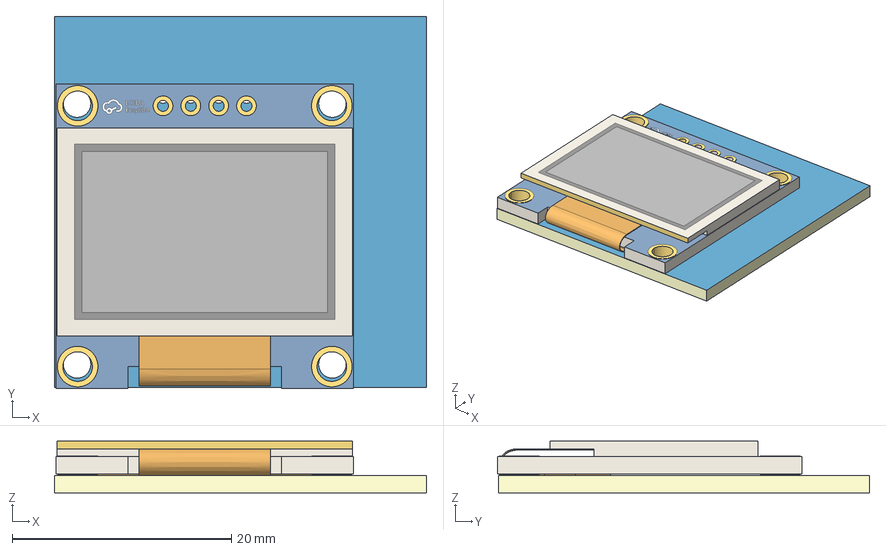
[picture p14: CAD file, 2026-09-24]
工程文件夹/3D外壳/3D_OLED.step
34.0 x 34.0 x 4.72 mm
Board~OZoH
TopCopper~OZoH
BottomCopper~OZoH
TopSilkscreen~OZoH
BottomSilkscreen~OZoH
TopFpcStiffener~OZoH
BottomFpcStiffener~OZoH
OLED-TH_L27.8-W27.2-P2.54_C9900033791~OLED-TH_L27.8-W27.2-P2.54_C9900033791~UkKy

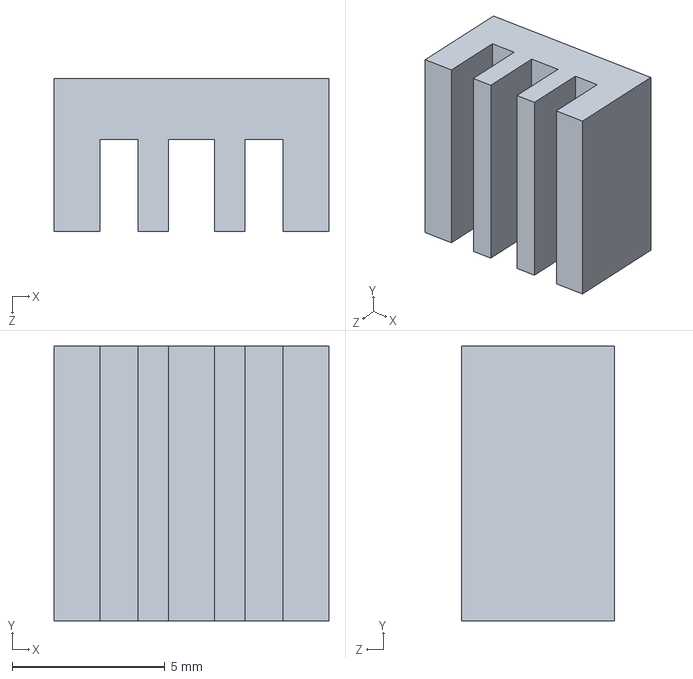
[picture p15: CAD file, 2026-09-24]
工程文件夹/3D外壳/散热片.SLDPRT
9.00 x 9.00 x 5.00 mm

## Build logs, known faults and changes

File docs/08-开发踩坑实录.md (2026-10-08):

# 08 · 开发踩坑实录（真实迭代过程）

> 这一篇是本学习包**最有价值的部分**：它记录的不是「设计好的结果」，而是
> **「真实踩过的坑 → 根因 → 解决」**。全部来自本项目的实际开发过程。
>
> 工程师的能力，大部分是在这些坑里长出来的。我们把它们完整留在这里。

---

## 阶段 1：框架搭建

- 基于 CW32 官方例程（`gpio_blink` 结构）搭 UserApp 骨架；
- 从另一块 H563 工程**移植 OLED / I2C 驱动**；
- 确定 **HSI 48MHz 单时钟方案**（无外部晶振），ATIM 输出 PWM。

> 💡 学习点：移植驱动比重写更快，但要先弄清「两边的时钟与外设假设是否一致」。

---

## 阶段 2：需求快速迭代

- **按键映射反复调整**：7 键 → 5 键 → 最终 **3 键**（PB03 开关机 / PA04 亮度− / PA05 亮度+），
  用「单击 / 长按 / 双击」把功能压缩进 3 个按键；
- 加入**磁吸吸附检测**与「外挂款 / 内置款」双型号开关；
- 建立**电池过放保护状态机**，阈值两次调整（3.5/3.2V → **3.35/3.2V**，提高电池利用率）。

> 💡 学习点：**按键越少，交互设计越重要**。功能不是靠键多，而是靠状态机区分操作语义。

---

## 阶段 3：硬件联调攻坚（耗时最长的阶段）

### 3.1 OLED 点亮马拉松（4 轮方案）

| 轮次 | 尝试 | 结果 |
|---|---|---|
| 1 | 直接套用 SSD1306 初始化序列 | 不亮（CH1115 不认 0x8D 电荷泵命令） |
| 2 | 网络教程的 CH1115 序列 | 仍不亮（方向/偏移/电荷泵参数不符） |
| 3 | GitHub 上的开源库 | 有显示但方向与偏移错误 |
| 4 | **商家官方 C51 源码** | ✅ 定位成功 |

**根因**：多处参数差异同时存在 —— 方向（`A0/C0`）、显示偏移（`D3=0x38`）、
电荷泵（`0xAD 0x8B 0x33`）、IREF（`0x82` 配置）。

> 💡 学习点：遇到「同型号屏不同批次/不同厂」时，**以厂家官方例程为准**，不要迷信网上的通用序列。

### 3.2 ADC 测不准（三阶段）

| 阶段 | 现象 | 根因 | 解决 |
|---|---|---|---|
| 1 | 电池读数恒定在满量程一半 | **VBAT 直供 MCU** → 分压与 ADC 参考同源，比例恒定 | 改用**内部 BGR 1.2V 反推 VDD** |
| 2 | LED 点亮后读数乱跳 | 双通道非同时采样，撞上 PWM 造成的电源波动 | **成对交替采样 + IIR 平滑** |
| 3 | 静态功耗偏高（~210µA） | 外部 10K/10K 分压**常通耗电** | **拆除外部电路**，改纯 BGR 反推，且 BGR 仅在测量时开启 |

> 💡 学习点：**"比例测量失效"是直供电池方案经典陷阱**—— ADC 参考跟电源同源时，
> 测出来的永远是"固定比例"。要测电源电压，必须有一个**绝对参考**（BGR/LDO 参考）。
> 同时：分压电阻是「静态耗电大户」，电池设备能省则省。

### 3.3 频闪 / 啸叫 / 功耗：PWM 频率调优史

`20kHz → 30kHz → 5kHz → 1kHz → 8kHz（定稿）`

**根因**：驱动芯片 RY3730 手册规定调光频率 **100Hz ~ 10kHz** ——
超出范围或过低都会出问题；最终以 **8kHz + 亮度下限 3%** 收尾（低占空比频闪治理）。

> 💡 学习点：**PWM 频率不是越高越好**，要读驱动芯片手册的推荐区间；
> 低亮度频闪往往不是频率单一问题，需配合**最小占空比下限**一起解决。

### 3.4 休眠唤醒反复踩坑（四个连环坑）

| 现象 | 根因 | 解决 |
|---|---|---|
| **唤不醒** | 唤醒边沿方向错（本板按键**高有效**，需上升沿） | 配置上升沿唤醒 |
| **唤醒即重启** | 唤醒恢复时序不当（3V3 未稳时按键扫描误判） | **延迟初始化 + 吞咽窗口** |
| **松手即重启** | 机械按键**释放回弹**产生瞬态边沿，被当成新的唤醒 | 等释放 + 100ms 消抖窗 + 清标志再睡 |
| **关机后开不了机** | PB03 供电随 CE 断开而消失 | 硬件改版：PB3 由 VBAT 分压常电 |

> 💡 学习点：低功耗调试的坑几乎都在**"边沿语义"和"时序"**上——
> 机械按键的回弹、电源建立所需的时间，必须显式处理（消抖窗、清标志、延迟初始化）。

### 3.5 按键误触

- 现象：安静环境正常，**PWM 一开就零星误触**；
- 根因：按键节点为**高阻**，耦合了 PWM 噪声；
- 解决：**硬件把下拉电阻改小**（降低节点阻抗）。

> 💡 学习点：软件消抖解决不了「电气层面的噪声耦合」——**该改硬件就改硬件**。

---

## 阶段 4：体验优化

- **无级调光**：长按连续调节，**三段加速**（60ms/步 → 1.1s 后 30ms/步 → 1.9s 后 12ms/步），步进 0.5%；
- **复合操作**：单击 = 一步微调；长按 ≥300ms = 连续调节；双击（≤350ms）= 切换功能
  （双击−切换调节对象 A→B→一起；双击+切换点亮模式）；
- **Flash 亮度记忆**：亮度变更 2s 后自动保存（两组独立）+ 关机时保存；
  开机时若 RTC 差值 ≤1 小时则恢复，否则默认 10%（**跨 Reset 有效，掉电自然过期**）；
- **屏幕迭代**：0.91"(128×32) → 0.96"(128×64) → 最终 **0.5" CH1115 88×48**，UI 全部重排为 6 行 × 14 字符；
- **代码瘦身**：删除所有调试显示（raw/i12/ST-EV/开机动画）。

> 💡 学习点：**体验优化阶段才是产品成型的地方**——同样的硬件，
> 交互细节（加速曲线、双击语义、记忆策略）决定用户觉得"好用"还是"凑合"。

---

## 关键踩坑速查表（可直接当排错清单用）

| 现象 | 根因 | 解决 |
|---|---|---|
| 屏幕全黑 | CH1115 不认 SSD1306 的 DC-DC 命令（0x8D）、方向/偏移错误 | 商家官方序列：`0x82` IREF + `0xAD 0x8B 0x33` + `A0/C0` + `D3 0x38` |
| 电池读数恒为 3.3V | VBAT 直供 → 分压/参考同源，比例恒定 | 内部 **BGR 反推 VDD** |
| LED 亮起后电压乱跳 | 双通道非同时采样遇 PWM 波动 | **成对交替采样 + 平滑** |
| 低亮度频闪 | 调光频率脱离 RY3730 推荐区（100Hz–10kHz） | **8kHz + 3% 下限** |
| 关机松手即重启 | 按键释放回弹瞬态被当唤醒沿 | **等释放 + 消抖窗 + 清标志** |
| 按键误触 | 高阻节点耦合 PWM 噪声 | **硬件下拉电阻改小** |
| 唤醒后花屏 | 屏幕掉电重启需完整初始化 | **唤醒延时 500×1ms 后 OLED_Init** |

---

## 从这些坑里，我们提炼出 6 条工程原则

1. **以厂家官方例程为准**（尤其外设初始化序列），网络教程只能参考；
2. **测电源要有绝对参考**（BGR/基准源），否则比例测量必然失效；
3. **频率与占空比要一起设计**（驱动手册 + 最小占空比下限）；
4. **低功耗的关键是时序**：唤醒沿、消抖窗、初始化延迟，一个都不能少；
5. **软件治不了的噪声，回硬件解决**（下拉电阻、地线、去耦）；
6. **把踩坑写下来**：同一个坑第二次踩，成本才是真正的浪费——这也是本学习包存在的原因。

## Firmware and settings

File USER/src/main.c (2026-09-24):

#include "../inc/main.h"

/*******************************************************************************
 * UserApp - CW32L010F8 应用框架
 *
 * 结构划分 (参考 H563 工程):
 *   - main.c          应用主程序: 初始化和界面刷新 (OLED 内容)
 *   - interrupts.c    BTIM1 1ms 定时中断: 周期任务调度
 *   - bsp_timer.c     BTIM1 定时器配置 (时基 1ms)
 *   - bsp_power.c     低功耗: 停机(STOP)休眠 + 按键唤醒
 *   - bsp_oled.c      OLED 显示原语 (ShowStr 等, 屏幕内容由 main.c 决定)
 *   - bsp_i2c.c       软件 I2C (OLED)
 *   - bsp_pwm.c       PWM (ATIM_CH2/CH3): 组1/组2 LED 输出
 *   - bsp_adc.c       VBAT 电压采样 (ADC_IN7)
 *   - bsp_button.c    按键扫描
 *   - bsp_detect.c    磁吸接口 LED 吸附检测 (复用 OSC+/OSC-)
 *
 * [硬件说明]
 *   - 无外部晶振: 内部高速时钟 HSI 48MHz
 *   - 4pin 磁吸接口 x2 (仅外挂款): 3V3 / GND / LED- / DET
 *     DET 检测线: 板/线侧下拉电阻, LED 端 3V3 接检测线
 *     -> 高电平 = LED 已吸附
 *   - 检测引脚: 组1 = PA01(OSC-), 组2 = PA00(OSC+)
 *
 * [软件开关 - 产品型号] 见 app_config.h (烧录前切换)
 *   外挂款: 磁吸检测启用, 按键 5 个 (PA02 PA04 PA05 PA06 PB03)
 *   内置款: 无检测, 按键 7 个 (PA00 PA01 PA02 PA04 PA05 PA06 PB03)
 *
 * [按键功能]
 *   外挂款 BTN1..BTN5 (=PA02 PA04 PA05 PA06 PB03):
 *     BTN1: 整机开关; BTN2/3: 当前组亮度-/+; BTN4: 分组切换; BTN5: 全部亮灭
 *   内置款 BTN1..BTN7 (=PA00 PA01 PA02 PA04 PA05 PA06 PB03):
 *     BTN1: 整机开关; BTN2/3: 当前组亮度-/+; BTN4: 分组切换;
 *     BTN5: 组1 亮灭; BTN6: 组2 亮灭; BTN7: 全部亮灭
 ******************************************************************************/

/* 断言上报接口: CW32 库 base_types.h 无条件开启 USE_FULL_ASSERT, 必须实现 */
#ifdef USE_FULL_ASSERT
/**
 * @brief 库函数参数校验失败时被调用 (assert_param 触发)
 * @param file 出错源文件
 * @param line 出错行号
 */
void assert_failed(uint8_t *file, uint32_t line)
{
    (void)file;
    (void)line;
    while (1);      /* 死循环等待调试 */
}
#endif /* USE_FULL_ASSERT */

/* ============================ 数据结构定义 ============================ */

/**
 * @brief 灯组状态
 * @note 组1 -> PWM1 (PB01, ATIM_CH2); 组2 -> PWM2 (PA03, ATIM_CH3)
 */
typedef struct
{
    uint8_t  on;            /* 点亮状态: 1=亮, 0=灭 */
    uint16_t brightness;    /* 亮度档位 (千分数 0..1000) */
} LEDGroup_t;

/* ============================ 应用状态变量 ============================ */
volatile uint16_t g_vbat_mv      = 0;     /* 电池电压 (mV), ISR 每50ms采样更新 */

volatile LEDGroup_t g_grp1       = {1, 500};  /* 组1: 亮, 50% 亮度 */
volatile LEDGroup_t g_grp2       = {1, 500};  /* 组2: 亮, 50% 亮度 */
volatile uint8_t    g_active_grp = 1;        /* 当前亮度调节组 (1/2) */
volatile uint8_t    g_power_on   = 1;        /* 整机开关 (LDO CE) */
volatile uint8_t    g_ui_req     = 0;        /* 界面刷新请求 (ISR置位) */
volatile uint8_t    g_sleep_req  = 0;        /* 关机: 请求进入停机休眠 */
volatile uint8_t    g_det1       = 0;        /* 组1 吸附状态缓存 (1=已连接; 内置款恒1) */
volatile uint8_t    g_det2       = 0;        /* 组2 吸附状态缓存 (1=已连接; 内置款恒1) */

/* 唤醒后 300ms 内吞掉按键事件 (避免"开机后立刻再次关机") */
static volatile uint32_t s_swallow_until = 0;

/* 周期任务调度计数 (ISR 内使用) */
static volatile uint32_t s_cnt_5ms   = 0;    /* 按键扫描 5ms 计时器 */
static volatile uint32_t s_cnt_50ms  = 0;    /* ADC 采样 50ms 计时器 */
static volatile uint32_t s_cnt_200ms = 0;    /* 界面刷新 200ms 计时器 */

/* ============================ 静态函数声明 ============================ */
static void Board_Init(void);
static void HandleKey(uint8_t evt);
static void ApplyOutputs(void);
static void UpdateDetect(void);
static void OLED_ShowVBat(uint8_t x, uint8_t y, uint16_t mv);
static void OLED_ShowPct(uint8_t x, uint8_t y, uint16_t permille);
static void OLED_ShowGroup(uint8_t x, uint8_t y, const LEDGroup_t *grp);
static void OLED_ShowDet(uint8_t x, uint8_t y, uint8_t attached);

/* ======================================================================
 * 输出刷新: 将 (整机电源 x 组点亮 x 亮度 x 吸附检测) 写入 PWM 寄存器
 * 任意状态改变后调用 (ISR/初始化均可, 仅寄存器写, 耗时极短)
 * 安全逻辑: LED 未吸附(检测为低)时该组禁止输出, 防止空载驱动
 * ==================================================================== */
static void ApplyOutputs(void)
{
    uint16_t d1, d2;

#if BSP_DETECT_ENABLED
    /* [外挂款] 组1: 需 电源 ON + 组1点亮 + 组1已吸附 */
    d1 = (g_power_on && g_grp1.on && g_det1) ? g_grp1.brightness : 0;
    /* 组2: 需 电源 ON + 组2点亮 + 组2已吸附 */
    d2 = (g_power_on && g_grp2.on && g_det2) ? g_grp2.brightness : 0;
#else
    /* [内置款] LED 内置, 无吸附检测 (g_det 恒为 1) */
    d1 = (g_power_on && g_grp1.on) ? g_grp1.brightness : 0;
    d2 = (g_power_on && g_grp2.on) ? g_grp2.brightness : 0;
#endif

    BSP_PWM_SetDuty(PWM_CH1, d1);       /* 组1 (PB01) */
    BSP_PWM_SetDuty(PWM_CH2, d2);       /* 组2 (PA03) */
}

/**
 * @brief 吸附检测更新: 读取检测状态, 变化时联动 PWM 输出
 * @note 由 App_Task1ms 的 5ms 节拍调用 (去抖在 bsp_detect.c)
 */
static void UpdateDetect(void)
{
#if BSP_DETECT_ENABLED
    uint8_t d1 = BSP_DETECT_IsAttached(0);      /* 组1 吸附状态 */
    uint8_t d2 = BSP_DETECT_IsAttached(1);      /* 组2 吸附状态 */

    if ((d1 != g_det1) || (d2 != g_det2))       /* 吸附/脱落事件 */
    {
        g_det1 = d1;
        g_det2 = d2;
        ApplyOutputs();                         /* 联动输出 (脱落即灭) */
        g_ui_req = 1;                           /* 刷新界面显示 */
    }
#else
    /* [内置款] 视为一直吸附 */
    g_det1 = 1;
    g_det2 = 1;
#endif
}

/* ======================================================================
 * 周期任务 (由 BTIM1 1ms 中断调用, 见 interrupts_cw32l010.c)
 *
 * 本函数内按分频计划调度各周期任务, "大部分工作"在中断中完成,
 * 主循环只做最慢的 OLED 刷屏 (刷新需要数 ms, 不适合放 ISR):
 *   - 5ms : 按键扫描 + 吸附检测 (去抖后联动输出)
 *   - 50ms: VBAT 电压采样 (ADC 均值)
 *   - 200ms: 请求界面数值刷新
 * ==================================================================== */
void App_Task1ms(void)
{
    uint8_t evt;

    g_ms_tick++;                        /* 系统毫秒时基 (bsp_timer.h 声明) */

    /* ---------- 5ms: 按键扫描 + 吸附检测 ---------- */
    if (++s_cnt_5ms >= 5)
    {
        s_cnt_5ms = 0;

        evt = BSP_BTNs_Scan();          /* 按键去抖扫描 (15ms 稳定) */
        if (evt)
            HandleKey(evt);             /* 按键功能 (开关机/亮度/分组) */

#if BSP_DETECT_ENABLED
        BSP_DETECT_Task();              /* [外挂款] 吸附检测采样 (100ms 去抖) */
        UpdateDetect();                 /* 状态联动 (脱落 -> 灭) */
#endif
    }

    /* ---------- 50ms: ADC 电压采样 ---------- */
    if (++s_cnt_50ms >= 50)
    {
        s_cnt_50ms = 0;
        g_vbat_mv = BSP_ADC_ReadVbatMv();
    }

    /* ---------- 200ms: 界面刷新请求 ---------- */
    if (++s_cnt_200ms >= 200)
    {
        s_cnt_200ms = 0;
        g_ui_req = 1;                   /* 主循环检测到后执行 UI_RefreshValues() */
    }
}

/* ======================================================================
 * 按键功能处理 (从 ISR 调用)
 *
 * BTN1: 开关机 (整机电源 = LDO CE + 停机休眠)
 * BTN2/BTN3: 当前组亮度 -10% / +10%
 * BTN4: 分组切换 (组1 <-> 组2)
 * BTN5: 全部 点亮/熄灭
 * ==================================================================== */
static void HandleKey(uint8_t evt)
{
    uint8_t  g;         /* 当前调节组索引 (0=组1, 1=组2) */
    uint16_t br;

    /* ---- 唤醒保护: 停机恢复后短时间内吞掉当前按键按下事件,
     *      避免"唤醒后立刻再次触关机/误操作"---- */
    if (g_ms_tick < s_swallow_until)
    {
        return;
    }

    /* ---- BTN1: 整机开关机 (LDO CE + 进入/退出停机休眠) ---- */
    if (evt & BTN1_MASK)
    {
        g_power_on = !g_power_on;
        if (g_power_on)
        {
            LDO_CE_Enable();                    /* CE 拉高, LDO 上电 */
            ApplyOutputs();
        }
        else
        {
            LDO_CE_Disable();                   /* CE 拉低, LDO 断电 */
            ApplyOutputs();                     /* PWM 输出归零 */
            OLED_OFF();                         /* 关屏 */
            g_sleep_req = 1;                    /* 主循环进入 STOP 休眠 */
        }
    }

    /* ---- BTN2/BTN3: 亮度-/+ (作用于当前组) ---- */
    if (evt & (BTN2_MASK | BTN3_MASK))
    {
        g  = (g_active_grp == 1) ? 0 : 1;   /* 映射组索引 */
        br = (g == 0) ? g_grp1.brightness : g_grp2.brightness;

        if (evt & BTN2_MASK)                /* 亮度- */
            br = (br >= 100) ? (br - 100) : 100;    /* 下限 10% (保持可调) */
        if (evt & BTN3_MASK)                /* 亮度+ */
            br = (br <= 900) ? (br + 100) : 1000;   /* 上限 100% */

        if (g == 0) g_grp1.brightness = br;
        else        g_grp2.brightness = br;
        g_ui_req = 1;
        ApplyOutputs();
    }

    /* ---- BTN4: 分组切换 (当前亮度调节的组) ---- */
    if (evt & BTN4_MASK)
    {
        g_active_grp = (g_active_grp == 1) ? 2 : 1;
    }

    /* ---- BTN5: 全部 点亮/熄灭 (同步两组 ----
     * 外挂款: BTN5 即"全部"; 内置款: BTN5/6 单独控制组1/组2, BTN7 全部 */
    if (evt & BTN5_MASK)
    {
#if BSP_DETECT_ENABLED
        g_grp1.on = !g_grp1.on;
        g_grp2.on = !g_grp2.on;
#else
        g_grp1.on = !g_grp1.on;
#endif
        ApplyOutputs();
    }
#if !BSP_DETECT_ENABLED
    if (evt & BTN6_MASK)                /* 内置款: 组2 单独亮灭 */
    {
        g_grp2.on = !g_grp2.on;
        ApplyOutputs();
    }
    if (evt & BTN7_MASK)                /* 内置款: 全部亮灭 */
    {
        g_grp1.on = !g_grp1.on;
        g_grp2.on = !g_grp2.on;
        ApplyOutputs();
    }
#endif
}

/* ======================================================================
 * 格式化辅助
 * ==================================================================== */

/**
 * @brief 显示电压值 格式 "xx.xxV"
 * @param x 起始列 0..127
 * @param y 起始页 0..7
 * @param mv 电压 (mV)
 */
static void OLED_ShowVBat(uint8_t x, uint8_t y, uint16_t mv)
{
    uint8_t b[8];
    uint8_t ip = (uint8_t)(mv / 1000);              /* 整数部分 */
    uint8_t fp = (uint8_t)((mv % 1000) / 10);       /* 小数部分(2位) */

    b[0] = (uint8_t)('0' + ip / 10 % 10);           /* 十位 */
    b[1] = (uint8_t)('0' + ip % 10);                /* 个位 */
    b[2] = '.';
    b[3] = (uint8_t)('0' + fp / 10);                /* 0.1V 位 */
    b[4] = (uint8_t)('0' + fp % 10);                /* 0.01V 位 */
    b[5] = 'V';
    b[6] = '\0';
    OLED_ShowStr(x, y, b, 1);
}

/**
 * @brief 显示占空比 格式 "xx%"
 * @param x 起始列 0..127
 * @param y 起始页 0..7
 * @param permille 千分数 0..1000
 */
static void OLED_ShowPct(uint8_t x, uint8_t y, uint16_t permille)
{
    uint8_t b[4];
    uint8_t p = (uint8_t)(permille / 10);           /* 千分 -> 百分 */

    b[0] = (uint8_t)('0' + p / 10 % 10);            /* 十位 */
    b[1] = (uint8_t)('0' + p % 10);                 /* 个位 */
    b[2] = '%';
    b[3] = '\0';
    OLED_ShowStr(x, y, b, 1);
}

/**
 * @brief 显示一组灯的状态 格式 "ON xx%"/"OFF"
 * @param x 起始列
 * @param y 起始页
 * @param grp 灯组状态指针
 */
static void OLED_ShowGroup(uint8_t x, uint8_t y, const LEDGroup_t *grp)
{
    if (grp->on)
        OLED_ShowPct(x, y, grp->brightness);
    else
        OLED_ShowStr(x, y, (uint8_t *)"OFF", 1);
}

/**
 * @brief 显示吸附检测状态 格式 "OK"/"NO"
 * @param x 起始列
 * @param y 起始页
 * @param attached 1=已吸附(高电平), 0=未吸附
 */
static void OLED_ShowDet(uint8_t x, uint8_t y, uint8_t attached)
{
    OLED_ShowStr(x, y, (uint8_t *)(attached ? "OK" : "NO"), 1);
}

/* ======================================================================
 * 界面层 (main.c 内, 内容布局参考 H563 的 OLED_Scan 函数风格)
 * ==================================================================== */

/**
 * @brief 画静态标签 (上电后调用一次)
 * 屏幕布局 (每行 6x8 字体, 21 字符):
 *   Row0: VBAT: xx.xxV   电池电压
 *   Row1: G1(PB1): nn%   组1 (磁吸接口1) 亮度
 *   Row2: G2(PA3): nn%   组2 (磁吸接口2) 亮度
 *   Row3: PWR:ON  CUR:1   整机电源 / 当前调节组
 *   Row4: DET1:OK DET2:NO 磁吸吸附检测 (高=已连接)
 *   Row5~7: 按键提示
 */
void UI_StaticInit(void)
{
    OLED_CLS();

    /* 数据区标签 */
    OLED_ShowStr(0, 0, (uint8_t *)"VBAT:", 1);
    OLED_ShowStr(0, 1, (uint8_t *)"G1(PB1):", 1);
    OLED_ShowStr(0, 2, (uint8_t *)"G2(PA3):", 1);
    OLED_ShowStr(0, 3, (uint8_t *)"PWR:", 1);
    OLED_ShowStr(60, 3, (uint8_t *)"CUR:", 1);

#if BSP_DETECT_ENABLED
    /* [外挂款] 吸附检测标签 */
    OLED_ShowStr(0, 4, (uint8_t *)"DET1:", 1);
    OLED_ShowStr(60, 4, (uint8_t *)"DET2:", 1);

    /* 按键提示 */
    OLED_ShowStr(0, 5, (uint8_t *)"1:PWR 2/3:BRT-/+", 1);
    OLED_ShowStr(0, 6, (uint8_t *)"4:GRP 5:ALL", 1);
    OLED_ShowStr(0, 7, (uint8_t *)"DET:Hi=LINK", 1);
#else
    /* [内置款] 显示型号标识 */
    OLED_ShowStr(0, 4, (uint8_t *)"BUILT-IN", 1);

    /* 按键提示 (7 键) */
    OLED_ShowStr(0, 5, (uint8_t *)"1:PWR 2/3:BRT-/+", 1);
    OLED_ShowStr(0, 6, (uint8_t *)"4:GRP 5:G1 6:G2", 1);
    OLED_ShowStr(0, 7, (uint8_t *)"7:ALL", 1);
#endif

    /* 画一遍动态数值, 避免首屏空白 */
    UI_RefreshValues();
}

/**
 * @brief 刷新数值区 (由主循环在 g_ui_req 置位时调用, 200ms 一次)
 * 只更新数值区域, 避免整屏重刷, 与 H563 OLED_Scan 思路一致
 */
void UI_RefreshValues(void)
{
    OLED_ShowVBat(30, 0, g_vbat_mv);                    /* Row0: 电压 */

    OLED_ShowGroup(60, 1, (const LEDGroup_t *)&g_grp1); /* Row1: 组1 亮度/OFF */
    OLED_ShowGroup(60, 2, (const LEDGroup_t *)&g_grp2); /* Row2: 组2 亮度/OFF */

    OLED_ShowStr(24, 3, (uint8_t *)(g_power_on ? "ON  " : "OFF "), 1);    /* PWR */
    OLED_ShowStr(84, 3, (uint8_t *)(g_active_grp == 1 ? "1  " : "2  "), 1); /* CUR */

#if BSP_DETECT_ENABLED
    OLED_ShowDet(30, 4, g_det1);                        /* Row4: 组1 吸附检测 */
    OLED_ShowDet(90, 4, g_det2);                        /* Row4: 组2 吸附检测 */
#endif
}

/* ======================================================================
 * 初始化
 * ==================================================================== */

/**
 * @brief 板上外设初始化
 */
static void Board_Init(void)
{
    GPIO_InitTypeDef gpio = {0};

    /* ---- 时钟: 内部高速时钟 HSI 48MHz (PCLK = 48MHz, 无外部晶振) ---- */
    SYSCTRL_HSI_Enable(SYSCTRL_HSIOSC_DIV1);
    __SYSCTRL_GPIOA_CLK_ENABLE();
    __SYSCTRL_GPIOB_CLK_ENABLE();

    /* ---- CE: LDO 使能 (PB04, 上电默认使能) ---- */
    gpio.IT   = GPIO_IT_NONE;
    gpio.Mode = GPIO_MODE_OUTPUT_PP;
    gpio.Pins = CE_GPIO_PINS;
    GPIO_Init((GPIO_TypeDef *)CE_GPIO_PORT, &gpio);
    LDO_CE_Enable();
    g_power_on = 1;

    /* ---- 外设 ---- */
    I2C_GPIO_Init();                    /* 软件 I2C (OLED) */
    BSP_PWM_Init();                     /* PWM1/2 (组1/组2 LED) */
    BSP_ADC_Init();                     /* VBAT 采样 */
    BSP_BTNs_Init();                    /* 按键 */
#if BSP_DETECT_ENABLED
    BSP_DETECT_Init();                  /* [外挂款] 磁吸吸附检测 (OSC+/OSC-) */
#endif

    /* ---- OLED ---- */
    OLED_Init();

    /* ---- 定时器: BTIM1 1ms 时基 + 中断 ---- */
    __disable_irq();
    BSP_TIMER_Init();
    NVIC_SetPriority(BTIM1_IRQn, 1);    /* 优先级高于主循环, 低于系统调用 */
    NVIC_EnableIRQ(BTIM1_IRQn);
    __enable_irq();

    /* ---- 按当前状态输出 PWM (组默认亮, 50%; 外挂款未吸附的组不输出) ---- */
#if BSP_DETECT_ENABLED
    g_det1 = BSP_DETECT_IsAttached(0);  /* 读取初始吸附状态 */
    g_det2 = BSP_DETECT_IsAttached(1);
#else
    g_det1 = 1;                         /* 内置款: 视为已连接 */
    g_det2 = 1;
#endif
    ApplyOutputs();
}

/* ======================================================================
 * 主循环
 * ==================================================================== */

int main(void)
{
    Board_Init();                       /* 板上初始化 */

    UI_StaticInit();                    /* 画静态界面 */

    while (1)
    {
        /* ---------- 关机: 进入停机模式 (STOP) 休眠 ----------
         * 流程: 已关 LDO + PWM 归零 + 关屏, 此处进入低功耗;
         *       任意按键按下 -> GPIO 下降沿中断唤醒 -> WFI 返回后继续执行 */
        if (g_sleep_req)
        {
            g_sleep_req = 0;

            BSP_POWER_EnterStop();          /* 休眠, 唤醒后返回 */

            /* ============ 唤醒恢复 (按键按下) ============ */
            BSP_POWER_WakeupInit();         /* 恢复时钟/外设/按键扫描 */
#if BSP_DETECT_ENABLED
            BSP_DETECT_Init();              /* [外挂款] 重新初始化吸附检测 */
#endif

            s_swallow_until = g_ms_tick + 300;  /* 300ms 内吞掉唤醒按键事件 */
            g_power_on = 1;
            LDO_CE_Enable();                /* CE 拉高, LDO 上电 */
            OLED_ON();                      /* 开屏 */
            UpdateDetect();                 /* 刷新吸附状态并联动输出 */
            g_ui_req = 1;                   /* 刷一次界面 */
        }

        /* ---------- 界面刷新 (200ms 由 ISR 请求) ----------
         * OLED 写入耗时较长, 放主循环中执行, 避免阻塞 1ms 时基中断 */
        if (g_ui_req)
        {
            g_ui_req = 0;
            UI_RefreshValues();
        }
    }
}

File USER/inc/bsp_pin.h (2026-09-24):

#ifndef __BSP_PIN_H
#define __BSP_PIN_H

#include "cw32l010.h"
#include "cw32l010_gpio.h"
#include "app_config.h"

/*******************************************************************************
 * 开发板引脚分配 (原理图, MCU: CW32L010F8, TSSOP20)
 *
 *  引脚号   MCU引脚        功能
 *  -----------------------------------------------
 *    1    PB04  (CE)   LDO 使能 (GPIO 输出)
 *    2    PB05  (SDA)  OLED IIC SDA (软件IIC)
 *    3    PB06  (SCK)  OLED IIC SCL (软件IIC; 丝印SCK)
 *    4    PB07/NRST    系统复位/OLED RST (不再作按钮)
 *    5    PA00 (OSC+)  磁吸接口组2 吸附检测 (高=已连接)
 *    6    PA01 (OSC-)  磁吸接口组1 吸附检测 (高=已连接)
 *   10    PA02         按键 BTN1 (内部上拉, 按下低有效)
 *   14    PA04         按键 BTN2
 *   15    PA05         按键 BTN3
 *   16    PA06         按键 BTN4
 *   11    PB00 (VBAT)  电池电压采样 (ADC_IN7)
 *   12    PB01 (PB1)   PWM1 输出 (ATIM_CH2) -> LED组1
 *   13    PA03 (PA3)   PWM2 输出 (ATIM_CH3) -> LED组2
 *   20    PB03         按键 BTN5
 *   19    PB02         未引出 (原理图 X)
 *   17/18 PA08/PA07    SWCLK/SWDIO 调试口
 *
 * 磁吸接口 (4pin, 每灯组一个):
 *   1) 3V3  板侧输出 3.3V 供 LED 端
 *   2) GND  地
 *   3) LED- LED 灯条负极 (由 PWM 低边开关驱动)
 *   4) DET  检测线: LED 端 3V3 接到检测线 -> 吸附后 3.3V 拉高
 *   板侧: DET 经下拉电阻到地 (未吸附=低), MCU 检测线输入高电平 = 已吸附
 *   注意: 未用外部晶振, OSC+/OSC- (PA00/PA01) 复用为检测端口
 ******************************************************************************/

/* ============================ LDO 使能 CE (PB04) ============================ */
#define CE_GPIO_PORT         CW_GPIOB
#define CE_GPIO_PINS         GPIO_PIN_4
#define CE_ACTIVE_LEVEL      1       /* 1 = 高电平使能 LDO; 0 = 低电平使能 */

#define LDO_CE_Enable()      (CE_ACTIVE_LEVEL ? (CE_GPIO_PORT->BSRR = CE_GPIO_PINS) \
                                              : (CE_GPIO_PORT->BRR  = CE_GPIO_PINS))
#define LDO_CE_Disable()     (CE_ACTIVE_LEVEL ? (CE_GPIO_PORT->BRR  = CE_GPIO_PINS) \
                                              : (CE_GPIO_PORT->BSRR = CE_GPIO_PINS))
#define LDO_CE_GetState()    ((CE_GPIO_PORT->IDR & CE_GPIO_PINS) != 0)

/* ============================ OLED IIC (PB05/PB06) =========================== */
#define OLED_SCL_PORT        CW_GPIOB
#define OLED_SCL_PIN         GPIO_PIN_6
#define OLED_SDA_PORT        CW_GPIOB
#define OLED_SDA_PIN         GPIO_PIN_5

/* ============================= 电压采样 VBAT (PB00) =========================== */
#define VBAT_GPIO_PORT       CW_GPIOB
#define VBAT_GPIO_PINS       GPIO_PIN_0
#define VBAT_ADC_CHANNEL     ADC_InputCH7   /* PB00 = ADC_IN7 */

/* ============================== PWM 输出 (ATIM) =============================== */
/* PWM1: PB01 (引脚12) -> ATIM_CH2 -> LED组1;  PWM2: PA03 (引脚13) -> ATIM_CH3 -> LED组2 */
#define PWM1_GPIO_PORT       CW_GPIOB
#define PWM1_GPIO_PINS       GPIO_PIN_1
#define PWM2_GPIO_PORT       CW_GPIOA
#define PWM2_GPIO_PINS       GPIO_PIN_3

/* ==================== 磁吸接口 LED 吸附检测 (复用 OSC 引脚) ==================== */
/* 高电平 = LED 已吸附 (要求板侧/灯端有下拉电阻, 灯端 3V3 接检测线)
 * 仅外挂款启用; 内置款时 PA00/PA01 作普通按键 */
#if BSP_DETECT_ENABLED
#define DET1_GPIO_PORT       CW_GPIOA
#define DET1_GPIO_PINS       GPIO_PIN_1           /* OSC- : LED组1 (PWM1/PB01) 吸附检测 */
#define DET2_GPIO_PORT       CW_GPIOA
#define DET2_GPIO_PINS       GPIO_PIN_0           /* OSC+ : LED组2 (PWM2/PA03) 吸附检测 */
#endif

/* =============================== 按键 (按下为低) =============================== */
/* 按键数量由产品型号决定 (见 app_config.h):
 *   外挂款: 5 个 (PA02 PA04 PA05 PA06 PB03, PA00/PA01 被检测占用)
 *   内置款: 7 个 (PA00 PA01 PA02 PA04 PA05 PA06 PB03) */
#if BSP_DETECT_ENABLED
#define BTN_MAX_NUM          5
static const GPIO_TypeDef *const BTN_PORT[BTN_MAX_NUM] = { CW_GPIOA, CW_GPIOA, CW_GPIOA,
                                                           CW_GPIOA, CW_GPIOB };
static const uint16_t BTN_PIN[BTN_MAX_NUM] = { GPIO_PIN_2, GPIO_PIN_4, GPIO_PIN_5,
                                               GPIO_PIN_6, GPIO_PIN_3 };
#else
#define BTN_MAX_NUM          7
static const GPIO_TypeDef *const BTN_PORT[BTN_MAX_NUM] = { CW_GPIOA, CW_GPIOA, CW_GPIOA,
                                                           CW_GPIOA, CW_GPIOA, CW_GPIOA,
                                                           CW_GPIOB };
static const uint16_t BTN_PIN[BTN_MAX_NUM] = { GPIO_PIN_0, GPIO_PIN_1, GPIO_PIN_2,
                                               GPIO_PIN_4, GPIO_PIN_5, GPIO_PIN_6,
                                               GPIO_PIN_3 };
#endif

#endif /* __BSP_PIN_H */

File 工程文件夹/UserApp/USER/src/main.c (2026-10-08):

#include "../inc/main.h"

/*******************************************************************************
 * UserApp - CW32L010F8 应用框架 (0.91" 128x32 OLED)
 *
 * 结构划分 (参考 H563 工程):
 *   - main.c          应用主程序: 初始化和界面刷新 (OLED 内容)
 *   - interrupts.c    BTIM1 1ms 定时中断: 周期任务调度
 *   - bsp_timer.c     BTIM1 定时器配置 (时基 1ms)
 *   - bsp_power.c     低功耗: 停机(STOP)休眠 + 按键唤醒
 *   - bsp_oled.c      OLED 显示原语 (6x8 ShowStr, 屏幕内容由 main.c 决定)
 *   - bsp_i2c.c       软件 I2C (OLED)
 *   - bsp_pwm.c       PWM (ATIM_CH2/CH3): 组1/组2 LED 输出
 *   - bsp_adc.c       VBAT 电压采样 (ADC_IN7, 10K/10K 分压)
 *   - bsp_button.c    按键扫描
 *   - bsp_detect.c    磁吸接口 LED 吸附检测 (复用 OSC+/OSC-)
 *
 * [硬件说明]
 *   - 无外部晶振: 内部高速时钟 HSI 48MHz
 *   - 0.91" OLED: SSD1306 128x32 (4 页, 每页 6x8 字体)
 *   - 4pin 磁吸接口 x2 (仅外挂款): 3V3 / GND / LED- / DET
 *     DET 检测线: 板侧/线侧下拉电阻, LED 端 3V3 接检测线
 *     -> 高电平 = LED 已吸附; 组1 = PA01(OSC-), 组2 = PA00(OSC+)
 *
 * [软件开关 - 产品型号] 见 app_config.h (烧录前切换)
 *   外挂款: 磁吸检测启用, 按键 5 个 (PA02 PA04 PA05 PA06 PB03)
 *   内置款: 无检测, 按键 7 个 (PA00 PA01 PA02 PA04 PA05 PA06 PB03)
 *
 * [按键功能] 仅 3 个按键:
 *   BTN1 (PB03): 开关机
 *   BTN2 (PA04): 亮度- (两组同步)
 *   BTN3 (PA05): 亮度+ (两组同步)
 *   电池非正常(LOW/PROTECT)时: BTN1 仍为开关机, 其余键切换告警页开关
 *   按键有效电平: 见 bsp_pin.h 的 BTN_ACTIVE_LEVEL (当前=按下为高)
 ******************************************************************************/

/* 断言上报接口: CW32 库 base_types.h 无条件开启 USE_FULL_ASSERT, 必须实现 */
#ifdef USE_FULL_ASSERT
/**
 * @brief 库函数参数校验失败时被调用 (assert_param 触发)
 * @param file 出错源文件
 * @param line 出错行号
 */
void assert_failed(uint8_t *file, uint32_t line)
{
    (void)file;
    (void)line;
    while (1);      /* 死循环等待调试 */
}
#endif /* USE_FULL_ASSERT */

/* ============================ 数据结构定义 ============================ */

/**
 * @brief 灯组状态
 * @note 组1 -> PWM1 (PB01, ATIM_CH2); 组2 -> PWM2 (PA03, ATIM_CH3)
 */
typedef struct
{
    uint8_t  on;            /* 点亮状态: 1=亮, 0=灭 */
    uint16_t brightness;    /* 亮度档位 (千分数 0..1000) */
} LEDGroup_t;

/* ============================ 电池保护阈值 ============================ */
#define BAT_LOW_MV         3350U   /* 电压 < 3350mV: 电量低提醒 (提高电池容量使用度) */
#define BAT_WARN_RECOVER_MV 3400U  /* 回升到 3400mV: 解除低电提醒 (滞回 +50mV) */
#define BAT_CUT_MV         3200U   /* 电压 < 3200mV: 过放保护, 关断输出 */
#define BAT_CUT_RECOVER_MV 3350U   /* 回升到 3350mV: 恢复输出 (滞回 +150mV) */
#define BAT_CHK_HOLD       40      /* 状态切换需连续 40 次采样 (50ms x 40 = 2s) */

/* 电池状态机 */
#define BAT_STATE_OK       0       /* 正常 */
#define BAT_STATE_LOW      1       /* 低电量 (3.5V~3.2V): 提醒 */
#define BAT_STATE_PROTECT  2       /* 过放保护 (<3.2V): 输出关断 */

/* 无级调光参数 (按住亮度键连续平滑调节) */
#define DIM_STEP            5U      /* 每步变化 5‰ (0.5%) */
/* 长按加速手感 (三段): 起步慢速精细 -> 按住一会转中速 -> 再转快速 */
#define DIM_SPD1_INT        60U     /* 初期:   每 60ms 一步 (精细) */
#define DIM_SPD2_AT         1100U   /* 按下后 1.1s: 进入中速 */
#define DIM_SPD2_INT        30U     /* 中速:   每 30ms 一步 */
#define DIM_SPD3_AT         1900U   /* 按下后 1.9s: 进入快速 */
#define DIM_SPD3_INT        12U     /* 快速:   每 12ms 一步 */
#define DIM_MIN_PERMILLE    0U      /* 可调下限: 已开放到 0 (0=熄灭);
                                     * 若低占空比频闪可改回 30 (3%) 实现下限钳位 */
#define DIM_LONG_MS         300U    /* 长按判定: 超过则进入连续调节 */
#define DIM_DBL_MS          350U    /* 双击间隔窗口 */

/* 告警页显示策略 (省电: 告警屏耗电较大) */
#define ALERT_AUTO_CLOSE_MS 60000U /* 告警页无操作 1 分钟自动关屏 */

/* ============================ 应用状态变量 ============================ */
volatile uint16_t g_vbat_mv       = 0;     /* 电池电压 (mV), ISR 每50ms采样更新 */

volatile LEDGroup_t g_grp1        = {1, 100};   /* 组1: 亮, 10% 亮度 (开机防太亮) */
volatile LEDGroup_t g_grp2        = {1, 100};   /* 组2: 亮, 10% 亮度 (开机防太亮) */
volatile uint8_t    g_power_on    = 1;          /* 整机开关 (LDO CE) */
volatile uint8_t    g_ui_req      = 0;          /* 界面刷新请求 (ISR置位, 主循环清零) */
volatile uint8_t    g_sleep_req   = 0;          /* 关机: 请求进入停机休眠 (主循环执行) */
volatile uint8_t    g_det1        = 0;          /* 组1 吸附状态缓存 (1=已连接) */
volatile uint8_t    g_det2        = 0;          /* 组2 吸附状态缓存 (1=已连接; 内置款恒1) */

/* 双击 BTN2 切换: 亮度调节对象  0=A串(组1) 1=B串(组2) 2=一起 */
static volatile uint8_t s_dim_target = 2U;
/* 双击 BTN3 切换: 点亮模式      0=只A亮 1=只B亮 2=一起亮 */
static volatile uint8_t s_light_mode = 2U;

volatile uint8_t    g_bat_state   = BAT_STATE_OK;  /* 电池状态机 (0=OK 1=LOW 2=PROTECT) */
volatile uint8_t    g_ui_redraw   = 0;        /* 整屏重绘请求 (状态页切换) */
static volatile uint16_t s_bat_cnt = 0;       /* 状态切换连续采样计数 */

/* 告警页/显示控制 (省电) */
volatile uint8_t    g_alert_view  = 0;        /* 1=告警页显示中, 0=已关屏 */
volatile uint32_t   g_alert_timer = 0;        /* 告警页无操作倒计时 (ms) */
volatile uint8_t    g_disp_on     = 1;        /* 物理显示开关状态 */
volatile uint8_t    g_disp_change = 0;        /* 显示开关变更请求 (主循环执行) */

/* 唤醒后 300ms 内吞掉按键事件 (避免"开机后立刻再次关机") */
static volatile uint32_t s_swallow_until = 0;

/* 亮度变更 -> 延时自动保存 (解决"直接按 Reset 不经过关机流程"的丢失问题) */
static volatile uint8_t  s_save_dirty = 0;   /* 1=亮度有变更待保存 */
static volatile uint32_t s_save_tick  = 0;   /* 最后一次变更的时刻 */
#define SAVE_DELAY_MS   2000U                /* 变更后 2s 无操作即写入 Flash */

/* 唤醒后延时屏幕恢复: 经过指定数量的 1ms 中断后再初始化/刷屏
 * (关机期间 OLED 掉电, 需等供电稳定; 避免唤醒瞬间刷屏产生随机亮点) */
static volatile uint32_t s_wake_resume_at = 0;   /* 0=无待处理; 非0=恢复时刻(g_ms_tick) */
#define WAKE_RESUME_TICKS   500U                 /* 500 个 1ms 中断后恢复屏幕 */

/* 周期任务调度计数 (ISR 内使用) */
static volatile uint32_t s_cnt_5ms   = 0;     /* 按键扫描 5ms 计时器 */
static volatile uint32_t s_cnt_50ms  = 0;     /* ADC 采样 50ms 计时器 */
static volatile uint32_t s_cnt_200ms = 0;     /* 界面刷新 200ms 计时器 */

/* ============================ 静态函数声明 ============================ */
static void Board_Init(void);
static void HandleKey(uint8_t evt);
static void ApplyOutputs(void);
static void UpdateDetect(void);
static void Battery_Check(void);

/* ======================================================================
 * 输出刷新: 将 (整机电源 x 组点亮 x 亮度 x 吸附检测 x 未过放) 写入 PWM
 * 任意状态改变后调用 (ISR/初始化均可, 仅寄存器写, 耗时极短)
 * ==================================================================== */
static void ApplyOutputs(void)
{
    uint16_t d1, d2;
    uint8_t  ok = (g_bat_state != BAT_STATE_PROTECT);   /* 过放保护时禁止输出 */

#if BSP_DETECT_ENABLED
    /* [外挂款] 组输出需同时满足: 未过放 + 电源ON + 组点亮 + 已吸附 */
    d1 = (ok && g_power_on && g_grp1.on && g_det1) ? g_grp1.brightness : 0;
    d2 = (ok && g_power_on && g_grp2.on && g_det2) ? g_grp2.brightness : 0;
#else
    /* [内置款] 无吸附检测 (g_det 恒为 1) */
    d1 = (ok && g_power_on && g_grp1.on) ? g_grp1.brightness : 0;
    d2 = (ok && g_power_on && g_grp2.on) ? g_grp2.brightness : 0;
#endif

    BSP_PWM_SetDuty(PWM_CH1, d1);       /* 组1 (PB01) */
    BSP_PWM_SetDuty(PWM_CH2, d2);       /* 组2 (PA03) */
}

/* ======================================================================
 * BTN2/BTN3 多功能调光辅助 (单击微调 / 长按连续 / 双击切换)
 * ==================================================================== */
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

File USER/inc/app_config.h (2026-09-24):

#ifndef __APP_CONFIG_H
#define __APP_CONFIG_H

/*******************************************************************************
 * APP_CONFIG - 产品型号配置 (软件开关)
 *
 * [外挂款 PRODUCT_VARIANT_EXTERNAL]
 *   LED 为磁吸 4pin 外挂 (3V3/GND/LED-/DET), 使用吸附检测:
 *   PA01(OSC-) 检测组1, PA00(OSC+) 检测组2; 高电平=已吸附, 未吸附不输出
 *   按键: 5 个 (PA02 PA04 PA05 PA06 PB03)
 *
 * [内置款 PRODUCT_VARIANT_BUILTIN]
 *   LED 内置于整机, 无需检测: PA00/PA01 复位为普通按键
 *   按键: 7 个 (PA00 PA01 PA02 PA04 PA05 PA06 PB03)
 *
 * 烧录方法: 修改下方 APP_PRODUCT_VARIANT, 重新编译烧录即可
 ******************************************************************************/

#define PRODUCT_VARIANT_EXTERNAL     0   /* 外挂款: 磁吸外接 LED + 吸附检测 */
#define PRODUCT_VARIANT_BUILTIN      1   /* 内置款: 内置 LED, 无需检测 */

/* <------- 烧录前修改这里 -------> */
#define APP_PRODUCT_VARIANT          PRODUCT_VARIANT_EXTERNAL
/* <--------------------------------> */

#if (APP_PRODUCT_VARIANT == PRODUCT_VARIANT_EXTERNAL)
#define BSP_DETECT_ENABLED           1   /* 启用磁吸吸附检测 (占用 PA00/PA01) */
#else
#define BSP_DETECT_ENABLED           0   /* 关闭检测 (PA00/PA01 作按键) */
#endif

#endif /* __APP_CONFIG_H */

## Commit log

2026-09-24 创客训练营: CW32L010 磁吸LED灯控项目 (UserApp固件/3D模型/PCB文档等)
    [3D_OLED.step, BOM_TYPE-A_PCB2_2026-08-23.xlsx, 外壳.SLDPRT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]
2026-10-04 docs: 开源学习包上线（README + 7 篇学习文档 + 系统框图 + 共建指南）
    - README.md：学习包定位（项目式学习 vs 传统开发板/Arduino）、快速开始、硬核参数、学习路径、共建入口
    - docs/01 为什么做这个学习包（开发板与 Arduino 差距的启发：项目式学习 + 低成本复现）
    - docs/02 学习路径（8 模块：目标/材料/动手/检查点，16-24 学时）
    - docs/03 硬件设计说明（四域分区、电源链路、完整引脚表、磁吸 4pin 与检测原理、BOM 与成本、设计决策问答）
    - docs/04 固件架构说明（BSP 分层、按键功能、PWM 2400 级推导、检测去抖、STOP 低功耗、ADC、双型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
2026-10-08 sync: 同步最终硬件版本 + 新增开发踩坑实录 + 演示资源
    工程（工程文件夹/）：
    - 最终硬件配置落地：LED 驱动改 RY3730×2（pin-to-pin 替代 SY7200）、PWM 8kHz/ARR=5999/6000 级、
    显示屏改 0.5" CH1115 88×48、按键收敛为 3 键（PB03/PA04/PA05，高有效）、
    电池采样改内部 BGR 1.2V 反推（拆除 10K/10K 分压，省 ~210µA）、磁吸检测去抖改 100ms
    - 新增 bsp_save（Flash 亮度记忆 + RTC 1h 恢复窗口）
    - 新增 3D 外壳/按键帽.SLDPRT；新增 UserApp/DEVELOPMENT_SUMMARY.md（最终配置与开发历程）
    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
    [外壳.SLDPRT, 按键帽.SLDPRT, 盖子.SLDPRT]
2026-10-08 feat(demo): 新增面向创客竞赛老师的汇报 PPT（16 页美化版）+ 3 张信息图
    定位重构：核心叙事从「介绍学习包」改为「不是一台灯，而是一套可复制的创业逻辑与盈利链条」；
    面向创客竞赛的老师，突出创客训练的效果（全部数据取自结题报告 V2.0 / 资源优化方案书，可核验，含团队自我纠错数据）。
    内容（16 页）：摘要与 5 KPI → 训练效果量化（中期 vs 结题、能力等级、9 处自纠错） → 核心观点（三件可复制资产）
    → 创业逻辑四步闭环 → 洞察（126 份问卷/60 人观察） → 验证（1 元意向金 37.3%） → 渠道决策（先算 CAC 再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
2026-10-08 feat(poster): 新增项目海报（A4 300dpi，PNG + PDF）
    - 叙事与汇报 PPT 一致：不是一台灯，而是一套可复制的创业逻辑与盈利链条
    - 内容：顶带主张 / 产品照片位（占位待替换）/ 项目简介与三条可复制资产 /
    6 项关键数据（312 条验证数据、37.3% 行为支付率、¥8.6 地推 CAC、22 台 B 端首单、2,886 台保本、L4 能力等级）/
    四步闭环（洞察-假设-验证-迭代）/ 盈利链条（BOM→定价→毛利→获客→保本）+ 三档路径与底线 /
    创客训练效果（含 9 处自纠错）/ 开源学习包
    - 规格：2480×3508（A4 @300dpi），可直接打印；照片位留占位符未编造素材
    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
2026-10-08 feat(demo): 重做汇报 PPT（11 页）——聚焦开源项目的获客逻辑与盈利链条
    按课程定位重做（旧版叙事不合要求，已归档）：
    - 核心：一个开源项目的获客逻辑 + 盈利链条（不是技术介绍、不是训练营流程罗列）
    - 训练痕迹＝思维转变：从「用技术看能做什么」到「思考怎么获客、怎么用客流反哺技术与项目」；
    点了老师点拨（技术商品需要客流才能活下去）→ 决定做成开源项目
    - 展示内容：我们走过的过程（发现需求→试产→跑渠道→拿订单→决定开源）+ 未来可盈利的信心
    页面（11 页）：封面主张「把技术开源，把客流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
